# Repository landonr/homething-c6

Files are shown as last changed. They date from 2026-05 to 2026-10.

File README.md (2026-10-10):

<p align="center">
  <picture>
    <source media="(prefers-color-scheme: dark)" srcset="docs/readme-assets/homeThingLogoWhite.svg">
    homeThing logo
  </picture>
</p>

<h1 align="center">homeThing C6</h1>

<p align="center">
  A handheld remote for TV, Sonos, Zigbee lights, and Home Assistant.<br>
  Physical buttons, a rotary control, fast access, and long idle life. No touchscreen, no apps, no daily charging.
</p>

<p align="center">
  
  
  
  
</p>

<p align="center">
  <sub>Prototype and fab costs sponsored by <a href="https://pcbway.com/g/Xymq6O">PCBWay</a>. Boards arrive fully assembled, no soldering required.</sub>
  <br>
  <a href="https://pcbway.com/g/Xymq6O">PCBWay</a>
</p>

## Summary

- **Case:** The [`case/` README](case/README.md) documents the enclosure files and assembly information.
- **Board:** The [`c6remote-kicad/` README](c6remote-kicad/README.md) documents the KiCad hardware source.
- **Firmware:** The [firmware section](#firmware) documents the ESPHome configuration and local components.
- **Scripts:** The [`scripts/` README](scripts/README.md) documents project utilities and generated assets.

The prototype uses a Seeed Studio XIAO ESP32-C6.

### Features

- Control a TV with on-board IR receive and transmit hardware
- Drive music playback over Wi-Fi and BLE
- Switch lights over Zigbee, Thread, or Matter
- Map Home Assistant actions to physical buttons instead of app screens
- Assign every button from a web page on the remote itself
- Run for a long time between charges

## Case

<p align="center">
  <picture>
    <source media="(prefers-color-scheme: dark)" srcset="docs/readme-assets/remote-controls-annotated-dark.svg">
    Front of the assembled c6remote with labels for the microphone, scroll wheel and 5-way control, RGB status LEDs, 11 assignable buttons, the XIAO ESP32-C6 module with Zigbee, Wi-Fi, and BLE radios, and USB-C port.
  </picture>
  <picture>
    <source media="(prefers-color-scheme: dark)" srcset="docs/readme-assets/remote-back-annotated-dark.svg">
    Back of the assembled c6remote with labels for the IR emitter, the IR receiver window, the translucent enclosure, and the 800 mAh battery, which lasts about a month per charge.
  </picture>
</p>

<p align="center">
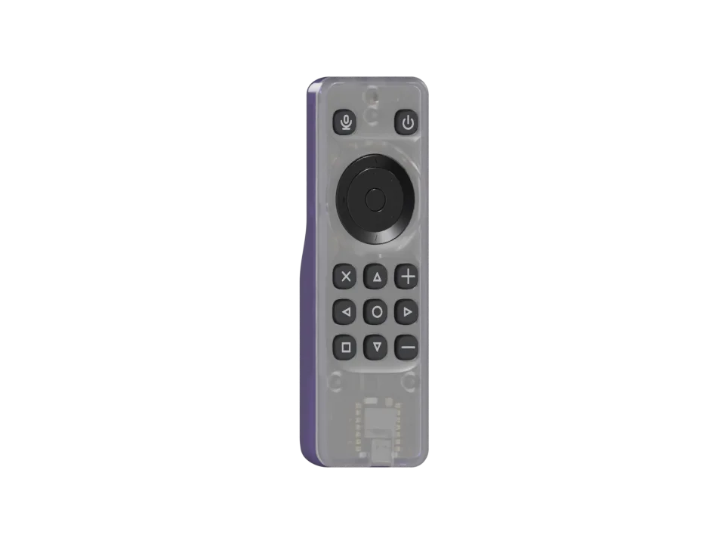
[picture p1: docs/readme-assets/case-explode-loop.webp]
The case, the pad, and the main board parts come apart. The exploded remote turns once, and then the parts go back together. The status LEDs play the boot animation
  
</p>

## Board ([more info](c6remote-kicad/README.md))

### PCB and hardware

<p align="center">
  <picture>
    <source media="(prefers-color-scheme: dark)" srcset="docs/readme-assets/board-front-annotated-dark.svg">
    Front of the c6remote board. Labels identify the ANO rotary encoder, RGB status LEDs, tactile switches, GPIO expander, and XIAO ESP32-C6 module.
  </picture>
  <picture>
    <source media="(prefers-color-scheme: dark)" srcset="docs/readme-assets/board-back-annotated-dark.svg">
    Back of the c6remote board. Labels identify the IR emitter, I2S microphone, IR receiver, 800 mAh LiPo battery, and battery connector.
  </picture>
</p>
<p align="center"><sub>PCB front and back</sub></p>

<p align="center">
  Flat copper top view
  Flat copper bottom view
</p>
<p align="center"><sub>Copper top and bottom</sub></p>

| Ref | Part | Role |
| --- | --- | --- |
| `U1` | [Seeed Studio XIAO ESP32-C6](https://mm.digikey.com/Volume0/opasdata/d220001/medias/docus/8932/102010636.pdf) | Main module: Wi-Fi, BLE, Zigbee/Thread |
| `MK1` | [DMM-4026-B-I2S-R I2S microphone](https://api.puiaudio.com/filename/DMM-4026-B-I2S-R.pdf) | Audio input: PUI Audio bottom-port MEMS part on the back copper, hearing through a 0.5mm NPTH. `LR` and `CONFIG` tie to ground for left-channel output, `C5` decouples VDD and `R12` pulls `sd` down. It replaced the ICS-43434 on 2026-09-07, after three of the five rev-B microphones failed |
| `U2` | [TSOP6136 IR receiver](https://www.vishay.com/docs/82457/tsop61.pdf) | IR receive: Vishay Panhead SMD part on the back copper, listening out the top end wall. AGC1, the most permissive of Vishay's settings, which is what lets `remote_receiver` learn arbitrary remotes. VDD sits on the switched `ir_vdd` rail rather than straight on `+3.3V`, gated by `Q3` below |
| `D1`, `Q1` | [INL-3AHIR30 IR LED](http://www.inolux-corp.com/datasheet/IR/Emitter/3mm%20Lamp/INL-3AHIR30_V1.0.pdf) driven by [MMBT2222A](https://assets.nexperia.com/documents/data-sheet/MMBT2222A.pdf) | IR transmit; D1 leads hand-bent 90° to fire through the top-edge notch (see `BEND 90°` silk mark) |
| `U3` | [PCF8575DBR I2C GPIO expander](https://www.ti.com/lit/ds/symlink/pcf8575.pdf) | Button input fan-out |
| `SW1`–`SW11` | [TL3315NF160Q tactile switches](https://www.e-switch.com/wp-content/uploads/2022/06/TL3315.pdf) | Discrete buttons |
| `ENC1` | [Adafruit ANO rotary encoder](https://cdn-learn.adafruit.com/assets/assets/000/104/942/original/tsw.pdf) | Scroll wheel: encoder channels plus five switch signals |
| `D2`–`D5` | [XL-2020RGBC-WS2812B addressable LEDs](https://mm.digikey.com/Volume0/opasdata/d220001/medias/docus/8903/5962_XL-2020RGBC-WS2812B.pdf) | Status light chain of 4, WS2812B protocol: `GPIO17` drives `D2` DIN, DOUT cascades to `D5`. VDD sits on the switched `led_vdd` rail rather than straight on `+3.3V`, gated by `Q2` below, with `C4` as the only bulk cap on the chain (see [`docs/timeline.md`](docs/timeline.md)) |
| `Q2`, `R10`, `C4` | [AO3401A P-channel MOSFET](https://www.aosmd.com/res/datasheets/AO3401A.pdf), 1M 0603 pull-up, 1µF X7R 0805 cap | LED rail load switch: high-side `Q2` gates `+3.3V` (source) onto `led_vdd` (drain) for `D2`–`D5`, gate net `led_en` on `U1` pad 11 (`GPIO18`/`D10`), driven low for rail on. `R10` pulls the gate to the source so the rail is off by default at boot while `GPIO18` floats as an input; `C4` is the mid-chain bulk cap on `led_vdd`. Cuts the ~2.0mA the LEDs burned when dark to tens of µA (calculated, not yet measured). Firmware must hold `GPIO17` low or high-impedance whenever the rail is down, or DIN pushes current into the dead rail |
| `J1` | [JST S2B-PH-SM4-TB(LF)(SN)](https://www.jst-mfg.com/product/pdf/eng/ePH.pdf) | Battery connector, PH series right-angle SMD |

The auto-generated BOM lives at [c6remote-kicad/export/c6remote-bom.csv](c6remote-kicad/export/c6remote-bom.csv). It tracks the latest repo state and is not release-validated.

### Schematic

Current schematic

## Firmware

### Button assignment

Open `http://homething-c6-xxxxxx.local/` in a browser on the same network. The page also answers at `/buttons`.
`xxxxxx` is the last six hex digits of the remote MAC address. Home Assistant shows the remote as `homeThing C6 xxxxxx`.
The page draws the remote layout. Select an input, then assign IR, Zigbee, BLE HID, or voice.
You can also clear the input. Hold `SW1` for two seconds to use the on-device assignment mode.
[`RECEIVER.md`](RECEIVER.md) documents both routes. The page has no password, so use it only on a trusted network.

<p align="center">
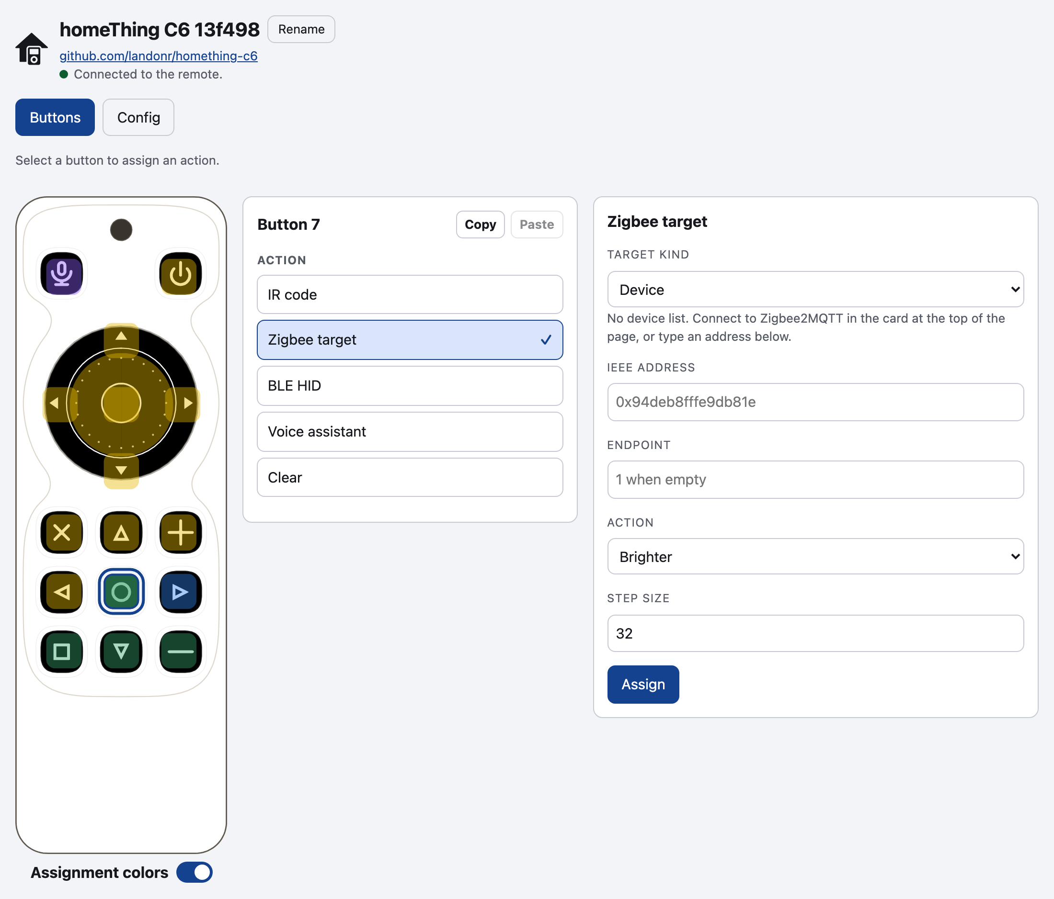
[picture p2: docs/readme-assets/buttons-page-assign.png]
The Buttons tab. Button 7 is selected and set to a Zigbee target
  
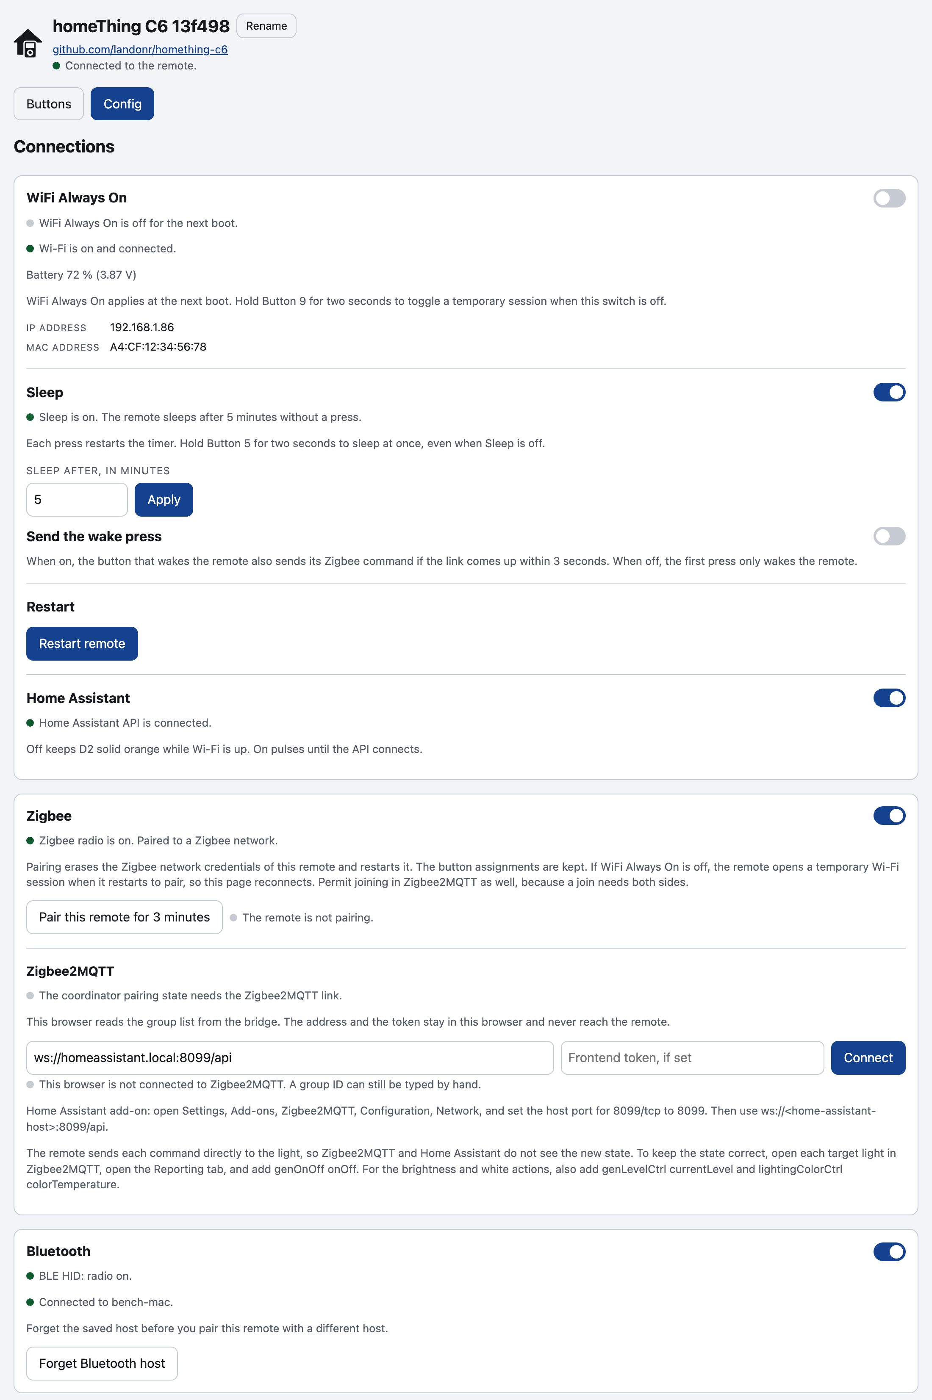
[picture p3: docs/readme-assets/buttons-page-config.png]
The Config tab with the Wi-Fi, sleep, Home Assistant, Zigbee, and Bluetooth settings
  
</p>
<p align="center"><sub>The Buttons tab with a Zigbee assignment, and the Config tab</sub></p>

## Status

The fabrication and bring-up history, the rev-B delivery, and the unit 1 versus current design comparison are in [`docs/timeline.md`](docs/timeline.md). Open work is in [`ROADMAP.md`](ROADMAP.md). The power budget is in [`docs/power-budget.md`](docs/power-budget.md).

## Relationship to homeThing

This project grew out of [homeThing](https://github.com/landonr/homeThing) but has a narrower job: instead of a general smart display, it is a simple dedicated remote. It has no screen and more buttons, and is built on a custom PCB that is easy to build.

# Includes
- <a href="https://esphome.io/">ESPHome</a>
- <a href="https://dejavu-fonts.github.io/">DejaVu Sans Bold</a>, used for the board silkscreen brand text
- [@luar123](https://github.com/luar123)'s <a href="https://github.com/luar123/zigbee_esphome">Zigbee ESPHome component</a>
- <a href="https://www.kicad.org/">KiCad</a>
- <a href="https://github.com/landonr/homeThing">homeThing</a>

# Sponsorship



## [PCBWay](https://pcbway.com/g/Xymq6O "PCBWay") sponsors 3D Printing and PCB assembly costs on this project during the prototyping phase! 
If you are interested in their awesome fabrication services please check them out.&nbsp; They offer 

3D prototyping,&nbsp;PCB design and assembly, as well as CNC metal fabrication.&nbsp; Costs are reasonable and the quality is as good as it gets.&nbsp; Thank you PCBWay for sponsoring us and other fun projects!<br><br>

## [cargo](https://cargo.site/ "cargo.site") sponsors our website!

They make it super easy to keep things pretty and up to date! It’s honestly so much easier than managing our own site, highly recommended!

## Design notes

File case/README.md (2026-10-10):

# Case

This directory contains the parametric enclosure model for the c6remote board.
The model uses [build123d](https://build123d.readthedocs.io/), so the source is Python.

<p align="center">
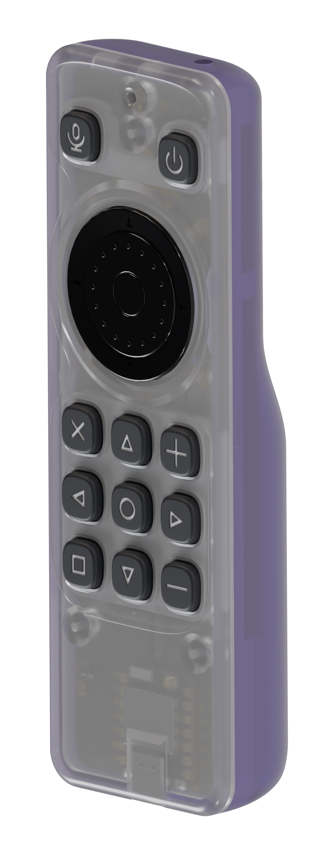
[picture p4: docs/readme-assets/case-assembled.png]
Assembled c6remote case
  
</p>
<p align="center"><sub>Assembled case</sub></p>

<p align="center">
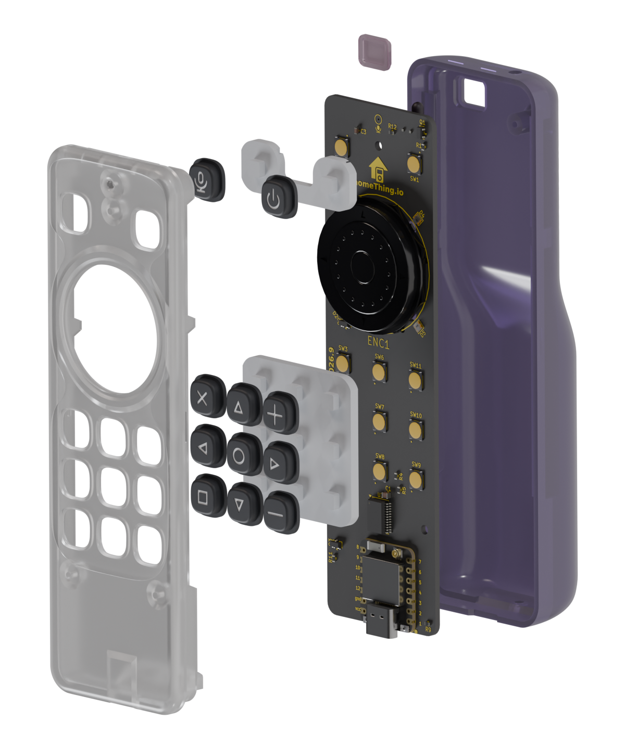
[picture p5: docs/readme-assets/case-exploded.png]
Exploded c6remote case
  
</p>
<p align="center"><sub>Front shell, caps, button pad, board, and back shell</sub></p>

<p align="center">
  The c6remote case, the pad, and the main board parts come apart. The exploded remote turns once, and then the parts go back together
</p>

The model exports a front shell, back shell, soft button pad, IR window insert, and 11 rigid caps. It also exports a blank version of each cap, `c6remote-cap-sw<n>-blank.stl`, with no legend.
It also exports an FDM button pad with all keytops and legends fused into one STL.
It also exports a second front shell for a filament printer. Read [FDM front](#fdm-front).
It also exports the V2 top pads, an FDM one and a one-piece TPU one, for a V2 board. Read [V2 retention post](#v2-retention-post).

## Setup

Run these commands from the repository root:

```bash
cd case
uv venv --python 3.12 .venv
uv pip install --python .venv/bin/python -r requirements.txt
```

## Build and validate

Run these commands from the repository root:

```bash
scripts/export-case-refs.sh
case/.venv/bin/python case/board.py
case/.venv/bin/python case/case.py
case/.venv/bin/python case/check.py
```

Use a scoped check during development:

```bash
case/.venv/bin/python case/check.py --only ir
case/.venv/bin/python case/check.py --only support,shells
```

Run the full check before you accept a case change. A scoped check does not validate the full model.

Run independent feature groups in parallel when two or more groups are selected:

```bash
case/.venv/bin/python case/check.py --jobs 4
case/.venv/bin/python case/check.py --only ir,support --jobs 2
```

Use `--quiet` for failures, provenance, counts, and the scoped-run warning. Use `--timings` to print pass durations.

Every run also writes `export/c6remote-checks.json`: the same report in machine form, with each failure's own point or box in the case frame where the pass recorded one. Use `--json PATH` to write it somewhere else. The c6remote-explode viewer reads that file and draws the failures on the model, so a scoped run writes only the features it ran and marks itself scoped.

A pass says where a failure is by appending a `checks.common.Problem` instead of a plain string; a plain string still reports, it just cannot be drawn.

Use this command to preview the model:

```bash
case/.venv/bin/python case/case.py --show
```

The preview requires `ocp-vscode`:

```bash
uv pip install --python case/.venv/bin/python ocp-vscode
```

Without `ocp-vscode`, use the exploded viewer instead:

```bash
../c6remote-explode/preview-case.sh
```

That script lives in the viewer checkout. It builds the STL files, copies them into the viewer's draft geometry set, and opens the viewer.
It omits the feature map and the summary, so a draft build takes about 6 seconds on a warm cache.

## Board inputs

Do not copy a board coordinate into the case model. Add a reader to `board.py` instead.

The model reads these sources:

- `c6remote-kicad/c6remote.kicad_pcb` supplies the outline, mounting holes, courtyards, wheel center, and microphone port.
- `c6remote-kicad/export/c6remote-pos.csv` supplies component positions.
- `case/board/c6remote-board.step` supplies component bodies, keepout heights, and connector geometry.
- `case/board/c6remote-board-only.step` supplies the board solid.
- `case/board/c6remote-outline.dxf` supplies the exported outline.
- `case/board/c6remote-v2-board-only.step` supplies the fixed V2 mounting-hole reference.
- `case/board/c6remote-v2-pos.csv` supplies the fixed V2 switch positions.

Run `scripts/export-case-refs.sh` after a relevant schematic or board change. Then build and run the full check.

Do not regenerate `case/board/c6remote-v2-board-only.step` or `case/board/c6remote-v2-pos.csv`. Both are static references from release `2026.8.0`, commit `d0a2c2e`.

## Coordinate frame

The X axis is the KiCad board X axis. The Y axis is the negative KiCad board Y axis.

The Z origin is the bottom face of the board. Positive Z points toward the front shell.

The position CSV already contains the negative Y coordinates. Do not apply a second Y transformation.

## Parameters

Put all adjustable geometry values in `params.py`. Give each value a short rationale in its docstring.

The model derives geometry from the board where possible. Manual values include switch travel, switch height, print fits, and material thicknesses.

`SWITCH_HEIGHT` and `SWITCH_TRAVEL` are not measurements. Measure a physical TL3315 before the first production print.

## Materials

Print the shells with a tinted translucent filament. The STL files contain no color or material data.

The IR window material must transmit 940 nm infrared light. Test the selected filament with a physical remote.

If the shell filament blocks too much infrared light, make the same insert from IR-pass acrylic.

Prototype the button pad in TPU. Use translucent silicone for a molded part.
The molded pad has a skirt on the outer edge of each lobe. The skirt is `PAD_SKIRT_T` wide and its bottom is level with the plunger contacts, so the pad stands level on the plungers and the skirt.
The skirt has a break over each board part that it would otherwise touch. `PAD_SKIRT_CLEARANCE` sets the gap.
The molded pad and the one-piece TPU pad have a plain web without isolation grooves. Only the FDM pad has grooves.

`c6remote-case-pad-tpu.stl` goes with the recessed front `c6remote-case-front.stl`. Print it in TPU as one piece in place of the TPU pad and the PETG caps. Do not install separate caps with it.

For keytops with no legend, print `c6remote-case-pad-tpu-blank.stl` in place of `c6remote-case-pad-tpu.stl`.
It is the FDM pad with the same skirt as the molded pad. It has no edge chamfer, because TPU flexes on its own. Its grid web is a plain slab with square edges.

Print the caps in translucent PETG or PLA. Either orientation works. For a key with no legend, print `c6remote-cap-sw<n>-blank.stl` in place of `c6remote-cap-sw<n>.stl`. The blank cap has the same fit.

The cap flange rests on the pad web, so a press moves the cap and the web together. `CAP_LIFT` sets any air under the flange.

Top faces against the build plate gives the best finish. Top faces up needs support on the top faces. Trim the support marks after the print.

For a rigid FDM button set, print `c6remote-case-pad-fdm.stl`. It includes the
two pad lobes and all 11 keytops in one STL. Each keytop is flush with its lobe
web. Do not install separate caps with it.

Print the FDM pad in either orientation. The STL exports with the keytops up.

Keytops down puts the keytop faces on the plate. The pad then stands on 523 mm2.

Keytops up puts the pad on the keytop stems. The pad then stands on 26 mm2. Use a brim and a clean plate. Set the support roof density to 80 percent, or the web sags into the support. Trim the support marks after the print.

The FDM pad cuts its isolation grooves from the keytop side only. As a result, the web underside is flat, and the supports for a keytops-up print come off easily.

The chamfer on both lips of each groove and on the grid lobe outer top edge runs down to the groove floor, set by `FDM_PAD_GRID_CHAMFER`.

If you print keytops down, the grooves face the support. Then the supports fill the grooves and are hard to remove.

## FDM front

The export contains two front shells. Both shells have the same interior, so the caps, the pad, and the back shell fit either one.

`c6remote-case-front.stl` is the recessed front. Its face carries a shallow dish around the keys and around the wheel.

`c6remote-case-front-fdm.stl` is the FDM front. Its face is one flat plane and carries the same dish outline as a shallow groove.

Use `c6remote-case-pad-fdm.stl` with this front. The keytops have no captive
flanges, so install this pad from inside before the board. The face holes guide
the integrated keytops with `FDM_CAP_GUIDE_CLEARANCE` on each side.

Print a front shell with its face against the build plate. A filament printer cannot make the dish in this orientation.

The dish floor is a wide, almost horizontal ceiling a fraction of a millimetre above the plate. The printer must support it.

Support under the face marks the one cosmetic surface on the case. The other orientation stands the whole cavity on its ceiling.

The groove is narrow, so the layer above it bridges the gap in one span. The FDM front needs no support on its face.

The FDM front's face sits `FDM_FACE_DROP` below the recessed front's, so the part is slimmer than a flat face at the raised level.

The caps and the wheel stand proud by that much. The recessed front stands its caps proud of the dish by `CAP_PROTRUSION` plus the local dish depth.

The drop thins three ceilings that the dish never reaches. The USB pocket roof is the tight one, and `check.py --only fdm` holds all three.

The USB pocket roof and the USB slot roof are flush, at the connector envelope plus `USB_CLEARANCE`. Do not raise one without the other.

The groove follows the dish rim exactly. The outline on the two fronts is the same line.

The FDM front has a 0.64 mm, 45 degree top-edge chamfer. The recessed front keeps its round.

The rim runs inside the recessed front's round. The FDM front keeps its groove on flat face outside the chamfer.

`FDM_FACE_DROP`, `FDM_OUTLINE_W`, `FDM_OUTLINE_DEPTH`, `FDM_OUTLINE_EDGE_CLEAR`, and `EDGE_R_FRONT_FDM` set the face. The LED ring channel is half-depth on this front, leaving a thicker printable roof. Run `check.py --only fdm` to validate it.

## Assembly

The front shell holds the board. Three M2 screws fasten the V3 board to its bosses.

The back lap closes over the front skirt. Two detents secure the IR end.
Two hidden side catches keep the long seams closed near the board midpoint.
Their front-skirt pockets are blind, rounded, and bevelled at the mouth, with
continuous material behind them. The seam sits above the board top.
Each pocket sits a short lower lip above the front skirt's support relief, so a long solid skirt land stays above each catch.
The support relief stands `SUPPORT_SKIRT_FIT` above the ledge tops, so the front skirt never lands on a ledge. The seam shoulder is the only vertical stop.
The back detents ramp on both sides so the shells can be opened for service.
Each back detent sits lower than its pocket and bears on the lower lip with a light preload.
The preload holds the seam closed.
`SIDE_CATCH_LOWER_LAND` sets the lower lip height, and `SIDE_CATCH_PRELOAD` sets the preload.

One M2 x 6 screw secures the grip end. It enters horizontally through the back shell's negative Y end wall and threads into a block behind the front skirt. The case uses four M2 x 6 screws in total and no long screw.

Prepare the back shell first:

1. Insert the IR window from inside the back shell.
2. Make the pane flush with the outside surface.
3. Apply adhesive to the continuous shoulder below the interior flange.
4. Let the adhesive set.

Assemble the remaining parts with the front face down:

1. Install all caps in the front shell.
2. Install the button pad.
3. Put the board on the front-shell bosses.
4. Install the three M2 screws through the board into the front-shell bosses.
5. Engage the two IR-end detents.
6. Fold the back shell onto the front shell.
7. Install the end-wall M2 screw at the grip end.

Install the caps before the pad. The caps are captive after pad installation.

For the FDM pad, omit step 1 and install `c6remote-case-pad-fdm.stl` in step 2.

Install the IR window before shell assembly. Its flange is not accessible after shell assembly.

## V2 retention post

The back shell includes one retention post for a V2 board. The post uses the V2 upper-right mounting hole.

This post supplies retention only. It does not make the V2 board compatible with the V3 case.

The V2 IR parts and upper keys do not align with the current openings. Use this feature only as a bench aid.

For a V2 board, fasten the board to the back shell first. Drive the M2 screw from the component side without a washer.

The V2 board sits on the post, `SUPPORT_GAP` lower than the V3 board. Its SW1 and SW2 also sit nearer the grip end.

For a V2 board, print `c6remote-case-pad-fdm-v2-top.stl`. Use it in place of the SW1 and SW2 lobe of `c6remote-case-pad-fdm.stl`.

The V2 top pad keeps the V3 SW1 and SW2 plungers. It adds one nib above each V2 switch.

Each nib extends `LEGACY_NIB_EXTENSION` below the V2 switch top. The kept V3 plungers use the same extension below the V3 switch top, so they stop above the nibs.

The SW1 and SW2 keytops of the V2 top pad stand level with the other keys.

Use the V2 top pad only with a V2 board. On a V3 board, the nibs land on the V3 switch bodies.

For the one-piece TPU pad on a V2 board, print `c6remote-case-pad-tpu-v2-top.stl`. On a V2 board, it replaces the SW1 and SW2 lobe of `c6remote-case-pad-tpu.stl`. Use it with the recessed front `c6remote-case-front.stl`.

`c6remote-case-pad-tpu-v2-blank.stl` is a complete V2 pad with blank keytops in one STL. Print it alone, with the recessed front `c6remote-case-front.stl`.

Its skirt ends level with the skirt of `c6remote-case-pad-tpu.stl`, so both lobes stand on one plane. Its skirt breaks come from the V3 part bodies, moved to the V2 placements, and from the V2 screw head.

For the moulded pad with separate caps on a V2 board, print `c6remote-case-pad-v2-top.stl`. Use it in place of the SW1 and SW2 lobe of `c6remote-case-pad.stl`, with the standard caps and the recessed front `c6remote-case-front.stl`. Its stems stay at the V3 SW1 and SW2 positions, so the standard caps fit it unchanged.

Print the FDM V2 top pad with the keytops down. The nibs extend below the plungers, so the part cannot stand level on its plungers.

On the first print, make sure that SW1 and SW2 operate and do not bind. Each V3 plunger overlaps the edge of a V2 switch body.

`SWITCH_HEIGHT` is also not a measurement, so the nib engagement is not confirmed.

## IR openings

`U2` receives infrared light through the back face along negative Z. Its opening includes the receiver body and lead envelope.

The IR window insert enters this opening from inside. Its exterior pane must be flush with the back shell.

`D1` emits through the positive Y end wall. The emitter uses a separate bare bore.

## Functional constraints

- Keep the button caps captive behind the front-shell ceiling.
- Keep the button pad clear of the wheel and the four wheel LEDs.
- Keep the pad skirt clear of board parts.
- Keep the LED ring channel open below its translucent roof.
- Keep the microphone funnel aligned with the board port.
- Keep the USB slot and pocket clear of the connector shell.
- Keep support ledges clear of board parts, screw heads, and the cell.
- Keep the front skirt clear above the support ledge tops.
- Keep the end screw block clear of the back shell. Its web ties it to the end skirt and the side skirt at skirt height only.
- Keep the IR window shoulder continuous for adhesive.
- Keep the front and back shell mating volumes separate. The side catch preload is the only exception. The checks allow this overlap only at the lower pocket lip.

The checks must probe built geometry. A check must not only repeat the formula that creates the feature.

After a loft or sweep change, inspect the exported STL. A valid BREP can still produce a damaged mesh.

## Validation

`check.py` validates these groups:

- Apertures and end ports
- Button caps, legends, pad fit, and switch contact
- Wheel clearance and the LED light path
- Microphone and USB geometry
- IR receiver clearance and window installation
- Board supports, screws, cell clearance, V2 retention, and the V2 top pad
- Shell mating and component interference
- FDM front face flatness, height, top edge round, and outline groove
- Solid validity and closed STL meshes

Run the full validation before export:

```bash
case/.venv/bin/python case/check.py
case/.venv/bin/python case/case.py
```

The model writes STLs and metadata to `case/export/`. `case.py` prints current dimensions and screw lengths.

If the exported assets change, push them into the external viewer:

```bash
../c6remote-explode/preview-case.sh --full
```

That script builds again on the warm cache and copies the result into the viewer's draft geometry set.
Its `--baseline` mode rebuilds the committed geometry that the viewer's diff view compares against.

## Development rules

Use the public build123d API. Do not use raw OCP objects unless build123d has no equivalent.

When you add a check, change a related parameter temporarily. Confirm that the new check fails with a useful message.

For a refactor, compare the full check output and exported artifact hashes before and after the change.

The STL cache absorbs one known nondeterministic tessellation result in the back shell. Use `CASE_NO_CACHE=1` only when necessary.

## Files

| Path | Purpose |
| --- | --- |
| `params.py` | All adjustable geometry values |
| `board.py` | Readers for KiCad and board export geometry |
| `case.py` | Thin build and export entry point |
| `check.py` | Thin validation entry point |
| `cache.py` | Geometry and STL cache |
| `model/` | Case feature builders and export metadata |
| `checks/` | Validation modules for built geometry |
| `fonts/` | Vendored legend font and license |
| `glyphs/` | SVG legend centerline strokes |
| `board/` | Generated board references and the fixed V2 reference |
| `export/` | Generated STLs and JSON metadata |

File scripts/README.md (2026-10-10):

# Scripts

## Draft preview in 3D

Run this command from the repository root to see the current case model in the exploded viewer:

```bash
../c6remote-explode/preview-case.sh
```

The script lives in the viewer checkout. It builds the STL files, copies them into the viewer, and opens it.
If the viewer already runs, the script says so. Reload the tab.

The default build is a draft. It skips the feature map and the summary.
As a result, Identify reports the boxes from the last complete build.
Use `../c6remote-explode/preview-case.sh --full` to write the feature map again.

Both of those builds read the working tree. They write the draft geometry set.
Use `../c6remote-explode/preview-case.sh --baseline` to rebuild the committed geometry that the viewer's diff view compares against.
That mode builds git HEAD in a temporary worktree. It does not touch the working tree.

Run `scripts/export-case-refs.sh` first after a board change.
The script reads the board exports, but it cannot detect a KiCad change.

Set `REPO` for a board checkout outside `~/dev/homething-c6`.
Set `PORT` for a server port other than 8731.

## Preview assets

Run these commands from the repository root to regenerate the case preview assets:

```bash
./scripts/render-readme-assets.sh
../c6remote-explode/scripts/render-case-assembled.sh --blender
../c6remote-explode/scripts/render-case-exploded.sh --blender
../c6remote-explode/scripts/render-case-explode-loop.sh
```

Every 3D render uses Blender's Cycles.
`render-readme-assets.sh` needs Blender. Set `BLENDER` to override the binary path.
It exports a board GLB from the PCB and renders the two `board-3d-rotated-*.png` views with `scripts/render-board-blender.py`. It writes them into `docs/readme-assets/`.
`scripts/board_extras.py` builds the J1 socket, the battery plug, and the battery for the Blender scripts. The `c6remote-explode` repository also uses it.
`scripts/assets/env-studio.hdr` is the Poly Haven `studio_small_09` HDRI at 1k. Its license is CC0.
The three case scripts use the sibling `c6remote-explode` checkout. Set `C6REMOTE_EXPLODE` if that checkout is not at `../c6remote-explode`.
The case scripts need Node, `ffmpeg`, and `img2webp` (`brew install webp`) as well. They render the case geometry the viewer has, so run `../c6remote-explode/refresh-assets.sh` after a case or board change.
Add `--rig` to a case script to render on the Windows Rig over SSH.
The case scripts write dated files into `c6remote-explode`; copy them into `docs/readme-assets/` as `case-assembled.png`, `case-exploded.png`, and `case-explode-loop.webp`.

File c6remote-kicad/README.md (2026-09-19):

# KiCad project

## Open the project

Open `c6remote.kicad_pro` in KiCad.
KiCad must resolve `../kicad lib/Library.pretty/` with the `Library` nickname.

The `sym-lib-table` file registers these symbol libraries:

- `ano rotary`: The local `ano rotary.kicad_sym` file contains the [Adafruit ANO rotary encoder](https://www.adafruit.com/product/5001) symbol.
- `Seeed_Studio_XIAO_Series`: [Seeed Studio's OPL KiCad library](https://github.com/Seeed-Studio/OPL_Kicad_Library/tree/master/Seeed%20Studio%20XIAO%20Series%20Library) supplies the XIAO module symbols.

The `3dmodels/` directory contains the board models.
See the [3D model sources](3dmodels/README.md) for the source of each file.

## KiCad MCP

The repository uses the same KiCad MCP server with Codex and GitHub Copilot in VS Code:

- Codex workspace configuration: `../.mcp.json`
- VS Code workspace configuration: `../.vscode/mcp.json`

## Validation and fabrication

### Schematic-only agent workflow

Run this workflow from the repository root.
Use a unique session name for each schematic or custom-footprint edit loop.
The PCB must remain unchanged between `preflight` and `verify`.

```bash
./scripts/hw.py doctor
./scripts/hw.py preflight my-edit

# Inspect the baseline before an edit.
./scripts/hw.py inspect my-edit component U3
./scripts/hw.py inspect my-edit net sda
./scripts/hw.py inspect my-edit pin U3 14

# Run after every schematic or custom-footprint edit.
./scripts/hw.py quick my-edit

# Inspect the refreshed state and all baseline changes.
./scripts/hw.py inspect my-edit changes

# Run once before handoff.
./scripts/hw.py verify my-edit
./scripts/hw.py clean my-edit
```

Native KiCad ERC is authoritative.
Semantic analysis detects topology, BOM, metadata, findings, and custom-footprint regressions.

Use `--json` with `inspect` for stable structured output.
Use `--force` with `quick` or `inspect` to bypass reusable analysis.

Session artifacts stay in `.cache/hw/<session>/`.
The `preflight` command does not replace an existing session.
Reuse one session for repeated `inspect` and `quick` commands.
The session keeps its original baseline until you run `clean`.
If a session is old or incomplete, run `clean` and `preflight` again.

The tool refreshes stale inspection data before it prints results.
It reuses validated analysis and changed-footprint data when all fingerprints match.
It does not reuse failed or incomplete output.
It rejects simultaneous operations on one session.

The tool resolves `kicad-cli` from `KICAD_CLI`, `PATH`, or the macOS application bundle.
It resolves the analyzer from `KICAD_HAPPY_DIR`, shared, Codex, or Claude skill locations.
An invalid override stops discovery.
The `doctor` command prints each selected path.
The analyzer must emit schema 1.4.x.

If the analyzer is missing or incompatible, move or remove its existing destination.
Then install the pinned version:

```bash
python3 "${CODEX_HOME:-$HOME/.codex}/skills/.system/skill-installer/scripts/install-skill-from-github.py" --repo aklofas/kicad-happy --ref v2.2.0 --path skills/kicad
```

Exit code `0` means pass.
Exit code `1` means a design regression.
Exit code `2` means a tooling or configuration failure.

A PCB change makes `quick` and `inspect` fail before analysis starts.
The message explains that the session cannot validate PCB edits.
The `quick` command blocks only new deterministic analyzer errors.
The `verify` command always runs fresh native checks and stores outputs in the session cache.

### Native checks

Run these commands from this directory:

```bash
# Schematic ERC
/Applications/KiCad/KiCad.app/Contents/MacOS/kicad-cli sch erc c6remote.kicad_sch --exit-code-violations

# Board DRC
/Applications/KiCad/KiCad.app/Contents/MacOS/kicad-cli pcb drc c6remote.kicad_pcb --exit-code-violations

# Full board DRC with schematic parity and zone refill
/Applications/KiCad/KiCad.app/Contents/MacOS/kicad-cli pcb drc c6remote.kicad_pcb --schematic-parity --refill-zones --exit-code-violations
```

### Fabrication outputs

Regenerate all Gerber, drill, position, and BOM files in `export/`:

```bash
../scripts/regen-fab.sh
```

Regenerate only the BOM after you edit symbol sourcing fields:

```bash
../scripts/export-bom.sh
```

Use this script instead of the KiCad MCP `export_bom` tool.
The MCP tool uses a different schema and removes the custom sourcing columns.

### Board renders

Render reusable 2D board views in `renders/<format>/`:

```bash
../scripts/render-2d.sh
../scripts/render-2d.sh --side top
../scripts/render-2d.sh --side bottom --format pdf
```

### Interactive BOM

Generate the interactive HTML BOM for the pre-fabrication pin-1 check:

```bash
../scripts/gen-ibom.sh
```

The command writes the ignored `ibom.html` file in this directory.
The pre-commit hook also updates it when you stage `c6remote.kicad_pcb`.

Complete the [pre-fabrication checklist](../docs/pre-fab-checklist.md) before you order a board.

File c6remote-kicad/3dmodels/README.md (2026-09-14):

# 3D model sources

Models the project footprints reference through `${KIPRJMOD}/3dmodels/`. Every file's origin, so a replacement starts from the same source rather than a guess.

- `5221 ANO Rotary Encoder.step`: [GrabCAD, Adafruit 5001 ANO Rotary Encoder](https://grabcad.com/library/adafruit-5001-ano-rotary-encoder-1). The source assembly includes a PCB. This file keeps only the `Encoder` solid so the board does not sit inside the c6remote PCB.
- `DMM-4026-B-I2S-R.STEP`: user-provided PUI Audio model from `DMM_4026_B_I2S_R (1).zip`, received 2026-09-07. The bottom footprint uses X=270, Y=0, and Z=180 degrees so the package projects away from the PCB.
- `Seeed Studio XIAO ESP32-C6.step`: [GrabCAD, Seeed Studio XIAO ESP32-C6](https://grabcad.com/library/seeed-studio-xiao-esp32-c6-1).
- `TL3315NF160Q.wrl`: modelled for this repo from the E-Switch TL3315NF160Q datasheet drawing (4.5 x 4.5 x 0.55 gold snap dome), replacing a wrong 5mm PTS647 model; see commit 8757cb5.
- `TSOP6136.step`: Vishay doc 82826, re-exported already rotated into place, so the footprint's `offset` and `rotate` are all zero on purpose; do not "fix" them.
- `TSOP6136TT.step`: derived from the checked-in Vishay doc 82826 `TSOP6136.step`, rotated into the TT top-view attitude. Lead bend is approximate; body envelope is exact. Footprint offset and rotation stay zero.
- `WS2812C-2020.step`: [Printables model 1760436, WS2812B-2020 / WS2812C-2020](https://www.printables.com/model/1760436-ws2812b-2020-ws2812c-2020). Stands in for the XL-2020RGBC-WS2812B on D2-D5, same 2.0 x 2.0 package; the KiCad stock library carries no 2020-size WS2812 model.

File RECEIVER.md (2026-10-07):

# Assignment mode

## Goal

Assignment mode gives each supported input one active action. An action can be
an IR code, a Zigbee command, a BLE HID control, the voice assistant, or no action.

Store assignments in flash. Outside assignment mode, an input replays its active
action.

## Enter and leave the mode

Hold `SW1` for two seconds to enter assignment mode. Hold `SW1` for two seconds
again to leave it.

The ready state closes after five seconds without an input.

The release that ends an `SW1` hold does not count as a tap.

## Assignment cycle

For `SW2`, `SW3` through `SW11`, and the five wheel directions, tap the same
input in this order:

1. First tap: train an IR code.
2. Second tap: assign the voice assistant.
3. Third tap: clear the input.

For `SW1`, tap the same input in this order:

1. First tap: train an IR code.
2. Second tap: clear the input.

`SW1` has no voice stage because its hold gesture controls assignment mode.

The cycle has no Zigbee stage. A Zigbee target comes from Zigbee2MQTT, which
the remote cannot read, so only the web page assigns one.

Clockwise and anticlockwise wheel rotation are IR-only. Each detent starts IR
training. Rotation has no voice or clear stage because it has no release edge.

A tap on a different supported input always starts at the IR stage for that
input.

## IR training

After the first tap, point the source remote at `U2` and press its button once.
The remote accepts the first complete frame and stores it as raw pulse data.

The remote rejects empty, truncated, oversized, and repeat-only frames. A failed
capture does not replace the old assignment.

## Zigbee assignment

Assign a Zigbee target from the web page. Read [ZIGBEE.md](ZIGBEE.md) first,
because you must create a group in Zigbee2MQTT before the remote can use it.

Outside assignment mode, an assigned input sends its one Zigbee command to its
target. Playback needs no MQTT and no Wi-Fi.

## Clear and replace an assignment

An IR, Zigbee, BLE HID, or voice assignment replaces the previous action for that input.
The remote never keeps two active actions on one input.

The clear tap removes the local assignment. Group membership stays in
Zigbee2MQTT, because the group belongs to the network, not to the button.

If an IR capture fails, the old assignment remains.

## Web configurator

The device serves a button page at `http://homething-c6-xxxxxx.local/`. The page also answers at `/buttons`.
`xxxxxx` is the last six hex digits of the remote MAC address. The page uses
the `web_server_base` server on port 80. The production config has no ESPHome `web_server` entity page.

The page title shows the friendly name of the remote, for example `homeThing C6 xxxxxx`.
To change the name, select **Rename** beside the title. Type the name, then select **Save** or press Enter.
To close the box without a change, press Escape or select **Cancel**.

A name can have a maximum of 40 bytes. A character that is not ASCII uses more than one byte.
A name cannot contain a slash or a control character.

Rename changes only the friendly name. The hostname and the page address stay the same.
As a result, the mDNS link and the Home Assistant connection continue to operate.
Home Assistant shows the new name when it next connects. The mDNS record shows it after the next restart.
If you save an empty name, the remote uses its default name again.

The Bluetooth device name is also the friendly name. If no host is connected, the advertisement shows the new name at once.
A paired Bluetooth host can show the old name until it pairs again.
The GAP device name always holds the complete name. The advertisement and the scan response can hold a shortened name.

The page draws the remote layout: the two top buttons, the wheel, and the nine
keypad buttons.

Select an input. The page shows the current assignment, then an **Action**
selector with the actions that the input accepts.

The selector holds IR code, Zigbee target, BLE HID, Voice assistant, and Clear. It opens
on the action that the input already holds.

The right side of the selected-input title has **Copy** and **Paste** buttons.
Use them to copy an IR code, Zigbee target, or BLE HID configuration between inputs.

Select the source input and select **Copy**. Then select the target input and
select **Paste**. Paste opens the IR or Zigbee panel and fills its configuration
form. Paste does not write an assignment to the remote.

Paste stays available for a Clear or empty input when copied configuration exists.
Select **Apply** for IR or **Assign** for Zigbee and BLE HID to write the configuration.

One panel shows at a time, because an input holds one action. The IR panel owns
the **Record IR** button and the code box.

The page is an alternative to the tap cycle, not a replacement. Both routes write
the same flash records.

The page also has a **Sleep** block for the deep-sleep settings. See [Deep sleep](#deep-sleep).

The header of the page has a connection line. It shows if the page can read
the remote. If two reads in a row fail, or one read gets no answer in time, the
line turns red and a banner stays at the top of the page. Changes on the page do
not get to the remote while the banner shows. The banner goes away when the
remote answers again.

### Assign a Zigbee target from the page

The page can assign a Zigbee target and the command that goes to it. It does
not need a state transition, because you name both instead.

1. Select an input, then select **Zigbee target** in the Action selector.
2. On the first use, enter the Zigbee2MQTT frontend websocket address in the
   connection card at the top of the page.
3. Select **Group** or **Device**, then pick a target or type its address.
4. Select the command in the **Action** selector, then fill its value box if it
   shows one.
5. Select **Assign**.

The browser reads the group and device lists from Zigbee2MQTT and sends only the
address, the action and its value to the remote. The address of the frontend and
the token stay in browser storage.

The remote holds no MQTT client, so the retained `bridge/devices` payload that
once exhausted its heap never reaches it.

The **Action** selector lists only the commands the target accepts, which the
page reads from the cluster list of the target. A typed address describes
nothing, so it offers every command.

A device target unicasts to the device, so the browser writes no group for it.

Use a typed address when the browser cannot reach the frontend.

The browser fills the list from the `bridge/groups` message on the Zigbee2MQTT
frontend websocket. If it cannot connect, the page reports the reason and keeps
the typed field usable.

The remote stores the group ID at once, because a group needs no confirmation
from the network.

Read [ZIGBEE.md](ZIGBEE.md) for the accepted group ID formats.

### Assign a BLE HID control from the page

1. Pair the host with the remote in its Bluetooth settings. The remote uses its friendly name, for example `homeThing C6 xxxxxx`.
   While the remote waits for a host, `D4` pulses blue. After the host pairs, `D4` is solid green.
2. Select an input, then select **BLE HID** in the Action selector.
3. Select Keyboard, Consumer, Gamepad button, or Gamepad D-pad.
4. Select the key from the list. Keyboard and Consumer list the common usages by name.
5. If the usage is not in the list, select **Custom usage** and enter the number.
6. Select the modifier keys to hold with the key, when applicable.
7. Select **Assign**.

A gamepad button still takes a number. A D-pad still takes a direction.

The remote supports one bonded host. Pairing uses encrypted Secure Connections with Just Works authentication.

The firmware uses the NimBLE host. After the link is encrypted, the remote reads
the host device name from the GAP service, `0x1800`, characteristic `0x2A00`.

The page then names the host. A host that hides that characteristic keeps the
plain connected state.

Flash the first BLE HID build through USB because this build changes the partition table. Later builds can use OTA.

The page shows the connection, bond, and pairing states above the input layout.

The remote sends no HID action while the host is disconnected. It does not queue missed actions.

The remote combines held keyboard keys, keyboard modifiers, and gamepad buttons in their reports.

Each wheel detent sends one short HID press and release.

### Capability matrix

| Input | Slots | Record IR | Zigbee target | BLE HID | Voice assistant | Clear |
| --- | --- | --- | --- | --- | --- | --- |
| `SW1` | 20 | Yes | Page only | Page only | No | Yes |
| `SW2` | 19 | Yes | Page only | Page only | Yes | Yes |
| `SW3` to `SW11` | 3 to 11 | Yes | Page only | Page only | Yes | Yes |
| Wheel directions | 12 to 16 | Yes | Page only | Page only | Yes | Yes |
| Wheel rotation | 17 and 18 | Yes | Page only | Page only | No | Yes |

Every slot accepts a Zigbee target from the page. Zigbee playback uses the same
press handler as IR playback, so a wheel detent can send it. A command that only
makes sense as a pair, such as brighter and dimmer, costs two slots, and the
wheel directions are the natural home for one.

`SW1` has no voice action because the hold gesture owns its press edge.

Wheel rotation has no voice action because a detent has no release edge to end
push-to-talk.

The page hides the voice button on those three slots. The firmware checks the
same rule again on each request.

A voice request for slot 17, 18, or 20 gets HTTP 400 and changes nothing.

### One operation at a time

The remote runs one assignment operation at a time. The page polls
`/buttons/api/state` for the current owner.

If the remote owns the operation, the page disables its action buttons. The
notice reads "Assignment in progress on the remote."

If a second browser owns the operation, the notice reads "Another assignment is
already running."

A request that arrives during an operation gets HTTP 409. The remote keeps its
current operation.

A web operation looks like a local one on the remote. `D3` and `D4` show the same
ready state and IR training state.

The remote gesture stays active during a web operation. A tap on the remote can
move the capture to another input.

### A failed or cancelled capture

The store keeps the previous assignment after a failed capture. A rejected frame
writes nothing to flash.

Cancel gives the same result. The page sends the `cancel` action and the remote
closes assignment mode.

If no frame arrives, the capture times out. The page then reports "No code
received" and the old assignment remains.

To replace an assignment, record again or select a different action.

### Copy a code by text

Each input has an "IR code" box on the page. The box holds one Flipper `.ir` signal block.

`GET /buttons/api/code?slot=<n>` returns that block. The Apply button posts it back as the `code` field.

A Samsung32 frame prints as a parsed block:

```
name: Power
type: parsed
protocol: Samsung32
address: 07 00 00 00
command: E6 00 00 00
```

Every other frame prints as a raw block with `frequency`, `duty_cycle`, and a `data` line of durations in microseconds.

The `name` line names the code. The page shows that name on the input tile.

A paste can hold a whole Flipper-IRDB file. The parser reads the first signal and ignores the rest.

The parser also accepts a bare list of signed microsecond values, which is the format that earlier builds copied out.

The board transmits at 38 kHz with 50 percent duty, so it ignores the `frequency` and `duty_cycle` lines of a pasted block.

### The connection card

The page opens with one connection card. It holds both radio links, side by side
with a rule between them. It sits above the input grid, separate from the import
block. On a narrow screen the two blocks stack.

Each block keeps every line and every control on the page at all times. A line
that hides moves the text and the buttons under it, so a state is written out
instead. A control that does not apply is disabled, not removed.

The **Zigbee** block starts with the radio switch and its line. The pairing text
and the pairing button come next, with the pairing line to the right of the
button. A rule then separates that from the **Zigbee2MQTT** heading, because the
link below it belongs to this browser.

The **Zigbee2MQTT** part holds the address, the token, the **Connect** button,
and its own line below them.

The line below the address and the token reports the link of this browser, with
a circle:

- A green circle and the group and device counts mean a live link.
- A grey circle means no connection.
- A red circle means that the last connection failed.

The two are independent. This browser can hold a live link while the radio of the
remote is off, so each line says which one it describes.

The Zigbee2MQTT block also reports the coordinator pairing window. The line
reads "Pairing is closed on the coordinator. Permit joining in Zigbee2MQTT." or
"Pairing is open on the coordinator for 2:54." with a live countdown from the
retained `bridge/info` message.

That line is read only. The page publishes nothing to Zigbee2MQTT.

If the socket is down, the line reads "The coordinator pairing state needs the
Zigbee2MQTT link."

The pairing button belongs to the remote and sits above the rule, under the
radio line. It reads **Pair this remote for 3 minutes** and posts to the remote,
which turns its radio on and restarts to open the window. While the window is
open the button reads **Stop pairing** and the line counts the window down.

A join needs both sides. Open the coordinator in Zigbee2MQTT and the remote with
this button. See `ZIGBEE.md` for what a pairing press erases.

The **Bluetooth** block holds two lines. The first names the radio and starts
with **BLE HID: radio on.** or **BLE HID: radio off.** The second names the host
and sits above the Forget text.

An off radio can never read as connected, because the host line drops the link
state with the radio.

The block holds the **Forget Bluetooth host** button. The button is always on the
page and is disabled when no bond exists.

The Zigbee2MQTT inputs are built one time, so a repaint keeps an address that is
still being typed.

### The radio switches

Each block carries an on/off switch on the same line as its heading. The switch
turns that radio off and on for the whole remote.

The Zigbee line reads **Zigbee radio is on.** or **Zigbee radio is off. Zigbee
buttons are disabled.** with a circle. A green circle means that the radio is on
and the remote is on a network. An amber circle means that the radio is on but
the remote is not on a network. A red circle means that the radio is off.

The Bluetooth radio line reads **BLE HID: radio on.** or **BLE HID: radio off.
BLE buttons are disabled.**

The host line below it reads **Connected to bench-mac.**, **Bonded to bench-mac.
Waiting for the host.**, **Bonded to bench-mac.** with the radio off, or **No host
bond.** with **Ready to pair.** while the radio is on.

The remote holds the state, so a reload and a second browser both show what the
remote runs with. The switch is disabled until the remote answers with the state.
Home Assistant holds the same two switches, **Zigbee Radio** and **Bluetooth
Radio**.

An input that is assigned to a radio that is off keeps its assignment. The tile
shows the assignment in grey with a red circle after the label, and the editor
gives the reason. The input sends again when the switch goes back on.

If the Bluetooth switch is off, the remote does not start the NimBLE stack at
boot, and the first turn-on starts it.

The remote stores the host name that it reads from the host, so the line names
the bonded host with the radio off and after a reboot. If the remote never read
the name, the line reads **a saved host**.

**Forget Bluetooth host** works with the radio off. The keys live in flash, in
the `nimble_bond` NVS namespace, so the remote erases them without the stack. A
forget also drops the stored host name. The host must then pair again.

If the Zigbee switch is off, the remote sends no commands. The stack itself keeps
its place on the network only until the next reboot. Read `ZIGBEE.md` for the
reason.

If the switch was off at boot, the remote gates the stack so it never starts.
While the gate holds, the Zigbee line reads **Zigbee radio is on. The stack is
down. Reboot the remote to start it.** Turning the switch back on cannot start
the stack, because the ESP-Zigbee stack has no restart.

Select **Restart** in Home Assistant or on the page to reboot the remote and
lift the gate. Nothing else on the device offers a reboot.

### The Import and export card

The **Import and export** card at the bottom of the page moves every assignment
as one block of text.

The card is closed on arrival. The heading is the toggle. It reads **Show** when
the card is closed and **Hide** when the card is open.

### Copy the whole config

The Config tab shows the current configuration after the page loads.
The page reads each stored IR code in sequence and puts it in the configuration text.
It uses the stored code when you select an input.

The block holds one entry for each input, with its slot number, its label, and
its action.

An IR entry carries the Flipper `.ir` block itself, so an export restores a
remote without a source remote.

A Zigbee entry carries `kind`, which is `group` or `device`. A group entry holds
`group`. A device entry holds `ieee` and `ep`.

A BLE HID entry carries `kind`, `usage`, and `mod`. Only keyboard entries use `mod`.

The page updates the configuration text after each successful assignment.
If a code read fails, open the Config tab to retry it.
The page does not offer an incomplete current configuration for download.
Your edits and text from a file stay in the box until you apply or replace them.

Import checks every entry before the first flash write. If one entry is bad, the
page names the slot and writes nothing.

A valid block writes one input at a time through `POST /buttons/api/action`. The
remote reserves one action at a time, so a burst would take the 409.

An import leaves an input that the block does not name alone. A `none` entry
clears an input, but only if the input holds an action.

The import needs no new endpoint. Both directions use the same three endpoints as
the rest of the page.

### Trusted-LAN warning

The `/buttons` page and its three endpoints have no authentication. The
`api` and `ota` components on this device have none either.

This is a deliberate choice for a trusted home network. Any device on that
network can change an assignment.

Do not expose port 80 of the remote to the internet. If the network is not
trusted, add authentication to the page.

## LED meanings

After a boot that is not a deep-sleep wake, rainbow pulses go clockwise round
the wheel two times, from `D2` to `D5`. Each pulse overlaps the next. The status
indications then start.

Assignment mode uses `D3` and `D4` only. `D2` keeps the connection state, and
`D5` keeps the Zigbee state. A connection fault stays visible during a capture.
When `D3` and `D4` are idle, `D4` shows the Bluetooth state.

`D2` shows Wi-Fi and the API:

| `D2` | Meaning |
| --- | --- |
| Off | Wi-Fi is disabled. |
| Red pulse | Wi-Fi is enabled but disconnected. |
| Orange pulse | Wi-Fi is up, Home Assistant is expected, and the API is down. |
| Solid orange | Wi-Fi is up and Home Assistant is not required (Config switch off). |
| Solid green | The API is connected. |

The Home Assistant switch on `/buttons` Config only changes this LED. The API
server keeps running either way.

Wi-Fi serves the `/buttons` page only. A dark `D2` does not stop a button,
because IR and Zigbee playback need neither Wi-Fi nor the API.

| State | `D3` and `D4` indication | Next action |
| --- | --- | --- |
| Ready | Solid blue | Select an input. |
| IR training | Blue chase | Send one IR frame. |
| Saved | Solid green for one second | Continue or leave. |
| Error | Red flashes | Retry or leave. |
| Voice | Blue pulse | Tap again to clear. |
| Cleared | Amber for one second | Select an input. |

`D3` and `D4` show voice-assistant state when assignment mode is closed. After
a deep-sleep wake, all four LEDs pulse in the battery colour (see
[Deep sleep](#deep-sleep)).

`D4` shows the Bluetooth state when assignment mode and voice state are both
idle. `D3` stays dark then.

| `D4` | Meaning |
| --- | --- |
| Off | The Bluetooth radio is off. |
| Blue pulse | No host bond exists. The remote is ready to pair or is pairing. |
| Red pulse | A host bond exists but the host is not connected. |
| Solid green | The bonded host is connected and the link is encrypted. |
| Red flashes for 3 seconds | Pairing or encryption failed, or the remote rejected a second host. |
| Solid red | The Bluetooth stack did not start. |

The amber XIAO user LED shows that the remote is awake (see
[Deep sleep](#deep-sleep)). See [ZIGBEE.md](ZIGBEE.md) for the `D5` Zigbee meanings.

## Normal playback

Outside assignment mode, an input uses its one active assignment in this order:

1. Voice assistant, if assigned.
2. BLE HID, if assigned.
3. The Zigbee command, if assigned.
4. IR playback, if assigned.

An input without an assignment does not transmit a command.

## Deep sleep

The remote enters deep sleep to save battery. The `idle_sleep` component in
`c6remote.yaml` controls it. The `sleep_after`, `sleep_hold_time`, and
`cold_boot_grace` keys set the default times.

### Enter sleep

Two events start deep sleep: a hold on SW5, and an idle period.

To sleep at once, hold SW5 for the `sleep_hold_time` value. When the hold time passes, the amber XIAO user LED flashes once. Then release SW5.
The remote sleeps when you release all buttons. SW5 still sends its own assignment when you press it.
The hold ignores the blocks that follow.

If no activity occurs for the `sleep_after` time, the remote enters deep sleep.
A stored page value replaces this default.
A button press, or an edge on the expander INT line (`GPIO5`), counts as activity.

After a cold boot, the remote does not use idle sleep for the `cold_boot_grace`
time. A cold boot is a power-on, a flash, or a reset. A deep-sleep wake is not a cold boot.

### What blocks idle sleep

Idle sleep does not start while one of these is true:

- Assignment mode is open.
- The microphone runs, or the mic meter is active.
- The voice assistant runs.
- A Zigbee pairing request is active, or the pairing window is open.
- Wi-Fi is on and Wi-Fi Always On is off, as in the SW9 or page session.

A blocked remote counts as active. When the block ends, the full idle time starts again.

### Wake

The amber XIAO user LED is on while the remote is awake. It goes dark in deep
sleep.

Any button pulls the expander INT line (`GPIO5`) low and wakes the chip.
Before the firmware boots, a wake stub reads the expander. As a result, the
firmware knows which button woke it.

The wake press replay is a setting. It is off by default.
When it is off, the press that wakes the remote only wakes it. Press the button again to send its command.
A held SW1 or SW9 does not tap when you release it.

When the setting is on, the remote sends the wake press when the Zigbee link comes up.
The wake press is the Zigbee assignment of that button.
If no link comes within 3 s after setup, the remote drops the wake press.
[ZIGBEE.md](ZIGBEE.md) describes the send path.

SW9 acts when you release it. If you still hold SW9 at wake, the remote runs the
Wi-Fi hold whether the setting is on or off. When the setting is on, the remote sends the assignment
of SW9 when you release SW9 before the 2 s hold ends.

If you still hold SW1 at wake, the remote does not start the assignment mode
hold. When the setting is on, the remote sends the assignment of SW1 when you release SW1.

After a wake, all four LEDs pulse two times in the battery colour. Each pulse
is 800 ms. The colour shows the battery level at the first moment after the wake:

| Battery | Colour |
| --- | --- |
| 60 % or more | Green |
| 30 % to 59 % | Orange |
| Less than 30 % | Red |
| No reading | White |

The pulse covers the Wi-Fi, Bluetooth, and Zigbee status LEDs for 1.6 seconds.
The status colours return when the pulse ends. Assignment mode and voice states
have priority on `D3` and `D4`, so they stay visible during the pulse.

While the remote sleeps, these conditions apply:

- The `led_vdd` and `ir_vdd` rails are off, because `GPIO18` and `GPIO6` float and `R10` and `R11` pull the gates up.
- `GPIO16` floats and `GPIO17` has a pull-down.
- `GPIO0` and `GPIO2` stay low, so `MK1` sees no clock.
- `GPIO15` floats, so the XIAO user LED is dark.

### Sleep settings on the page

The `/buttons` page has a **Sleep** block. It shows only on a build with `idle_sleep`.

- The **Sleep** switch turns idle sleep on or off.
- The **Sleep after, in minutes** box sets the idle time from 1 to 60 minutes.
- The **Send the wake press** switch turns the wake press replay on or off. It is off by default.

The remote stores all three settings in flash. A change restarts the idle window.
The SW5 hold works when **Sleep** is off.

### Flash over USB

USB serial disconnects while the remote sleeps. To flash the remote, do these steps:

1. If this is the first build after the `idle_sleep` change, run `esphome clean c6remote.yaml`.
2. Run `esphome compile c6remote.yaml`.
3. Press a button to wake the remote.
4. Run `esphome upload c6remote.yaml --device /dev/cu.usbmodem2101`.

The cold boot grace after the flash reset keeps the remote awake for a while.
A stale incremental build after a component-count change can cause a boot loop.

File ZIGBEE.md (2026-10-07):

# Zigbee operation

## Role

The remote is an always-on Zigbee end device. It is not a router.

The remote uses endpoint 1 as a client of every cluster it can command. Each
assigned button sends one ZCL command to its stored target, which is a group or
one device.

The firmware holds no MQTT client. The `/buttons` page reads the Zigbee2MQTT
inventory in the browser and posts only the resolved address to the remote. The
page never publishes to Zigbee2MQTT. That websocket is read only.

The remote does not need MQTT, Wi-Fi, Home Assistant, or Zigbee2MQTT for button
playback. It needs Wi-Fi only while you configure it from the page.

## Requirements

Install Zigbee2MQTT and enable its frontend. The browser connects to the
frontend websocket, so the remote needs no broker credentials.

Use the pinned `luar123/zigbee_esphome` external component in `c6remote.yaml`.
Do not change its revision without validation.

ZHA does not supply the group and device lists this page reads. Use
Zigbee2MQTT.

## Pair the remote

A new remote boots with the Zigbee radio off. It has no record in flash, so it
starts no 802.15.4 stack and `D5` stays dark until you pair it.

1. Permit joining in Zigbee2MQTT.
2. Open `http://homething-c6-xxxxxx.local/`. `xxxxxx` is the last six
   hex digits of the remote MAC address.
3. Select **Pair this remote for 3 minutes** in the Zigbee block.
4. Wait for Zigbee2MQTT to show `homething-c6` as joined.
5. Confirm that `D5` is solid green.

A join needs both sides. Step 1 opens the coordinator, and step 3 opens the
remote. The page reports the coordinator state but never opens it.

The remote does not route Zigbee traffic. It does not enter deep sleep while a
pairing request or the pairing window is active. Keep it powered while the
coordinator forms or repairs the network.

If `D5` pulses red, the Zigbee stack has started but has no network connection.
Pair the remote again.

## Pair the remote from the page

The button turns the Zigbee radio on, opens a 3 minute window, and restarts the
remote to get there. The ESP-Zigbee stack starts only at boot, so a restart is
the only way to bring the radio up.

While the window is open, the button reads **Stop pairing** and the line next to it
counts down, such as "The remote is pairing for 2:54." `D5` pulses blue.

If the remote joins inside the window, the window closes, the radio stays on and
`D5` goes solid green. If the window closes with no join, the remote turns the
radio off and restarts, and `D5` goes dark.

A radio that went off that way stays off. The flag is in flash, so a restart
alone never brings it back. The `/buttons` page names the cause, so an off radio
is never a mystery:

`Zigbee radio is off. Zigbee buttons are disabled. The last pairing attempt
found no coordinator, so the radio went off.`

There are two ways back. Select **Pair this remote for 3 minutes** again, with
joining permitted in Zigbee2MQTT this time. Or turn the **Zigbee Radio** switch
on and restart the remote. Either one clears the line above.

**Stop pairing** sets no such line, because you closed that window yourself.

**Stop pairing** ends the window the same way. The credentials are already gone
by then, so a stopped window leaves the remote unpaired with the radio off.

The pairing request lasts only through the restarts that the pairing sequence
starts itself. Any other restart ends pairing. Examples are the **Restart**
button, a power loss, and a crash. The remote then starts with the Zigbee radio
off. To try again, select **Pair this remote for 3 minutes**.

### What a pairing press erases

A pairing press on a remote that already holds credentials erases them first,
which costs one more restart. The SDK calls that a factory reset, but its scope
on this board is only the Zigbee network:

- **Erased:** the network key, the PAN ID, the extended PAN ID, the channel, the
  short address and the binding table.
- **Kept:** all 18 button assignments, both radio switches, the stored IR codes,
  the Bluetooth bond and host name, and the Wi-Fi credentials.

The Zigbee stack keeps its data in the `zigbee` NVS namespace and clears that
namespace alone. ESPHome keeps its preferences in the `esphome` namespace, so no
assignment is at risk. The page asks for a confirmation before this, but only
when the state endpoint reports the remote as paired.

Zigbee2MQTT still holds the old entry after the erase. Remove the device there
before you pair the remote again, or the bridge shows two.

### The coordinator window

The Zigbee2MQTT block reports the coordinator window from the retained
`bridge/info` message. The line reads "Pairing is closed on the coordinator.
Permit joining in Zigbee2MQTT." or "Pairing is open on the coordinator for 2:54."
with a live countdown.

The page cannot open that window. Permit joining in Zigbee2MQTT itself.

If the socket is down, the line reads "The coordinator pairing state needs the
Zigbee2MQTT link."

## Groups and devices

A button holds one of two target kinds. A group target sends a groupcast. A
device target sends a unicast to one device.

Use a group when one button must switch more than one light together. Group
membership lives in the group table of the light, not in the remote, and only
Zigbee2MQTT can write it.

One group can serve more than one button. A button reads only the ID, so a later
membership change in Zigbee2MQTT needs no change on the remote.

Use a device target for one light. Zigbee2MQTT writes nothing for it, so a
repeated assignment leaves no group behind.

## Assign a button from the web page

1. Open `http://homething-c6-xxxxxx.local/`.
2. Select an input, then select **Zigbee target** in the Action selector.
3. The first time, enter the Zigbee2MQTT frontend websocket address, such as
   `ws://zigbee2mqtt.local:8080/api`. Enter the frontend token if one is set.
4. Select **Connect**.
5. Select **Group** or **Device** in the Target kind selector.
6. Select a group or a device. The picker fills the boxes below it.
7. Select the command in the **Action** selector, then fill its value box if it
   shows one.
8. Select **Assign**.

The device list holds only a device that accepts at least one of the actions. A
device the bridge published no endpoint list for stays in the list, because that
says nothing about what it accepts.

The Target kind selector decides which fields the panel shows. **Group** shows
the group picker and a **Group ID** box. **Device** shows the device picker, an
**IEEE address** box, and an **Endpoint** box.

The panel therefore holds one target at a time, and **Assign** sends what is on
screen. Changing the kind clears every field, so a value the panel stopped
showing can never be assigned.

Opening a slot that already holds a device target opens the panel on
**Device**.

The browser keeps the address and the token in `localStorage`. Neither value
reaches the remote, so each browser enters them once.

You can also type into a box. A picker does not appear without its bridge list,
so typing is the only route when this browser cannot reach the frontend.

A group ID is a decimal value, such as `4609`, or a hex value, such as `0x1201`.
The remote refuses `0` and every value above `0xFFF7`, because `0xFFF8` and
above are the reserved Zigbee broadcast addresses.

An IEEE address is 16 hex digits, such as `0x94deb8fffe9db81e`. The `0x` prefix
is optional. The page refuses a shorter value before it reaches the remote.

A device uses the value in the **Endpoint** box, and endpoint 1 when that box is
empty.

The page reads the target name from the bridge lists when it sends, not when you
pick. An edited box therefore cannot keep the name of the target it replaced.

The remote stores the address and the name. It writes the record to flash at
once, because no target needs a network confirmation to be stored.

### A device target

**Assign** sends the IEEE address, the endpoint, the action and its value to
the remote. The browser publishes nothing to Zigbee2MQTT.

The page picks the lowest endpoint that has the input cluster of the action. A
device can carry `genOnOff` on one endpoint and `hvacThermostat` on another, so
the endpoint follows the action. If the bridge publishes no endpoint list, the
page uses endpoint 1.

The remote stores the address and writes the record to flash at once. It looks
up the network address later, on the first press.

Use a mains device for a device target. A battery device keeps its radio off, so
the unicast waits at its parent until the device polls.

The assignment replaces any IR code or voice action on that input.

## How the remote finds a device

A Zigbee unicast needs the 16-bit network address, but the remote stores the
64-bit IEEE address. The network address is a lease that ends when the device
rejoins, so the remote never writes one to flash.

The remote resolves the address in this order:

1. It reads its own address map. This costs no radio traffic.
2. If the map has no entry, it broadcasts `NWK_addr_req` and caches the answer.
3. It sends the command to the cached address.

The APS confirm reports whether the device received the unicast. If the confirm
fails, the remote drops the cached address, resolves it again, and resends the
command one time. A second failure stops there, and the next press starts
again.

A slot broadcasts `NWK_addr_req` at most once every 10 seconds, because the
request reaches the whole mesh. A request that gets no answer in 5 seconds
fails.

After the remote joins, it warms the cache for each device slot. It reads the
address map first, and asks the mesh only for a slot the map does not hold. Each
slot is warmed at most once for each join, at one slot per second.

A warm cache only saves time on the first press. Correctness comes from the
confirm and the resend, so a cold or stale cache still works.

## How the browser reads the group list

The Zigbee2MQTT frontend relays every MQTT message on its websocket as a
`{topic, payload}` object, with the base topic already removed. The page keeps
the `bridge/groups` and `bridge/devices` messages and ignores the rest.

`bridge/devices` carries the endpoint list of each device, and each endpoint
carries its input cluster list. That list decides which actions the panel
offers and which endpoint an action goes to.

A websocket needs no CORS grant. A `fetch` to the same host would need one,
because the page comes from the remote.

The remote never subscribes to `bridge/devices`. ESPHome buffers a whole MQTT
payload before it delivers the message, and the retained device inventory of a
real network is larger than the free heap.

## Actions

A slot holds one target and one action. The action is one press, so a pair such
as brighter and dimmer costs two inputs. The wheel is the usual home for a pair,
because the up and down directions are two assignable slots.

| Action | Cluster | Value |
| --- | --- | --- |
| Toggle, On, Off | `genOnOff` | none |
| Brighter, Dimmer | `genLevelCtrl` | step size, 1 to 254 |
| Warmer white, Cooler white | `lightingColorCtrl` | step in mireds, 1 to 2000 |
| Recall scene | `genScenes` | scene ID, 0 to 255 |
| Open, Close, Stop | `closuresWindowCovering` | none |
| Warmer, Cooler | `hvacThermostat` | step in tenths of a degree, 1 to 127 |
| Lock, Unlock | `closuresDoorLock` | none |
| Alarm | `ssIasWd` | seconds, 1 to 600 |
| Squawk | `ssIasWd` | none |

The **Action** selector lists only the actions the target accepts. The page
reads the input cluster list of the device from Zigbee2MQTT, and a group offers
what every member of it accepts. A typed address describes nothing, so it offers
every action.

An action with a value shows a box for it. An empty box means the value the
placeholder names, so the panel always sends what it shows. The remote bounds
the value again, because an imported block reaches it without a picker.

The command does not wait for a coordinator, a broker, or a target state report.
The mesh routes it, so the button works while Zigbee2MQTT and Home Assistant are
both down.

Toggle does not mean "set on" or "set off." Each target changes its current
On/Off state. Use On or Off for a group whose members can fall out of step.

Brighter and Dimmer use StepWithOnOff, so a step up wakes a light that is off.

Warmer and Cooler send a relative setpoint change, which needs no attribute
read. A Tuya thermostat answers no standard command, so it needs Home Assistant.

A lock refuses a frame the remote is not bound for, so Lock and Unlock only work
on a lock that has this remote in its access list.

## State in Zigbee2MQTT and Home Assistant

The remote sends each command directly to the target. The command does not pass
through the coordinator as a request, so Zigbee2MQTT does not learn the new
state of the light. Home Assistant reads the state from Zigbee2MQTT, so it shows
the old state.

A group command also reaches the coordinator. Zigbee2MQTT shows it as an
`action` with an `action_group`, but it reads no light after the command. Its
built-in poll reads only lights from some brands, for example Signify. A device
command does not reach the coordinator.

To keep the state correct, configure reporting on each target light in
Zigbee2MQTT. Open the device, open the **Reporting** tab, and use endpoint 1.
These values are the Zigbee2MQTT defaults for a light.

| Cluster | Attribute | Minimum | Maximum | Change | Actions |
| --- | --- | --- | --- | --- | --- |
| `genOnOff` | `onOff` | 0 | 3600 | 0 | Toggle, On, Off |
| `genLevelCtrl` | `currentLevel` | 5 | 3600 | 1 | Brighter, Dimmer |
| `lightingColorCtrl` | `colorTemperature` | 5 | 3600 | 1 | Warmer white, Cooler white |

If a light accepts the configuration but sends no reports, its state stays
stale.

## Battery level

The remote has a Power Configuration server cluster on endpoint 1. Attribute
`0x0021`, `batteryPercentageRemaining`, holds the battery level in units of
0.5 %. The value `0xFF` means that the remote has no reading.

The remote sends the value one time for each wake, after it rejoins the network.
While it stays awake, it sends the value again only after a change of 2 % or more.

Zigbee2MQTT generates a `battery` property from this cluster. No external
converter is necessary. The same percent also shows as the `Battery` sensor in
Home Assistant over the ESPHome API when Wi-Fi is on.

After the first flash of this build, re-interview the remote one time in
Zigbee2MQTT. Do this while the remote is awake, because Zigbee2MQTT must read the
new cluster list.

## Send path

`zigbee_learning.h` holds the send path. The SDK is `esp-zigbee-lib` 2.0.4, which
uses the `ezb_*` API.

A press calls `play()`. A group target goes straight to `send_command_()`. A
device target goes through `play_device_()`, which resolves the network address
first.

`send_command_()` fills one `ezb_zcl_cluster_cmd_ctrl_t` and hands it to
`dispatch_()`. Only `dispatch_()` knows the action, so it picks the payload
struct and the request function.

A group request uses `EZB_ADDR_MODE_GROUP` and the group ID. A device request
uses `EZB_ADDR_MODE_SHORT` and the resolved network address.

`src_ep` is always `CLIENT_ENDPOINT`, which is endpoint 1. A device request also
sets `dst_ep` from the record.

Every SDK call must run between `esp_zigbee_lock_acquire()` and
`esp_zigbee_lock_release()`. The main loop sends, and the Zigbee task runs the
confirm and resolve callbacks.

A device request sets `cmd_ctrl.cnf_ctx.cb` to `on_confirm_`. A group request
sets no callback, because a groupcast returns no acknowledgement.

A callback must not block on flash or on the record mutex. It parks the slot in
`pending_state_`, and the next main loop tick does the work.

`dispatch_()` reads no attribute, so a press stays one frame with no round trip.

### Where the numbers come from

The `Action` enum in `zigbee_learning.h` and the `ZA` table in
`components/button_config/button_config_page.h` hold the same numbers. A new
action needs a row in both, or the page names a command the remote does not
know.

`action_valid_()` bounds the value of each action. The page bounds it too, but
an import block reaches the manager without passing a picker.

The cluster of an action must also appear as a `role: CLIENT` cluster on
endpoint 1 in `c6remote.yaml`.

### Other commands the SDK can send

The library compiles the full ZCL client command set, and the remote uses part
of it. The headers are in
`managed_components/espressif__esp-zigbee-lib/include/ezbee/zcl/cluster/`.

These commands are compiled but unused:

| Cluster | Commands |
| --- | --- |
| On/Off `0x0006` | `off_with_effect`, `on_with_timed_off` |
| Level `0x0008` | `move_to_level_with_on_off`, `move`, `stop` |
| Color control `0x0300` | `move_to_color_temperature`, `move_to_hue_and_saturation`, `color_loop_set` |
| Scenes `0x0005` | `store_scene` |
| Identify `0x0003` | `identify` |
| Thermostat `0x0201` | the weekly schedule commands |
| Any cluster | `read_attr`, `write_attr`, `config_report`, `custom_cluster_cmd` |

`ezb_zcl_write_attr_cmd_req()` and `ezb_zcl_custom_cluster_cmd_req()` reach an
attribute or a manufacturer cluster that has no named command.

`move` and `stop` need a press edge and a release edge, so they need an input
that reports both. Every action the remote sends today is one press.

An absolute setpoint needs a write to cluster `0x0201`. Attribute `0x0012` is
the heating setpoint, and `0x0011` is the cooling setpoint. Both are `int16` in
0.01 C.

Attribute `0x001C` is the system mode. Its values include off `0x00`, auto
`0x01`, cool `0x03`, and heat `0x04`.

A Tuya thermostat does not answer cluster `0x0201`. It uses manufacturer cluster
`0xEF00` and a datapoint payload for each model.

## Clear a button

Clear a button from the `/buttons` page, or with the last tap of the assignment
cycle on the remote.

Clearing removes the local record only. A group and its membership stay in
Zigbee2MQTT, so another button can still use that group. A device target leaves
nothing behind, because the assignment wrote nothing to Zigbee2MQTT.

## The radio switch

One switch turns the Zigbee radio off for the whole remote. The switch is on the
`/buttons` page, on the heading line of the **Zigbee2MQTT** block, and in Home
Assistant as **Zigbee Radio**.

If the switch is off, every button that sends Zigbee is disabled and the remote
asks for no network address. The assignments stay in flash, so the buttons work again when
the switch goes back on.

The stack keeps its place on the network only until the next reboot, because the
ESP-Zigbee stack has no restart. A rejoin would cost the pairing that the buttons
point at.

An `on_boot` trigger at priority 800 reads the stored switch from flash with
`ZigbeeAssignmentManager::radio_enabled_from_flash()`. A remote with no record
has never paired, so an unreadable record also reads as off. If the switch is off, it
calls `mark_failed()` on the Zigbee component and records the gate with
`zigbee_assignments.set_boot_gated(true)`. A failed ESPHome component never runs
its setup, so the 802.15.4 stack never starts.

While the gate holds, turning the switch back on cannot start the stack. Reboot
the remote to lift the gate. See "Network state on the page" for the line the
page shows.

Select the **Restart** button entity to reboot the remote from Home Assistant or
from the `/buttons` page. A pairing press also restarts the remote, and it turns
the radio on first, so it lifts the gate as well.

`D5` is dark while the switch is off, the same as before the stack starts.

The switch state lives in the Zigbee assignment record, so the remote restores it
after a reboot.

## Network state on the page

The stack reports three states, and the `/buttons` page names the one it is in
under the switch:

| Line | Meaning |
| --- | --- |
| `Zigbee radio is on. The stack has not started.` | The stack has not answered its start signal yet. |
| `Zigbee radio is on. Not paired.` | The stack is factory new. It has no credentials and it searches for a coordinator. |
| `Zigbee radio is on. Not on the network yet. The remote is rejoining.` | The stack holds credentials and it rejoins the network. |
| `Zigbee radio is on. Pairing.` | A 3 minute pairing window is open. |
| `Zigbee radio is on. Paired to a Zigbee network.` | The remote joined a network. |
| `Zigbee radio is on. Paired, but the last command to a device was not acknowledged.` | See "Reachability" below. |
| `Zigbee radio is on. The stack is down. Reboot the remote to start it.` | The switch was off at boot, so the stack never started. Reboot to lift the gate. |

The component latches its connected flag on the first join and never clears it,
so `Paired` means joined once, not reachable now.

The `zigbee` component keeps its instance file-static, so the 250 ms interval in
`c6remote.yaml` pushes `is_started()`, `is_connected()`, and `factory_new_` into
`zigbee_assignments`. The `/buttons` state endpoint reads them from there.

## Reachability

The component sets its connected flag on the first join and never clears it, so
solid green means joined once and not reachable now. The amber pulse is what
reports reach, and the remote derives it from traffic the buttons already send.

A device unicast carries an APS confirm. Each press gets one resend, so the state
goes to failed only when the resend fails too. A `NWK_addr_req` that times out or
that the mesh answers with a failure counts the same way. Any success clears it.

Two limits follow from that:

- A group target sets no confirm callback, because a groupcast is
  unacknowledged. A remote whose buttons are all group targets therefore learns
  nothing and stays unknown, which reads as solid green.
- An idle remote learns nothing. Amber means the last device command was not
  acknowledged, not that the network is down now.

A join clears the state back to unknown. The warm-cache pass that follows a join
is the one probe the remote makes without a press.

After a deep-sleep wake, the remote rejoins the network. The press that wakes the remote
only wakes it, unless the **Send the wake press** setting is on. When the setting is on and
the link comes up, the remote sends the wake press. If no link comes within 3 s after setup,
it drops the wake press. See [Wake](RECEIVER.md#wake) in RECEIVER.md.

## Storage

The remote stores one record for each of the 18 assignable slots. A record holds
a target kind, the target name, the address for that kind, the action, and the
value of the action.

A group record holds the group ID. A device record holds the IEEE address and
the endpoint of one device.

The record format is version 5. The remote reads a version 4 or a version 3
record and writes it back as version 5, so the assignments survive the update.
An older record names no action, so the migration gives it Toggle.

Each format has a different length, so a newer load fails first and the
migration runs. Version 2 and earlier do not load, and those slots start
clear.

## LED meanings

`D5` shows Zigbee state at all times.

| `D5` | Meaning |
| --- | --- |
| dark | The radio is off, or the stack has not started. |
| blue pulse, 1600 ms | A pairing window is open. |
| red pulse, 3200 ms | The stack is up but it has not joined this boot. |
| solid green | The remote joined a network. |
| amber pulse, 4000 ms | Joined, but the last device command was not acknowledged. |

Pairing is tested before the join, so an open window never shows the red that
means a fault.

`D2` shows Wi-Fi and the API. Wi-Fi serves the `/buttons` page only, so a dark
`D2` does not stop a button.

Assignment mode uses `D3` and `D4` only, so `D5` stays readable.

| LEDs | Meaning |
| --- | --- |
| `D3` and `D4` solid blue | Assignment mode waits for an input. |
| `D3` and `D4` blue chase | The selected input waits for an IR code. |
| `D3` and `D4` solid green | IR assignment saved. |
| `D3` and `D4` flash red | An IR or flash operation failed. |
| `D3` and `D4` pulsing blue | The selected input now starts Assist. |
| `D3` and `D4` amber | The selected input is clear. |

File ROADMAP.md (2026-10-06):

# Roadmap: c6remote

Open work for c6remote, ordered by severity. Fabrication history, bring-up results and closed findings are in [`docs/timeline.md`](docs/timeline.md). The power budget is in [`docs/power-budget.md`](docs/power-budget.md).

## High

- [ ] **Measure the power budget on a rev-B board.** Everything in [`docs/power-budget.md`](docs/power-budget.md) is datasheet arithmetic: about 51 uA in deep sleep and about 31 mA awake. No figure is measured. The `led_vdd` and `ir_vdd` gates were both designed against that arithmetic and neither has been on a meter. Five rev-B remotes exist since 2026-08-24, so the measurement is now a bench task and not a fab-order gate. Rev-B is the `2026.8.0` board and carries no `Q3`, so `U2` stays powered there and the measured floor includes its 350 uA. Measure the deep-sleep current with `led_vdd` gated off, then compare it against the pre-gate 0.41 mA figure. The 58 uA figure needs a board that carries the `ir_vdd` gate, so it stays unmeasured until the next build. Before `Q3` the calculated floor was 0.41 mA, so the two gates are worth about 7x if the arithmetic holds. The `R7`/`R8` divider at 21 uA is the largest remaining static load and sits on the battery, so it cannot be switched.

- [ ] **Raise the microphone sample rate before the next build runs a `DMM-4026-B-I2S-R`.** Raised 2026-09-07 with the `MK1` swap. `c6remote.yaml` runs the mic at `sample_rate: 16000` with `bits_per_sample: 32bit`, which is a 1.024 MHz bit clock. The PUI data sheet page 1 gives an input clock of 2.048 to 4.096 MHz in normal mode and 320 kHz in sleep mode, so 1.024 MHz sits below the normal-mode minimum and in no defined mode. The ICS-43434 accepted 16 kHz, so this is new with the part and not a pre-existing defect. Use `sample_rate: 32000` for a 2.048 MHz clock or `sample_rate: 48000` for 3.072 MHz. Check what the change costs downstream first, because `on_data` in `c6remote.yaml` shifts each sample right by 16 and the voice assistant consumes the same stream. The bench cannot settle this until a board carries the new part, so it is a firmware change to make with the next build and not before.

Follow the microphone implementation and validation plan in [`docs/mic-v3-plan.md`](docs/mic-v3-plan.md).

- [ ] **Bench-verify the `ir_vdd` gate and the `TSOP6136` on the next build.** No built board carries `Q3`, `R11`, `ir_en` on `GPIO6`, the `TSOP6136` or the `Library:Vishay_PANHEAD-4Pin_TopView` land pattern, because rev-B is the `2026.8.0` board and predates both changes. Verify that the rail is off by default, that the `IR Rail` switch turns it on, and that `remote_receiver` decodes through the bottom face with the top-view lens. Also verify the datasheet pin order 1 GND / 2 N.C. / 3 Vs / 4 OUT against the land pattern.

## Medium

- [ ] **Add a reset button in the next board revision.** Connect a momentary button to the XIAO reset input. Place it where the enclosure permits access. Verify that a press restarts the ESP32-C6 without removing power.

- [ ] **Put both ends of the IR path behind one aperture.** Raised 2026-08-17. `U2` (`TSOP6136`, `Library:Vishay_PANHEAD-4Pin_TopView`, B.Cu at 42.845,31.8575) and `D1` (`INL-3AHIR30`, `Library:LED_D3.0mm_Horizontal_O1.27mm_Z2.0mm_IRBlack`, B.Cu at 61.98,32.75 since 2026-08-17) both sit on the back face now, with `Q1` (`MMBT2222A`, 68.3125,32.3) and `R1` (470R, 69.0,35.75) beside `D1` on `IR EMIT`. `D1` is still a 3mm through-hole lamp, bent horizontal on a 2.0mm standoff. The shared aperture is what stays open: `case/README.md` records the lap joint at the IR end broken by both the IR relief and the emitter window, so the case still opens twice at that end. One shared window buys one less break in the skirt. The cost is an aiming decision, because a handheld remote is pointed by its nose, so an emitter that fires through the back face needs the case to redirect it or the user to tilt the remote. The cheaper variant of the same idea is to leave both firing out the +Y end wall and only share the aperture. Flipper data point, checked 2026-08-17: a Flipper Zero puts three transmitting IR LEDs and its receiver behind one IR-transparent window at the end of the case, so both directions share an aperture and neither fires through a face, and the receiver is the `TSOP75338`. Their emitter part number is not in the published documentation: `docs.flipper.net` serves `peripherals-schematic.pdf` through a presigned archbee URL that answers `{"status": "Not Allowed"}` to anything but a browser, so that sheet has to be opened by hand to read the LED line, and the Flipper blog gives only 940nm with no drive current. The SMD emitter swap was costed out and rejected on 2026-08-17, so `D1` stays through-hole; the side-view intensity figures behind that verdict are in [`docs/timeline.md`](docs/timeline.md). If the hand-formed lead is what needs to go, the cheap fixes are a lamp sold with pre-formed right-angle leads or a moulded LED holder that fixes height and angle, not a package change. Emitter drive follow-up for the same batch: `R3` went from 22R to 10R on 2026-08-17 for about 150mA, and `R1` stays at 470R for a forced beta of 28. Dropping `R1` to 220R gives 11.6mA of base for the last 15% and is still inside the C6's GPIO limits. Past roughly 300mA the base drive from a 20mA-capable GPIO becomes the limit on `Q1`'s Vce(sat), and that is the point where `Q1` wants to be a small N-FET with a reservoir cap on the emitter node, the same argument `C4` settled for the LED rail. Narrower is for range, not coverage, so if bring-up says coverage rather than reach, the second emitter to add is a wide one in parallel with its own resistor, never in series, because two Vf plus Vce(sat) leaves nothing across the resistor on 3.3V and the 0.8V to 1.5V Vf spread on that sheet would then set the current instead. Whoever picks this up: batch it with any other board change rather than spinning a board for it, because the `DMM-4026` mic swap it used to be batched with landed on 2026-09-07. Rerun `scripts/export-case-refs.sh` then `case/.venv/bin/python case/check.py` afterwards, because both the bottom-side keepout heights and the window positions come out of the assembly STEP. Verify pad numbering and polarity against the datasheet before adopting any footprint, per the footprint rule in `AGENTS.md`.
- [ ] **Print and validate the bottom IR window insert.** Raised 2026-08-22 with the case model. `case/export/c6remote-ir-window.stl` is a conformal stepped insert that installs from inside, with an exterior-flush pane, a 0.05mm press per side, an open interior retention flange, and a shell shoulder for adhesive. Test the first-print fit, the flush contour, the adhesive land, and 940nm transmission with a real remote. If the printed shell material loses too much range or angle, remake the same stepped geometry in IR-pass acrylic. The old flat-sheet outline is not a drop-in replacement.

- [ ] **Bench-check the battery curve and the ADC reading.** Raised 2026-10-05. On a rev-B board, compare `Battery Voltage` with a meter on the cell at several charge levels. Take each meter and page pair in the same state, on or off USB, because the charge current raises the cell voltage. Then check that the wake pulse colour changes at the 60 % and 30 % points of the curve in `c6remote.yaml`.

## Low (cosmetic / config)

- [ ] **Add a dedicated Wi-Fi status LED in the next board revision.** Use steady colors for connected and disconnected states. Keep this indicator independent from the voice-assistant LEDs.

- [ ] **Fix silkscreen clipping and silk-over-copper.** `silk_edge_clearance` and `silk_over_copper` cases sit around the XIAO module. Move the reference designators inboard and off the pads. The artwork carries 24 `silk_over_copper`, 4 `silk_edge_clearance` and 1 `silk_overlap` case. The project ignores the first two rules, so they do not appear in the DRC count. 5 of the `silk_over_copper` cases are the ANO wheel outline crossing `ENC1` pads and are intentional.

## Back silkscreen artwork

Free-space survey of `B.SilkS` (pcbnew, 0.25mm raster, 0.35mm clearance from board edge, back-side mask openings, and existing back silk): the largest clear rectangle is **1930mm2 at x 35.39..71.64, y 85.51..138.76** (36.25 x 53.25mm), the lower-middle of the back. Second best is 462mm2 at x 35.39..71.64, y 38.26..51.01 (36.25 x 12.75mm) near the top. Back copper there is B.Cu `+3.3V` plane under soldermask, which does not trip `silk_over_copper` (that rule tests mask openings, not zones).

- [ ] **Radio capability marking. Use generic glyphs, not the certification logos.** Verdicts: **Bluetooth** word mark and figure mark are licensed only to Bluetooth SIG members whose product completed the Qualification Process. Espressif's ESP32-C6 QDID does not transfer, an end product needs its own Declaration ID, and while Adopter membership is free the Declaration fee is not (historically 4,000 to 8,000 USD). No hobbyist carve-out exists. **Wi-Fi** is the one favourable case: the April 2025 Wi-Fi Alliance Brand Style Guide has a "Brands for Public Use" tier that licenses the plain `Wi-Fi` word mark free to non-members, so the word is usable if spelled with the capitals and hyphen and not implying certification, but `Wi-Fi CERTIFIED` and the certification logo stay member-and-certification gated. **Zigbee** is the strictest: CSA's Nov 2025 guidelines require both Alliance membership and product certification for any brand or logo use, with no public tier. **Seeed logo** is out too, using it implies affiliation, though descriptive text naming the module is ordinary nominative use. Recommended unencumbered marking: a generic concentric-arc radio glyph plus `2.4 GHz`, optionally the bare IEEE standard numbers `802.11` and `802.15.4`, which are standard designators rather than certification marks. Fits the 36.25 x 12.75mm rectangle at y 38.26..51.01.
- [ ] **Module reference text.** Still open: a `B.SilkS` line naming the socket, `Seeed XIAO ESP32-C6`, plus board revision. The y 120..138 slot originally reserved for text is now the OSHW gear, so the remaining space is the y 38.26..51.01 rectangle at the top, shared with the radio marking above.
- [ ] **Optional `homeThing` logo.** `docs/readme-assets/homeThingLogo.svg` is 3 paths on a near-square 805x795 viewBox, imports cleanly. Would compete with the flag for the same rectangle, so pick one as the hero.
- [ ] **After any further silk work:** rerun `pcb drc` and confirm that the `silk_edge_clearance`, `silk_over_copper` and `silk_overlap` counts do not rise above 4, 24 and 1. Then run `scripts/regen-fab.sh` so `export/` picks up the new silk. No zone refill is needed, because silkscreen does not touch copper.

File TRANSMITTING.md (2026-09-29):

# IR transmitting

## Verified functions

- GPIO1 controls the IR transmitter circuit.
- Q1 operates as the low-side switch for D1.
- The transmitter uses a 38 kHz carrier with a 50 percent duty cycle.
- One v2 board transmitted NEC test frames to another v2 board.
- The receiver decoded `0x1234/0x78AB` every two seconds.
- The receiver logs raw pulse durations. Only `c6remote-test-common.yaml` sets `dump: all`, so only that bench build logs decoded protocols now.
- The receiver decodes Samsung power as `0xE0E040BF` with 32 bits.
- The receiver decodes Samsung volume up as `0xE0E0E01F` with 32 bits.
- D1 and Q1 transmitted the verified NEC test frames.
- The matrix runs of 2026-08-29 verified four transmit paths: Samsung encoder, `transmit_raw`, Pronto and repeats.
- All four paths transmit from both boards. A role swap gave the same result.
- The `x3` repeat with a 40 ms `wait_time` transmits correctly. Repeats up to `x5` at 100 ms also transmit.
- U2 decodes both a 36 kHz and a 38 kHz raw carrier.

## Root cause of the 2026-08-29 transmit failure

Both remotes run `c6remote.yaml`. Board B decoded real remotes: Samsung power `0xE0E040BF`, Samsung volume up `0xE0E0E01F`, and a Roku frame that decoded as JVC, LG, NEC and Pronto.

Board B never saw a transmission from board A, not even a raw frame. The dead actions were the SW10 and SW11 `remote_transmitter.transmit_samsung` with `repeat: times: 3, wait_time: 40ms`, and the SW3 `transmit_raw` replay of the learned 68-pulse Roku frame.

Only `c6remote-ir-tx-test.yaml` ever transmitted between the boards, with `transmit_nec` `0x1234/0x78AB` and `command_repeats: 2`.

The `status_light` in the `light:` block of `c6remote.yaml` uses `esp32_rmt_led_strip` and gave no `rmt_symbols`.

The ESPHome default for the ESP32-C6 is 96 symbols. The C6 has two RMT TX channels of 48 symbols each.

So the LED strip claimed both channels, and `remote_transmitter` failed at boot. The boot log shows the failure:

```text
E (534) rmt: rmt_tx_register_to_group(152): no free tx channels
[E][remote_transmitter:072]: Configuring RMT driver failed: ESP_ERR_NOT_FOUND (out of RMT symbol memory)
[E][component:188]:   remote_transmitter is marked FAILED: unspecified
[C][esp32_rmt_led_strip:273]:   RMT Symbols: 96
```

A failed transmitter returns from `send_internal()` with no output. The action layer still logs `Sending Samsung` and `Output button 3`.

As a result, the log of a dead transmitter looks the same as the log of a healthy one.

The test firmwares `c6remote-ir-tx-test.yaml` and `c6remote-test-common.yaml` set `rmt_symbols: 48` on the strip. Both worked.

The fix adds `rmt_symbols: 48` to `status_light` in `c6remote.yaml`. `scripts/tests/test_ir_learning.py` guards it.

The test `test_transmitter_reserves_shared_rmt_memory` now checks the LED strip as well as the transmitter.

To identify this fault again, read two boot log blocks. The `Remote Transmitter:` block must not report `Configuring RMT driver failed`.

The `ESP32 RMT LED Strip:` block must report `RMT Symbols: 48`.

Production `c6remote.yaml` logs at `INFO`, so it does not print these `[C]` blocks. To read them, run `c6remote-test-sleep.yaml`, which includes production and logs at `DEBUG`.

Both builds still print the `[E]` lines. They show `UNKNOWN ERROR` in place of the `ESP_ERR_*` name, because production turns off the error name table.

After the fix, the SW10 and SW11 Samsung presets were removed from `c6remote.yaml`. All buttons SW3 to SW11 are now learn slots.

## Matrix test method

A temporary test firmware ran the bisect on 2026-08-29. The files were removed after the run.

A transmitter board cycled 11 variants under 4 environments from boot, at 3 s intervals. A receiver board logged every frame. A script flashed both boards over USB, captured both serial logs, and printed a result table.

The 11 variants all used the Samsung volume up payload `0xE0E0E01F`, except variants 1, 4 and 10:

1. `nec_control`, NEC `0x1234/0x78AB` with 2 repeats.
2. `samsung_x1`.
3. `samsung_x3_40ms`, the exact factory action.
4. `nec_x3_40ms`.
5. `raw_samsung_38k`.
6. `raw_samsung_x3_40ms`.
7. `raw_samsung_36k`.
8. `pronto_samsung`.
9. `samsung_x3_46ms`.
10. `raw_roku_replay`, the learned 68-pulse frame.
11. `samsung_x5_100ms`.

The sweep used 4 environments:

- A: the LED effect was off and the mic was off.
- B: the LED effect was on.
- C: mic capture was on.
- D: both were on.

Environment B wrote to the LED RMT channel without a stop. The Wi-Fi variant connected 34 s into a 158 s sweep.

The two boards were on `/dev/cu.usbmodem101` and `/dev/cu.usbmodem2101`.

## Results

- Run 1, `usbmodem2101` transmits and `usbmodem101` receives: 44 of 44 sends reached the receiver. Every variant decoded. The Samsung variants decoded as Samsung and Pronto. The NEC variants decoded as NEC, JVC, LG and Pronto. All environments logged `A started` and `A complete`, no run logged `rmt_transmit failed`, and the sending board saw its own reflection on every send.
- Run 2, the Wi-Fi transmitter firmware on the same boards: 44 of 44.
- Run 3, the roles swapped so that `usbmodem101` transmits: 44 of 44.
- Run 4, the factory `c6remote.yaml` on `usbmodem101` and the matrix receiver on `usbmodem2101`: the receiver saw nothing after three presses of `Send Short IR Test Burst` over the API. The boot log of the sending board showed the RMT failure above. This run isolated the fault.
- Run 5, factory `c6remote.yaml` with the fix on `usbmodem101`, matrix receiver on `usbmodem2101`: the boot log shows `RMT Symbols: 48` for the strip and no transmitter error. Three `Send Short IR Test Burst` presses over the API reached the receiver as `568,-10000` raw frames.

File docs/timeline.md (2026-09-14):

# Timeline and hardware revisions

This file is the fabrication, bring-up and design-change history of c6remote. Open work lives in [`ROADMAP.md`](../ROADMAP.md), and the power budget in [`docs/power-budget.md`](power-budget.md).

Two builds exist. Unit 1 is a single prototype from the [2026.6.0](https://github.com/landonr/homething-c6/releases/tag/2026.6.0) fab package, delivered by PCBWay on Monday 2026-07-20 with PCB plus SMD assembly. The rev-B build is five assembled remotes, built from the [2026.8.0](https://github.com/landonr/homething-c6/releases/tag/2026.8.0) fab package at `d0a2c2e` and delivered on Monday 2026-08-24. The design has moved on since both, so read the comparison table below before you use a photo or a measurement from unit 1.

## Unit 1 (2026.6.0) versus the current design

Unit 1 was the only board that existed until the rev-B build arrived on 2026-08-24, and the design has moved on since unit 1 was fabbed. Everything below is a difference, so a photo or a measurement from unit 1 does not describe what the next order will build. The 2026.6.0 fab package is attached to the [2026.6.0 release](https://github.com/landonr/homething-c6/releases/tag/2026.6.0).

Quickest way to tell the two apart in a photo: the front silkscreen under the logo reads **V0.1** on unit 1 and **2026.8.1** on the current design. The two strings differ in format, not just value, because the release numbering scheme changed from ad hoc `vX.Y` to CalVer between the two boards: unit 1 was fabbed under the old scheme and keeps its printed `V0.1` forever, the current design carries the new scheme's format. That mismatch in format is expected, not an inconsistency.

Rev-B is the `2026.8.0` board. It is a later design than unit 1, but it is not the current `develop` design. Read the unit-1 table below as a rev-B table too, because rev-B carries the current-design column of every row, with these exceptions:

- The `ir_vdd` gate is absent. Rev-B has no `Q3`, no `R11` and no `ir_en` net.
- `U2` is the through-hole `TSOP4136` on the bottom side, not the SMD `TSOP6136`.
- `D1` is on the top face with `R3` at 22R, not on the back face at 10R.
- `SW1` and `SW2` sit at their old y 43.75 positions.
- Mounting is three routed 2.9mm holes for M2.5 screws, not `H1`-`H3` 2.4mm M2 NPTH.
- The front silk reads `2026.8.0`, the back silk keeps the old origin wording, and the stackup declares no colours.

So rev-B has the `led_vdd` gate (`Q2`, `R10`, `C4`), the four `XL-2020RGBC-WS2812B` LEDs and the TL3315 terminal remap. It also has the `ENC1` pad 6/8 fix, the ICS-43434 pin numbering, no `TP_*` test points and no `VCC` rail.

| Unit 1, as fabbed (`70ab9b0`) | Current design (`develop`) |
| --- | --- |
| Front copper as fabbed, U2 on the front and one LED by the XIAO | Front copper of the current design, four LEDs around the wheel and no front U2 |
| Back copper as fabbed | Back copper of the current design, U2 moved to the back plus silkscreen artwork |

Both columns are the flat copper SVGs, which KiCad exports tight to the 36.98 x 130mm board outline, so the two scale alike with no cropping and no copied files. The right column is pinned to `develop` by branch name, so it always shows the current design no matter which branch you are reading this file on. It deliberately is not a relative path: relative paths resolve against the branch being viewed, and since `main` is the default branch, a visitor would otherwise get the last released snapshot under a column labelled `develop`. The left column is pinned to the fab commit by full sha and keeps showing the board PCBWay built regardless of what lands on either branch. Those renders were generated at `0df2483` and the 06-16 fab commit only touched a symbol value and the BOM, so they match the delivered copper.

| Block | Unit 1, as fabbed (`70ab9b0`) | Current design |
| --- | --- | --- |
| Status lighting | One `SK6812MINI` (3.5x3.5) as D2, with R2 330Ω in series on the data line and C2 1µF decoupling | Four `XL-2020RGBC-WS2812B` (2.0x2.0) as D2-D5 in a cascade around the wheel, no series R, and the VDD rail gated by a high-side load switch: Q2 AO3401A P-FET from `+3.3V` onto `led_vdd`, R10 1M gate pull-up holding it off by default, C4 1µF bulk cap mid-chain, enable net `led_en` on GPIO18 (drive low for on) |
| IR receiver | U2 `TSOP4136` on the front (F.Cu), a through-hole part standing 10.43mm off the board, two receiver cutouts in the top board edge | U2 `TSOP6136` on the back (B.Cu) on `Library:Vishay_PANHEAD-4Pin_TopView`, a Panhead SMD part standing about 4.0mm off it and receiving perpendicular to the board through the bottom face, same AGC1 setting and same 36kHz carrier, both top-edge cutouts dropped |
| Discrete switches | TL3315 terminals 1/2 on `sw*` and 3/4 on GND, which shorts every populated switch input to GND | Terminals 1/2 on GND, 3/4 on `sw*` |
| ANO encoder | ENC1 pads 6 and 8 swapped, so COM_A sits on `ano_sw2` and the up switch common sits on GND | Pad 6 GND, pad 8 `ano_sw2` |
| Microphone | MK1 wired to INMP441 pin numbers, so the ICS-43434 gets the bit clock on WS and its SD pad buried in the GND pour | MK1 on the ICS-43434 numbering, `sck`/`ws`/`sd` on GPIO2/GPIO0/GPIO21 |
| Battery sense | Absent, no `bat_sense` net and no R7/R8 divider | R7/R8 100k divider to GPIO4 |
| Expander interrupt | Absent, no `exp_int` net and no R9 pull-up | R9 100k pull-up, nINT to GPIO5 |
| Battery connector | J1 through-hole `S2B-PH-K` | J1 SMD `S2B-PH-SM4-TB` |
| Board edge | Square corners, four square encoder cutouts | 3mm filleted corners, real Adafruit ANO cutout shapes |
| Mounting | No fixing points | Three `H1`-`H3` 2.4mm NPTH holes for M2 screws |
| IR emitter | D1 on a plain 3mm LED footprint on the front (F.Cu), leads bent 90° by PCBWay at assembly | D1 on the back face (B.Cu) at 61.98,32.75 on a forked horizontal footprint with + and - silk glyphs, so the bend is designed in, and `R3` at 10R for about 150mA |
| Via in pad | Four vias inside SMD pads, which PCBWay flagged 2026-07-30 as a solder-paste leakage risk | All four cleared |
| Silkscreen | Front homeThing logo only | Plus back artwork (flag, OSHW gear, made-in text) and a front mic-port mark |
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

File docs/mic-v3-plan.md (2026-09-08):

# V3 microphone plan

## Constraint

V3 uses the PUI Audio `DMM-4026-B-I2S-R` microphone.

The microphone needs a clock from 2.048 MHz to 4.096 MHz in normal mode.

ESPHome produces a 2.048 MHz bit clock when it captures 32-bit I2S audio at 32 kHz.

ESPHome `voice_assistant` accepts only a 16 kHz microphone source.

Do not connect the 32 kHz hardware source directly to `voice_assistant`.

## Data path

Use this data path:

```text
DMM microphone -> 32 kHz I2S source -> 2:1 resampler -> 16 kHz source -> voice_assistant
```
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

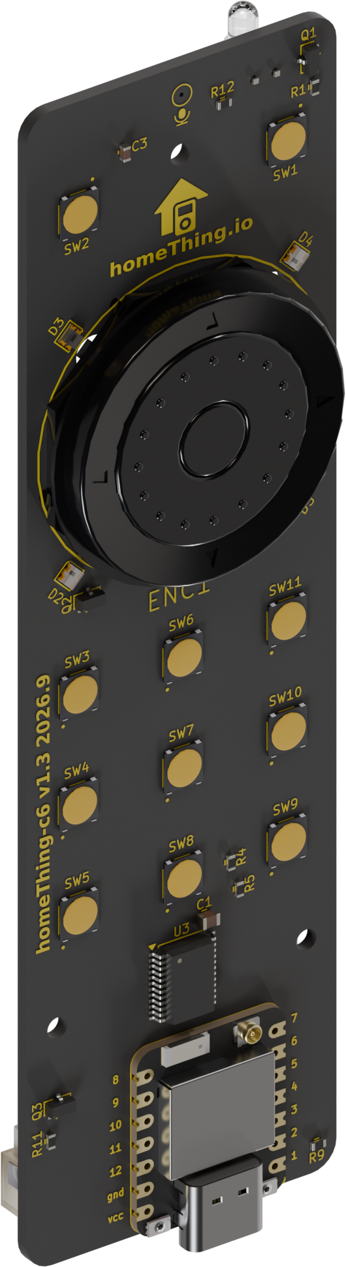
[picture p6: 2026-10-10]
docs/readme-assets/board-3d-rotated-top.png

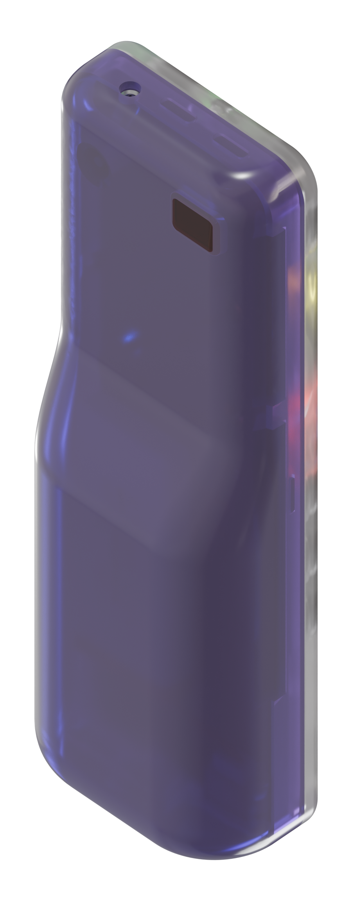
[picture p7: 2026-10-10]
docs/readme-assets/case-annotated-back.png

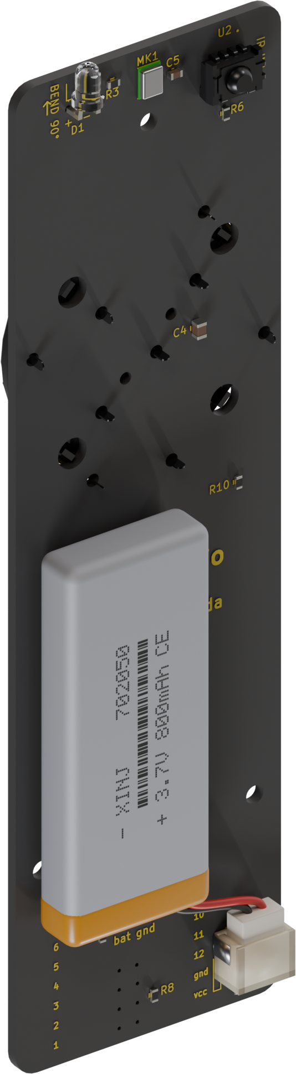
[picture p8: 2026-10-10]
docs/readme-assets/board-3d-rotated-bottom.png

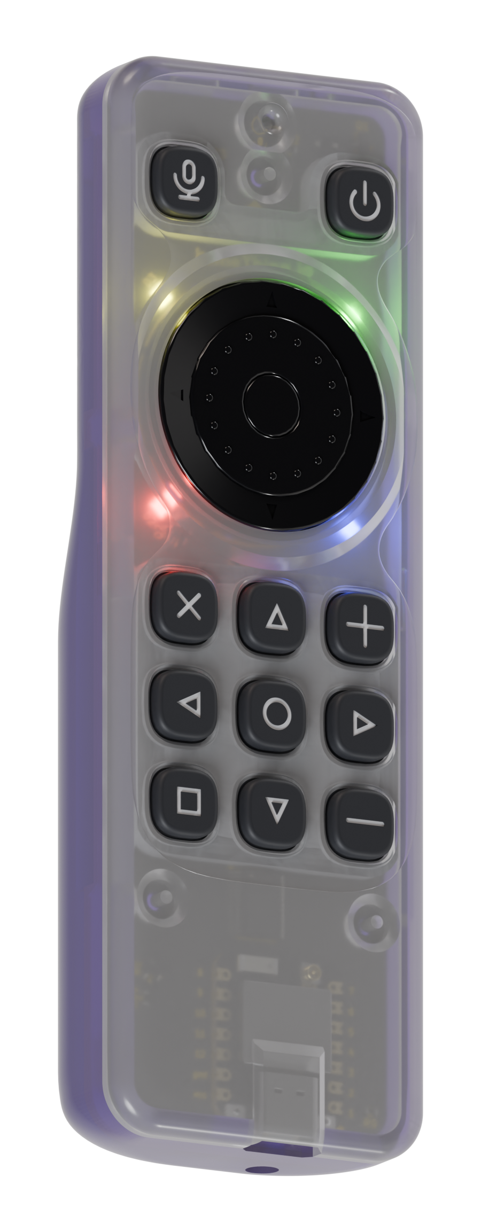
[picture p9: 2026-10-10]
docs/readme-assets/case-annotated-front.png

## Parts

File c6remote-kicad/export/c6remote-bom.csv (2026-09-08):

Reference | Qty | Value | Footprint | Datasheet | Description | Manufacturer | MPN | Digikey | Mouser | Adafruit | LCSC
C1, C4 | 2 | 1uF | Capacitor_SMD:C_0805_2012Metric |  | Capacitor: 1uF 50V X7R 0805 (decoupling),Capacitor: 1uF 50V X7R 0805 (led_vdd bulk, local charge for D2-D5) | Yageo | CC0805KKX7R9BB105 | https://www.digikey.com/en/products/detail/yageo/CC0805KKX7R9BB105/5195292 | https://www.mouser.com/ProductDetail/YAGEO/CC0805KKX7R9BB105
C3, C5 | 2 | 100nF | Capacitor_SMD:C_0603_1608Metric | ~ | Capacitor: 100nF 50V X7R 0603 (MK1 VDD decoupling),Capacitor: 100nF 50V X7R 0603 (U2 TSOP Vs filter) | Yageo | CC0603KRX7R9BB104 | https://www.digikey.com/en/products/detail/yageo/CC0603KRX7R9BB104/2103082 | https://www.mouser.com/ProductDetail/YAGEO/CC0603KRX7R9BB104
D1 | 1 | INL-3AHIR30 | Library:LED_D3.0mm_Horizontal_O1.27mm_Z2.0mm_IRBlack | http://www.inolux-corp.com/datasheet/IR/Emitter/3mm%20Lamp/INL-3AHIR30_V1.0.pdf | IR Emitter: 940nm 3mm THT LED (leads bent 90 deg to top-edge notch = IR aperture) | Inolux | INL-3AHIR30 | https://www.digikey.com/en/products/detail/inolux/INL-3AHIR30/10384806 | https://www.mouser.com/ProductDetail/Inolux/INL-3AHIR30
D2, D3, D4, D5 | 4 | XL-2020RGBC-WS2812B | Library:LED_XL-2020RGBC-WS2812B_PLCC4_2.0x2.0mm | https://mm.digikey.com/Volume0/opasdata/d220001/medias/docus/8903/5962_XL-2020RGBC-WS2812B.pdf | RGB LED: XL-2020RGBC-WS2812B addressable, integrated controller, 5mA/ch, VDD 3.5-5.5V, 2020 PLCC4 | XINGLIGHT | XL-2020RGBC-WS2812B | https://www.digikey.com/en/products/detail/xinglight/XL-2020RGBC-WS2812B/25672933 |  |  | https://www.lcsc.com/product-detail/C5349955.html
ENC1 | 1 |  | Library:Ano Rotary | https://cdn-learn.adafruit.com/assets/assets/000/104/942/original/tsw.pdf | Rotary Encoder: ANO directional navigation + scroll wheel | Adafruit | Adafruit 5001 | https://www.digikey.com/en/products/detail/adafruit-industries-llc/5001/15277532 | https://www.mouser.com/ProductDetail/Adafruit/5001 | https://www.adafruit.com/product/5001
J1 | 1 | Battery | Connector_JST:JST_PH_S2B-PH-SM4-TB_1x02-1MP_P2.00mm_Horizontal | ~ | Connector: battery, JST PH 2-pos SMD right-angle 2.0mm | JST | S2B-PH-SM4-TB(LF)(SN) | https://www.digikey.com/en/products/detail/jst-sales-america-inc/S2B-PH-SM4-TB-LF-SN/926655 | https://www.mouser.com/ProductDetail/JST-Commercial/S2B-PH-SM4-TBLFSN
MK1 | 1 | DMM-4026-B-I2S-R | Library:MIC_DMM-4026-B-I2S-R | https://api.puiaudio.com/filename/DMM-4026-B-I2S-R.pdf | Microphone: I2S MEMS, 24-bit, omnidirectional bottom port, 4.0x3.0mm | PUI Audio | DMM-4026-B-I2S-R | https://www.digikey.com/en/products/detail/pui-audio-inc/DMM-4026-B-I2S-R/11587483 | https://www.mouser.com/ProductDetail/PUI-Audio/DMM-4026-B-I2S-R
Q1 | 1 | MMBT2222A | Package_TO_SOT_SMD:SOT-23 | https://assets.nexperia.com/documents/data-sheet/MMBT2222A.pdf | Transistor: NPN 40V 600mA SOT-23 (IR LED driver) | Nexperia | MMBT2222A,215 | https://www.digikey.com/en/products/detail/nexperia-usa-inc/MMBT2222A-215/1156598 | https://www.mouser.com/ProductDetail/Nexperia/MMBT2222A215
Q2, Q3 | 2 | AO3401A | Package_TO_SOT_SMD:SOT-23 | https://www.aosmd.com/res/datasheets/AO3401A.pdf | Transistor: P-channel MOSFET -30V -4A SOT-23 (ir_vdd high-side switch),Transistor: P-channel MOSFET -30V -4A SOT-23 (led_vdd high-side switch) | Alpha & Omega Semiconductor | AO3401A | https://www.digikey.com/en/products/detail/alpha-omega-semiconductor-inc/AO3401A/1855773 |  |  | https://www.lcsc.com/product-detail/C15127.html
R1 | 1 | 470 | Resistor_SMD:R_0603_1608Metric |  | Resistor: 470R 1% 0.1W 0603 (Q1 base) | Yageo | RC0603FR-07470RL | https://www.digikey.com/en/products/detail/yageo/RC0603FR-07470RL/727256 | https://www.mouser.com/ProductDetail/YAGEO/RC0603FR-07470RL
R3 | 1 | 10 | Resistor_SMD:R_0603_1608Metric | ~ | Resistor: 10R 1% 0.1W 0603 (D1 IR LED current limit) | Yageo | RC0603FR-0710RL | https://www.digikey.com/en/products/detail/yageo/RC0603FR-0710RL/726879 | https://www.mouser.com/ProductDetail/YAGEO/RC0603FR-0710RL
R4, R5 | 2 | 4.7k | Resistor_SMD:R_0603_1608Metric | ~ | Resistor: 4.7k 1% 0.1W 0603 (I2C SDA/SCL pull-up) | Yageo | RC0603FR-074K7L | https://www.digikey.com/en/products/detail/yageo/RC0603FR-074K7L/727212 | https://www.mouser.com/ProductDetail/YAGEO/RC0603FR-074K7L
R6 | 1 | 100 | Resistor_SMD:R_0603_1608Metric | ~ | Resistor: 100R 1% 0.1W 0603 (U2 TSOP Vs filter) | Yageo | RC0603FR-07100RL | https://www.digikey.com/en/products/detail/yageo/RC0603FR-07100RL/726888 | https://www.mouser.com/ProductDetail/YAGEO/RC0603FR-07100RL
R7, R8, R9, R12 | 4 | 100k | Resistor_SMD:R_0603_1608Metric | ~ | Resistor: 100k 1% 0.1W 0603 (MK1 SD pull-down),Resistor: 100k 1% 0.1W 0603 (batt sense divider / INT pull-up) | Yageo | RC0603FR-07100KL | https://www.digikey.com/en/products/detail/yageo/RC0603FR-07100KL/726889 | https://www.mouser.com/ProductDetail/YAGEO/RC0603FR-07100KL
R10, R11 | 2 | 1M | Resistor_SMD:R_0603_1608Metric | ~ | Resistor: 1M 1% 0.1W 0603 (Q2 gate pull-up, holds led_vdd off by default),Resistor: 1M 1% 0.1W 0603 (Q3 gate pull-up, holds ir_vdd off by default) | Yageo | RC0603FR-071ML | https://www.digikey.com/en/products/detail/yageo/RC0603FR-071ML/726844 | https://www.mouser.com/ProductDetail/YAGEO/RC0603FR-071ML
SW1, SW2, SW3, SW4, SW5, SW6, SW7, SW8, SW9, SW10, SW11 | 11 | SW_Push | Library:SW_TL3315NF160Q | https://www.e-switch.com/wp-content/uploads/2022/06/TL3315.pdf | Switch: tactile pushbutton SPST-NO SMD | E-Switch | TL3315NF160Q | https://www.digikey.com/en/products/detail/e-switch/TL3315NF160Q/1870395 | https://www.mouser.com/ProductDetail/E-Switch/TL3315NF160Q
U1 | 1 | XIAO-ESP32-C6 | Seeed_Studio_XIAO_Series:XIAO-ESP32-C6-SMD | https://mm.digikey.com/Volume0/opasdata/d220001/medias/docus/8932/102010636.pdf | MCU Module: Seeed XIAO ESP32-C6, Wi-Fi 6 / BLE 5 / Zigbee / Thread | Seeed Studio | 113991254 | https://www.digikey.com/en/products/detail/seeed-technology-co-ltd/113991254/24613066 | https://www.mouser.com/ProductDetail/Seeed-Studio/113991254
U2 | 1 | TSOP6136 | Library:Vishay_PANHEAD-4Pin_TopView | https://www.vishay.com/docs/82457/tsop61.pdf | IR Receiver: remote control module, 36kHz | Vishay | TSOP6136TT | https://www.digikey.com/en/products/detail/vishay-semiconductor-opto-division/TSOP6136TT/4075852 | https://www.mouser.com/ProductDetail/Vishay-Semiconductors/TSOP6136TT
U3 | 1 | PCF8575DBR | Package_SO:SSOP-24_5.3x8.2mm_P0.65mm | https://www.ti.com/lit/ds/symlink/pcf8575.pdf | GPIO Expander: 16-bit I2C, SSOP-24 | Texas Instruments | PCF8575DBR | https://www.digikey.com/en/products/detail/texas-instruments/PCF8575DBR/754551 | https://www.mouser.com/ProductDetail/Texas-Instruments/PCF8575DBR

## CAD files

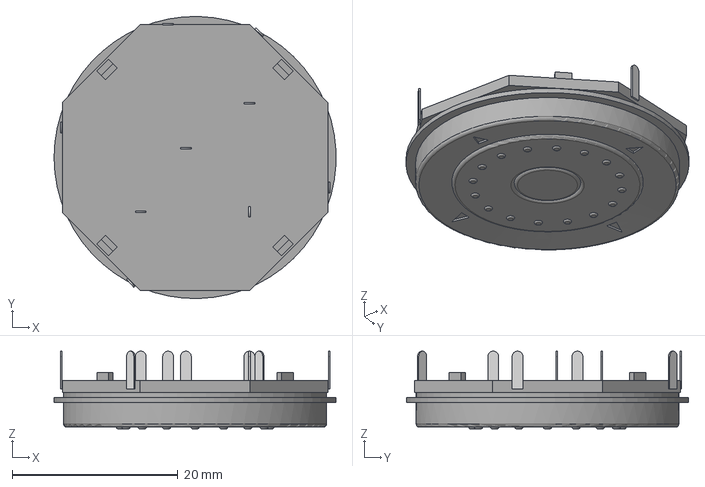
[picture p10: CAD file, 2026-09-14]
c6remote-kicad/3dmodels/5221 ANO Rotary Encoder.step
34.0 x 34.0 x 9.37 mm

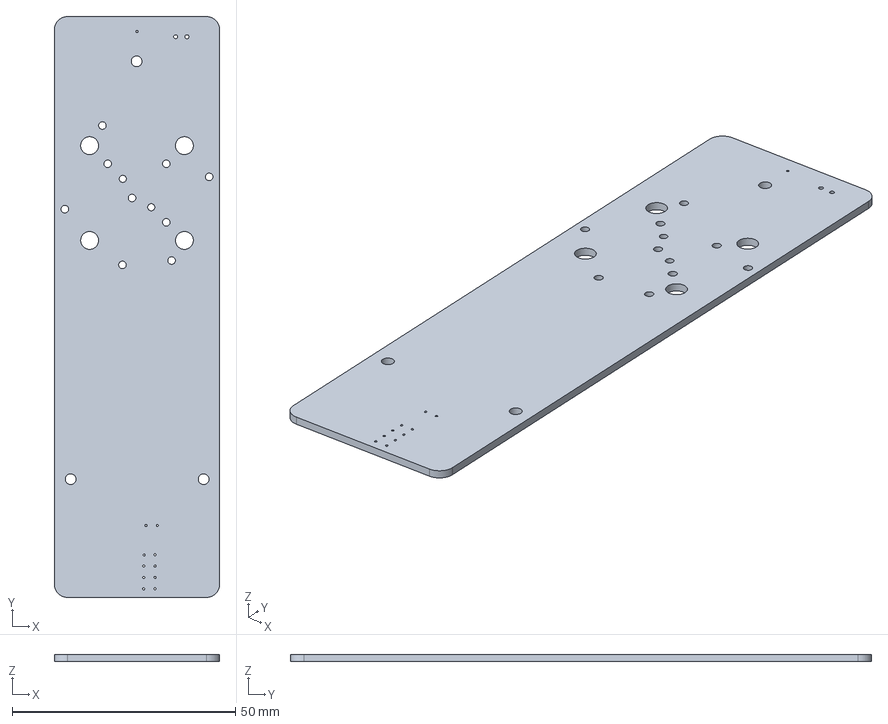
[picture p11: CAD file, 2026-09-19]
case/board/c6remote-board-only.step
37.0 x 130.0 x 1.51 mm

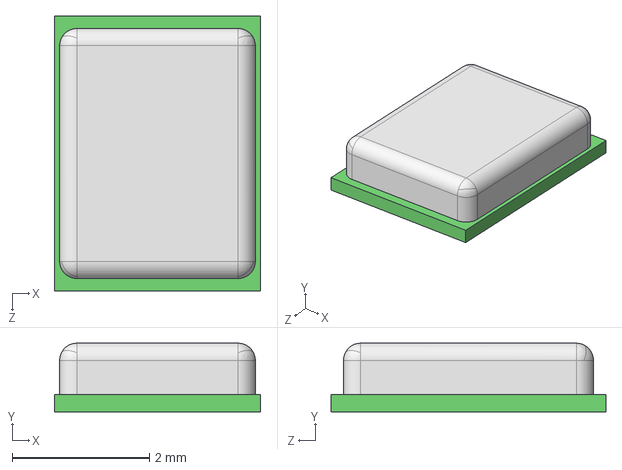
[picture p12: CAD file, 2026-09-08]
c6remote-kicad/3dmodels/DMM-4026-B-I2S-R.STEP
3.00 x 1.00 x 4.00 mm

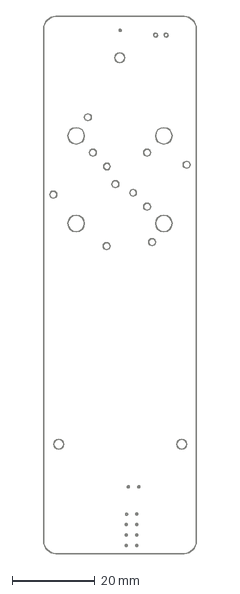
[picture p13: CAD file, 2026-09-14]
case/board/c6remote-outline.dxf
37.0 x 130.0 mm

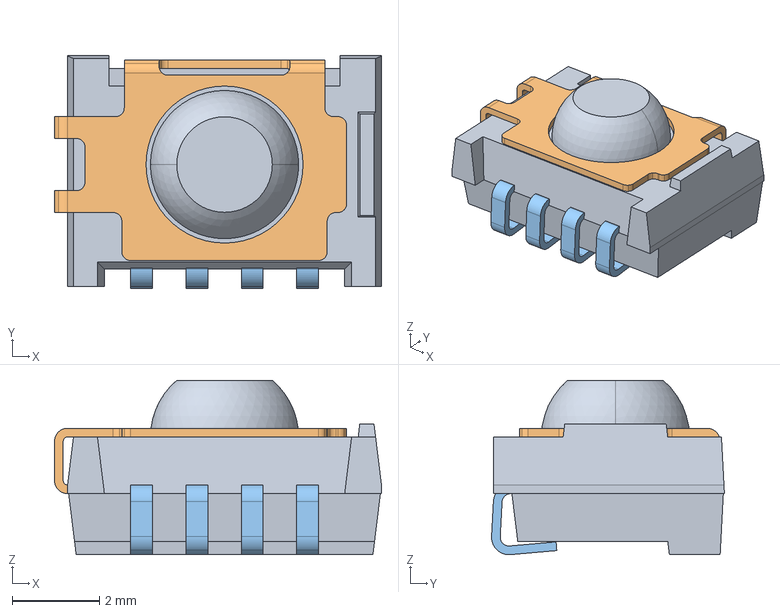
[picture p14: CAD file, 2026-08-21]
c6remote-kicad/3dmodels/TSOP6136TT.step
7.50 x 5.34 x 4.00 mm

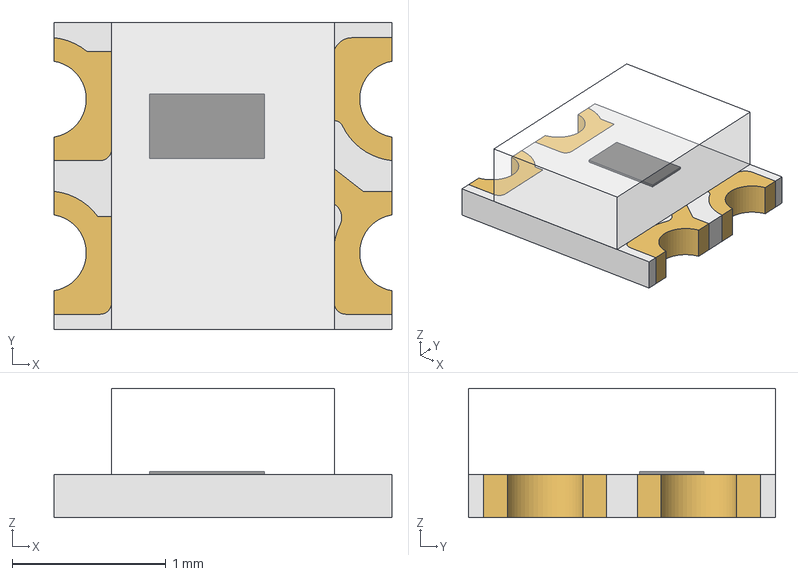
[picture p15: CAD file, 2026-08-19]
c6remote-kicad/3dmodels/WS2812C-2020.step
2.20 x 2.00 x 0.84 mm

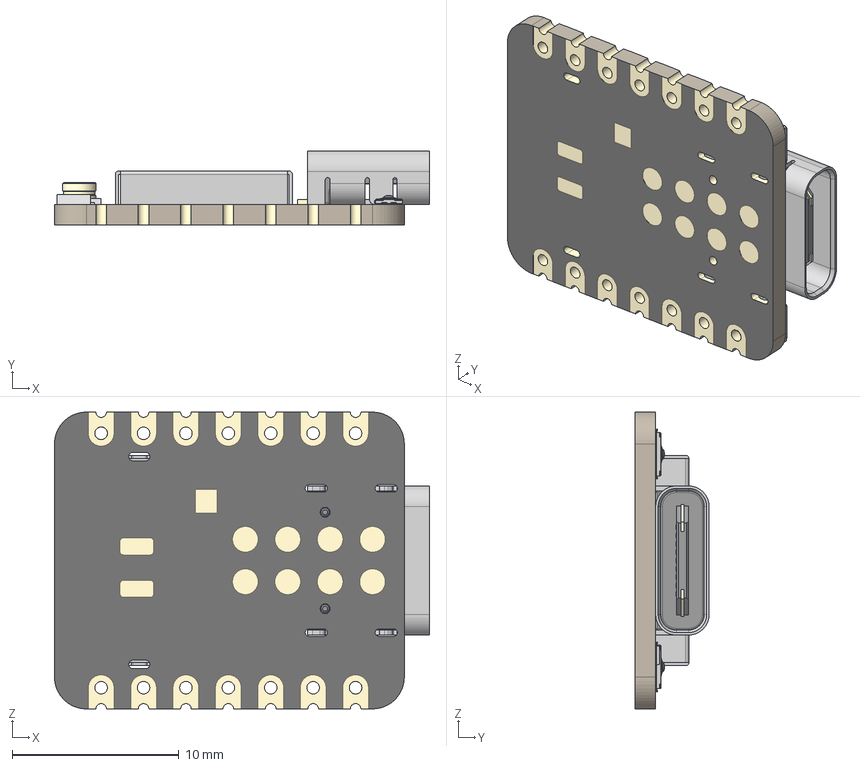
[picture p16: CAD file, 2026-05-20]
c6remote-kicad/3dmodels/Seeed Studio XIAO ESP32-C6.step
22.5 x 4.46 x 17.8 mm
BOSS-EXTRUDE14_8_
BOSS-EXTRUDE7_4_
BOSS-EXTRUDE7_3_
BOSS-EXTRUDE14_4_
BOSS-EXTRUDE14_2_
BOSS-EXTRUDE14_11_
BOSS-EXTRUDE7_7_
BOSS-EXTRUDE14_9_
BOSS-EXTRUDE14_3_
BOSS-EXTRUDE14_7_
MIRROR2
BOSS-EXTRUDE14_5_
BOSS-EXTRUDE14_12_
BOSS-EXTRUDE7_8_
BOSS-EXTRUDE7_1_
BOSS-EXTRUDE14_10_
BOSS-EXTRUDE7_9_
BOSS-EXTRUDE14_6_
BOSS-EXTRUDE14_1_
BOSS-EXTRUDE7_6_
BOSS-EXTRUDE7_2_
CUT-EXTRUDE5
BOSS-EXTRUDE7_5_
U.FL Connector v1
Shield
SKTAAAE010 x 2
KH5220-A36 (Ceramic Antenna) v2

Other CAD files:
c6remote-kicad/3dmodels/TSOP6136.step
case/board/c6remote-v2-board-only.step

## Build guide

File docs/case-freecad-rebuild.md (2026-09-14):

# Plan: rebuild front_shell as a native FreeCAD parametric part

## Context

The case model (`case/`, build123d) exports STL only. Goal: the enclosure editable in a GUI CAD app with a real feature timeline, where minor edits happen by mouse and larger edits go through AI. FreeCAD chosen over Fusion 360 and Onshape: a working MCP server lets Claude drive the live GUI session (same loop as KiCad MCP), the PartDesign tree is a real editable timeline, it shares the OCCT kernel with build123d so geometry converts faithfully, and the generator can run headless for regeneration. Scope: **front_shell only** to start, full native rebuild (real sketches, pads, pockets, revolutions, lofts, fillets), not imported BREP booleans.

The build stays scripted so the FreeCAD file regenerates from the board and never drifts from `board.py`/`params.py` (repo rule: never hand-transcribe board coordinates). The `.FCStd` file is a generated artifact; the manifest exporter is the source of truth.

**Requires FreeCAD 1.0 or newer.** 1.0 shipped the topological naming fix; without it, editing an upstream sketch scrambles downstream edge references (fillets, datum attachments) and the tree breaks on the first GUI edit, defeating the point.

Known fidelity caveat, accepted: the keypad recess is a smooth loft through roughly 90 stations of 65-point polylines (`case/model/keypad.py:432 dish_cut()`). FreeCAD rebuilds it as a Subtractive Loft through B-spline sections, so its floor is smoother than the polyline original by a few hundredths of a mm. Everything else maps exactly.

## Architecture: two stages

**Stage A, manifest exporter (runs in `case/.venv`, build123d available)**

- `case/model/freecad_manifest.py`: the exporter. Imports `board`, `params`, `model.stack`, `model.shape`, `model.keypad`, `model.mic`. Walks the same geometry the model is built from and emits an ordered JSON build manifest.
- `case/export_freecad_manifest.py`: thin CLI wrapper. Writes `case/export/freecad/front_shell.manifest.json`.
- Nothing hand-transcribed: profiles come from `shape._offset_face()` wires (walk each build123d Edge through its public API, `geom_type`, `arc_center`, `radius`, `position_at`; Line/Circle become exact line and arc segments, anything else becomes sampled spline points). Positions from `board.components()`, `board.refs("SW")`, `mount_points()`, `board.wheel_center()`. Z planes from `model/stack.py`. The existing outline DXF is not used; emitting the already-offset wires is strictly better.

**Stage B, FreeCAD generator (runs in FreeCAD's Python)**

- `case/freecad/build_front_shell.py`: reads the manifest, builds a PartDesign Body feature by feature, saves `front_shell.FCStd`, exports `front_shell_freecad.step`. Runs three ways: headless via the app bundle's `FreeCADCmd`, pasted into the GUI Python console, or driven live through the FreeCAD MCP server.
- `case/freecad/README.md`: run instructions for all three, plus MCP server setup.
- Case coordinate frame maps 1:1 to the document's global frame, units are mm on both sides, no conversion.

## Manifest schema (sketch)

```json
{ "version": 1, "units": "mm", "part": "front_shell",
  "params": {"SHELL_FRONT": ..., "CAVITY_FRONT": ..., "BOARD_TOP": ..., ...},
  "features": [
    {"name": "body", "type": "pad", "op": "join",
     "plane": {"z": {"value": ..., "expr": "SKIRT_BOTTOM"}},
     "profiles": [[{"line": [[x,y],[x,y]]}, {"arc": {...}}, {"spline": [[x,y],...]}]],
     "distance": {"value": ..., "expr": "SHELL_FRONT - SKIRT_BOTTOM"}},
    {"name": "top_fillet", "type": "fillet", "radius": {"expr": "EDGE_R_FRONT"},
     "edges": {"select": "top_face_perimeter", "z": "SHELL_FRONT"}},
    {"name": "mic_bore", "type": "revolution", "op": "cut", "axis": {...}, "profile": [...]},
    {"name": "keypad_recess", "type": "loft", "op": "cut",
     "sections": [{"plane": {"y": ...}, "floor_spline": [[x,z],...], "top_z": ...}, ...]},
    {"name": "led_ring_channel", "type": "tool_body", "op": "cut", "steps": [...]}
  ]}
```

Convenience primitives Stage B expands into sketch geometry: `circle`, `rect`, `rounded_rect`, `polyline`, `spline`. Every scalar carries `value` plus optional `expr` (spreadsheet expression, see parameters below).

## Feature mapping (ordered, mirrors `case/model/shells.py:271 front_shell()`)

| # | Source | FreeCAD feature |
|---|---|---|
| 1 | body slab, `shells.py:278`, profile from `shape.py` | Sketch on datum plane at SKIRT_BOTTOM, Pad to SHELL_FRONT |
| 2 | top perimeter fillet, `shells.py:279` | Fillet on the perimeter edge loop of the single upward planar face at z = SHELL_FRONT |
| 3 | inner cavity, `shells.py:283` | Pocket, BOARD_TOP - 0.01 to CAVITY_FRONT |
| 4 | `skirt_cuts()`, `shells.py:71` | 2 Pockets; annular profile is one sketch with two nested loops |
| 5 | `mic_duct()`, `mic.py:152` | Pad (circle), BOARD_TOP to SHELL_FRONT |
| 6 | `deep_skirt()`, `shells.py:160` (ring intersect box) | Stage A clips the annulus by the box in 2D at export time, single Pad; fallback tool_body (separate Body plus PartDesign Boolean) if the clip is not reducible |
| 7 | 2 `rails()`, `shells.py:94` (ruled 3-section loft) | Additive Loft for the lead-in plus Pad for the straight run (sections 2 and 3 identical) |
| 8 | 3 bosses, `shells.py:297` | one sketch, 3 circles, Pad BOARD_TOP to SHELL_FRONT |
| 9 | `usb_pocket()`, `usb.py:49` | Pocket (rect) |
| 10 | 3 pilots, `shells.py:332` | one sketch, Pocket (plain pocket, not Hole feature: multi-position, blind both ends) |
| 11 | 2 `catch_windows()`, `shells.py:168` | Sketch on Y-normal datum plane, Pocket |
| 12 | `wheel_opening()`, `wheel_ring.py:205` | Pocket circle CAVITY_FRONT - 1 to SHELL_FRONT + 1; exporter asserts the opening clip is idle at the current radius, tool_body fallback if not |
| 13 | `led_ring_channel()`, `wheel_ring.py:161` (revolve intersect live clip) | tool_body: separate Body holding a Revolution (trapezoid about the wheel axis) intersected with a padded clip region, then PartDesign Boolean cut into the main Body |
| 14 | `mic_bore()`, profile `mic.py:124` | one Groove (subtractive revolution) of the exact half-profile: throat line, taper, tangent arc at `mic_fillet_r()`, mouth line. Replaces the fuse-of-3-solids boolean, exact |
| 15 | 22 key prisms, `shells.py:323` (11 switches, counterbore plus face hole each) | 2 sketches of 11 rounded rects each, 2 Pockets (to COUNTERBORE_TOP, to SHELL_FRONT + 1) |
| 16 | `keypad_recess()`, `keypad.py:432,615` | Subtractive Loft through per-station sketches on Y-offset datum planes: B-spline floor plus verticals plus top line. `--stations N` decimation flag on the exporter (default all stations, practical around half); identical point count per section so loft correspondences behave |
| 17 | `shared_cuts()`, `shells.py:231`: `usb_slot`, `ir_window_opening`, `emitter_bore` | 3 Pockets from Y-normal datum planes |

MERGE overshoots kept verbatim (harmless in pads and pockets, keeps the manifest a faithful transcription).

## Key decisions

- **Fillet edge selection.** Replay order guarantees that at feature 2 exactly one upward planar face exists at z near SHELL_FRONT. The generator selects it geometrically (normal dot Z above 0.99, z within 1e-3), fillets all its edges (the single perimeter loop; no aperture edges exist yet, mirroring the by-construction argument in `shells.py:272-276`). Assert exactly one such face, abort loudly otherwise. Post-generation edits rely on FreeCAD 1.0 toponaming to keep the reference stable.
- **Parameters.** A `params` Spreadsheet object in the document holds the Z stack and thicknesses (SHELL_FRONT, CAVITY_FRONT, BOARD_TOP, SKIRT_BOTTOM, COUNTERBORE_TOP, SKIRT_H, WALL, BOARD_FIT, EDGE_R_FRONT, MIC_DUCT_OD, BOSS_OD, BOSS_PILOT_D). Pad and pocket lengths, datum plane offsets, and the fillet radius bind to spreadsheet expressions from the manifest's `expr` strings. All XY geometry (outline, switch positions, dish sections, key sizes) is baked numeric: it derives from the board and is not usefully editable in CAD.
- **Intersections.** Prefer 2D clipping at export time (deep_skirt). Use a separate Body plus PartDesign Boolean only where the clip is genuinely 3D (led_ring_channel).
- **Sketch capacity.** The dish sections and the board outline are large sketches (dozens of spline poles). Sketches are created unconstrained (geometry only, no constraint solving), which keeps document rebuild fast and avoids solver blowups. Constraints are not needed: the geometry is exact from the manifest, and GUI edits of these sketches are not the expected workflow.

## Verification

`case/freecad/verify_front_shell.py` (runs in the repo venv):

1. Stage B exports `front_shell_freecad.step`.
2. The verifier imports it with build123d and loads the reference front_shell BREP from `case/.cache` (rebuilding via `model.shells.front_shell()` on a cache miss).
3. Checks: bounding box extents within 0.05 mm each; volume within 0.3 percent; boolean symmetric-difference volume under 150 mm3 total AND under 10 mm3 outside a box around the keypad recess span (the dish alone absorbs the spline-vs-polyline tolerance).
4. Nonzero exit on failure, per-check numbers printed.

Regeneration loop after any board change: `scripts/export-case-refs.sh`, then `case/export_freecad_manifest.py`, then rerun the generator, then the verifier.

## Files to create

- `case/model/freecad_manifest.py` (exporter)
- `case/export_freecad_manifest.py` (CLI)
- `case/freecad/build_front_shell.py` (generator, runs in FreeCAD Python)
- `case/freecad/verify_front_shell.py` (verifier)
- `case/freecad/README.md` (run instructions: FreeCADCmd headless, GUI console, MCP)

## Implementation order

1. Stage A: wire-to-segments walker, then feature emitters in table order; manifest written and eyeball-checked.
2. Stage B: primitive expanders, datum plane and sketch helpers, feature replayers (pad, pocket, revolution, groove, loft, fillet, tool_body), spreadsheet creation, STEP export. Test headless first via FreeCADCmd.
3. Iterate: generate, verify, fix per-feature until thresholds pass.
4. MCP server setup and README last.

## Follow-ups out of scope

- back_shell, button_pad, ir_window, keycaps (same pipeline once front_shell proves it; back_shell's lofted form is the next hard case).
- An Assembly document placing all parts (FreeCAD 1.0 built-in Assembly workbench) once more than one part exists.

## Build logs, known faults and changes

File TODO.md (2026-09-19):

# Open tasks

## Finish the factory and release firmware work

Restore `stash@{0}` and complete its factory and release firmware changes.

The factory firmware uses `c6remote-test-v2.yaml`. The release firmware uses
`c6remote.yaml`.

## Remove the leftover `homething-c6-button-*` groups

The old training flow created one private Zigbee2MQTT group for each device
target. `homething-c6-button-9`, ID `0xC606`, still contains
`Kitchen Light Switch`, IEEE `0x54ef4410003ecd4c`.

Three private groups held that member after failed training runs. The
`homething-c6-button-3` and `homething-c6-button-8` members were removed on
2026-08-30. The `homething-c6-button-9` member was not.

The firmware no longer creates, joins, or reads these groups. A button now
stores a group ID that you pick in Zigbee2MQTT, so a leftover group cannot be
reached by accident. Removal is housekeeping, not a fix.

Delete each `homething-c6-button-*` group in the Zigbee2MQTT frontend. Confirm
first that no button on the `/buttons` page reports one of their IDs, `0xC600`
through `0xC611`.

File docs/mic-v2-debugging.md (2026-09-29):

# Rev B / V2 microphone debugging

This runbook covers Rev B/V2 boards with MK1, the ICS-43434 bottom-ported I2S microphone. It is a relative sound meter, not a calibrated SPL instrument.

**The design left this part on 2026-09-07.** `MK1` is now the PUI Audio `DMM-4026-B-I2S-R`. This runbook still applies to the five Rev B remotes in hand, because those boards carry the ICS-43434 and no new board exists yet. Read it as the record of why the part changed and as the procedure for the hardware you can hold. The swap is in [`docs/timeline.md`](timeline.md).

**Read this first, 2026-08-26.** The build has five Rev B remotes. One mic works. One works with distortion. Three do not work, measured 2026-08-26. All five boards share one design, one firmware and one fab batch, so no design cause can explain the spread. If a mic is deaf, compare it against the working unit and do not repeat the ruled-out ladder below. Read "Assembly damage is the leading suspect" first.

## Confirm hardware mapping

| Function | XIAO ESP32-C6 | MK1 / ICS-43434 |
| --- | --- | --- |
| BCLK / SCK | GPIO2 | pin 4 |
| WS / LRCLK | GPIO0 | pin 1 |
| DIN / SD | GPIO21 | pin 6 |
| L/R select | left channel | pin 2 tied to GND |
| Ground |  | pins 2 and 3 |
| Supply | 3.3 V | pin 5 |

The mic hears through its bottom acoustic port and the PCB NPTH. The port is at `(53.350, 31.582)` and is 0.5 mm in the current footprint. Apply sound at the front-side PCB hole and mic marking. A tap on the opposite-side package is not a valid acoustic test.

Rev A had a different, known ICS-43434 pin-numbering fault. Do not use that diagnosis for Rev B. The table above is the corrected netlist and firmware mapping.

## Understand I2S format

The ICS-43434 carries a 24-bit audio payload in 32-bit I2S slots. Keep the bus at 32-bit slots. The standalone test extracts the payload with `sample >> 8`. The ESPHome meter shifts to 16-bit with `sample >> 16`.

### Sample rate and clock are not suspects

Checked against `localdatasheets/DS-000069-ICS-43434-v1.2.pdf` on 2026-08-24. `c6remote.yaml` runs the mic at 16 kHz and the test configs use 48 kHz. Table 5 explains why that gap does not matter.

- Table 5 lists three sample rate bands: sleep under 3.125 kHz, Low-Power 6.25 to 18.75 kHz, High-Performance 23 to 51.6 kHz. 16 kHz is a supported mode, not an out-of-spec corner.
- Table 3 gives Low-Power the same sensitivity as High-Performance, -26 dB FS typical at 94 dB SPL. A move from 48 kHz to 16 kHz costs SNR (64 dBA against 65 dBA) and nothing else. It does not explain a quiet mic.
- Page 12 requires 64 SCK cycles per WS frame. So 16 kHz gives SCK 1.024 MHz, tSCP 977 ns, and 48 kHz gives 3.072 MHz, tSCP 326 ns. Table 5 allows 303 to 2500 ns. Both are legal.

Do not spend time on the sample rate. If capture runs at all, the clock is legal.

The band that fs falls in is the only control over the mic mode, and 18.75 to 23 kHz belongs to no band. Never set a rate there.

## First ESPHome check

This section records the check of 2026-08-24. Production `c6remote.yaml` no longer has the test button, the 1 s log line, or the `Mic SD Pulldown` switch.

To repeat the check, use `c6remote-test-mic-vu.yaml`. It logs `B/s` and peak each second and has the `Mic SD Pulldown` switch.

On 2026-08-24, `c6remote.yaml` had a `Start Microphone Test` button that called `microphone.capture`. The log line

```text
Captured 64512 bytes/s
```

proves that capture runs and DMA delivers data. `passive: false` is needed only for an ESPHome `sound_level` sensor, and this config does not use that platform. It does not explain low peaks.

The logged `level` was not reliable. The config multiplied `mic_level` by `0.82` on every `on_data` callback, approximately every 16 ms. The log printed the value only once per second, so the value decreased to near zero between lines. Production `c6remote.yaml` no longer has `mic_level`. Use `peak`, or the standalone test.

Convert `peak` to dB FS with `20 * log10(peak / 32768)`, because the meter is in the 16-bit domain. Landmarks:

| `peak` | dB FS | What it is |
| --- | --- | --- |
| 9 to 15 | -71 to -67 | Quiet room tone on a healthy mic |
| 50 | -56 | Best speech seen on the blocked-port board, 2026-08-24 |
| 550 | -35 | Close speech target, and what a button press produces |
| 32767 | 0 | Full scale |

`gain_factor` on the `voice_assistant` microphone source does **not** appear in this meter. The `on_data` trigger fires on the `Microphone`, upstream of the `MicrophoneSource` that applies gain. So `gain_factor` changes what Home Assistant receives and leaves the logged `peak` the same. The meter is not proof that a gain change did nothing.

## Use the button press as a positive control

Every capture that starts from a physical button shows a large peak in the first log line, 446 to 575, then drops to room tone. That is the press through the PCB into the diaphragm as structure-borne shock, not sound.

It is the most useful number in the log, because 550 is about -35 dB FS, the exact level close speech must produce. If the first line reads 446 to 575 and later lines read 9 to 15 while you talk into the port, this is proof:

- The diaphragm moves and the ADC responds.
- The 24-in-32 decode, the `>> 16` shift, DMA, and the ESPHome meter all carry -35 dB FS intact.
- So the digital path carries a large signal, and the loss is in front of the diaphragm.

That one comparison separates "deaf" from "broken" with no test equipment and no reflash. Do this first. It appears only on button-initiated captures, so a capture from Home Assistant or an automation will not show it.

One limit on this proof. A press has no known SPL, so the test shows that the path carries a large signal. It does not show that the path carries the correct absolute level. A uniform digital attenuation scales the press down with everything else and so hides inside this test. A 4-bit slot misalignment, for one, costs exactly -24 dB against a measured deficit of about 21 dB. Only a known-good microphone separates those two cases.

## Substitute a known-good microphone

This is the one test that splits every remaining hypothesis, and it needs no code change. Wire an INMP441 or ICS-43434 breakout module to GPIO2, GPIO0, and GPIO21, then run the standalone firmware without edits.

- The breakout reads correct levels: firmware, slot alignment, clocks, and mic mode are all exonerated. The fault is the soldered `MK1` or its port.
- The breakout is also about 21 dB down: the fault is in firmware after all, and slot alignment is the first thing to examine.

An INMP441 is a valid substitute even though the board carries an ICS-43434. Both parts use the same 24-in-32 Philips framing, so identical firmware drives either one.

## Expected levels from the datasheet

The baselines that follow are empirical. This is the absolute expectation, so one utterance can judge a board.

Sensitivity is -26 dB FS at 94 dB SPL and the scale is linear (Figure 7). Subtract the SPL shortfall:

| Stimulus | Approx SPL | Expected peak, dB FS | Expected `peak` |
| --- | --- | --- | --- |
| Talking into the port, a few cm | 85 | -35 | ~550 |
| Normal speech at 30 cm | 70 | -50 | ~100 |
| Normal speech at 1 m | 60 | -60 | ~33 |
| Datasheet noise floor, RMS A-weighted | | -90 | ~1 |

A level more than 15 dB under the matching row is an acoustic fault, not a config fault. On 2026-08-24 the board read -56 dB FS with a voice at the port, about 21 dB short. That held across every combination of sample rate, `gain_factor`, and pull-down. Firmware cannot recover that.

## What is already ruled out

Do not test these again. All are measured, and all are negative.

| Suspect | Verdict | Why |
| --- | --- | --- |
| Bit depth | Not a fault | `MicrophoneSource::process_audio_` converts 32 to 16 by itself |
| Sample rate and mic mode | Not a fault | Both modes are -26 dB FS, Table 3. The modes differ by 1 dBA of SNR |
| `gain_factor` | Cannot correct it | It applies after the mic, so it scales signal and floor together |
| Missing 100k `sd` pull-down | Real defect, not the cause | Bench A/B on 2026-08-24 read 9 to 53 either way. The tristate window lands in the low 8 bits that `>> 16` discards. See `ROADMAP.md` |
| Missing `MK1` 0.1uF decoupling | Real defect, not the cause | Raised 2026-08-25. The nearest `+3.3V` cap is `C1`, 92.75 mm away. It explains about 10 dB of excess floor. It cannot subtract 21 dB of signal. See `ROADMAP.md` |
| Absent acoustic port drill | Ruled out | The drill is in the fab output, checked 2026-08-24. See the inspection section |

No supply fault can be the cause, for three reasons. Sensitivity is flat from 1.65 to 3.63 V. The part is digital, so its output is a fixed-point sample and not an analog level. The button-press transient reads a full -35 dB FS through this same undecoupled supply. Supply noise raises the floor, but it cannot subtract signal.

## Assembly damage is the leading suspect

Three facts support this. The first is our own, and it is the strongest.

First, the fault selects between identical boards. Of five Rev B remotes, one mic works, one works with distortion, and three do not work, measured 2026-08-26. One design, one firmware and one fab batch produced all five results. So the cause is per unit and it is a process or a handling step. This also confirms the two verdicts in the table above rather than reopening them. Every board carries the same missing `sd` pull-down and the same missing 0.1uF cap. So neither defect can separate a working unit from a dead one. The spread also reproduces in-house the graded range the PCBWay report describes below, from excessive noise to no response.

Second, the part has a public failure record with exactly our symptoms. Two people on the ESPHome Discord built their own ICS-43434 boards and got data, correct clocks, and no acoustic response. The first report is from Dwains of SmartHomeShop.io, [in the ESPHome Discord](https://discord.com/channels/429907082951524364/1195816357523103885/1195834560567578644). All three of their boards were PCBWay-assembled, and all three were dead.

They ran a known-good Arduino sketch and ESPHome, measured 3.3 V clean at the pin, and confirmed the PCB port hole was open. After three boards and a week of work they gave up and respun with a different microphone. They also proved the ESP32 and the pins were good by wiring an external INMP441 breakout to the same pins, where it worked. A second person then reported the same failure on a different schematic with different pins.

Both had the 0.1uF decoupling cap that our board lacks, so a missing cap does not separate a working board from a broken one. Note the link needs ESPHome Discord membership to open.

A third report sits on [PCBWay's own site](https://www.pcbway.com/project/question/Noisy_audio_from_ICS_43434.html), and it is the strongest of the three. That builder put several ICS-43434 parts on one ESP32-S3 board, 75 mm apart, and 6 boards out of 10 failed. The symptom is "one of the microphones either produces excessive noise or does not respond at all". The question is still open.

Two details there carry more weight than the raw count. Some microphones fail while others on the same board work. Those parts share one schematic, one firmware, one reflow pass and identical nets, so a design fault cannot select between them. Random failure across identical circuits points at handling or process instead.

The other detail is the shape of the fault. "Excessive noise or no response" describes a range, and electrical faults are binary. Contamination is graded. This board sits in the middle of that range at 21 dB down, and the three Discord boards sat at the dead end. That builder saw both ends inside one batch.

Third, TDK forbids the cleaning steps that a contract assembler runs by default. `AN-100`, the handling guide our datasheet defers to, is blunt on page 2:

> The MEMS microphone package has a port hole opening that is sensitive to solder flux. Do not use a vapor phase soldering process. The MEMS microphone can be damaged if subjected to cleaning processes. The cleaning solvents can enter through the port hole and damage the device.

`AN-100` also says "Do not clean MEMS sensors in ultrasonic baths". Page 18 of `DS-000069` repeats the rule for the board level: "When washing the PCB, ensure that water does not make contact with the microphone port. Do not use blow-off procedures or ultrasonic cleaning."

Every one of those prohibitions maps onto a step that PCBWay describes in its own cleaning article: an ultrasonic bath, a multi-stage deionized water rinse, and compressed air drying. PCBWay also states that its factory "primarily uses rosin-based flux", which is not a no-clean flux and so implies a cleaning step. PCBWay publishes ten assembly stages, but no cleaning policy, no MSL or bake procedure, and no reflow profile. So what happened to this board is unknown rather than documented.

This board is the worst case for that mechanism. The 0.5 mm NPTH is a channel, not an incidental hole. `MK1` sits on `B.Cu` with its port facing up into the board. So the hole runs from the exposed top face straight into the acoustic port, and the package seals the far end. The result is a blind cavity. Liquid that enters from the top cannot drain and cannot air-dry, and dried residue leaves a permanent acoustic restriction. That fits a mic 21 dB down better than it fits a dead one. The Discord boards that were fully dead fit the same mechanism at a larger dose.

Two gaps worth closing. `AN-100` Table 2 predates the ICS-43434, and neither that table nor `DS-000069` gives this part an MSL rating, so the correct bake procedure is unknown. And the peak reflow limit is 260°C for a part under 1.6 mm thick. Nothing in this repo has checked that against a real vendor profile.

## Next-revision microphone candidates

| Candidate | Interface and ESPHome | Package and process | Decision |
| --- | --- | --- | --- |
| `ICS-43434` | I²S works on ESP32-C6 at 16 or 48 kHz | Bottom port, 3.5 x 2.65 mm, no wash | Rejected 2026-09-07 |
| `DMM-4026-B-I2S-R` | I²S works on ESP32-C6 at 48 kHz | Bottom port, 4.0 x 3.0 mm, seven pads, MSL1 | **Selected 2026-09-07.** It keeps the blind cavity |
| `SPH0645LM4H-B` | I²S works on ESP32-C6 | Bottom port, 3.5 x 2.65 mm, MSL1 | Reject because the part is obsolete |
| Top-port PDM microphone | ESPHome supports PDM only on ESP32 and ESP32-S3 | Top port removes the PCB acoustic hole | Requires a move from ESP32-C6 to ESP32-S3 |

The `DMM-4026-B-I2S-R` requires 24-bit data in 32-bit words. Its 18-bit precision does not change the ESPHome configuration.

Set ESPHome to `sample_rate: 48000`, `bits_per_sample: 32bit`, and `pdm: false`. This setting produces the required 3.072 MHz bit clock.

Tie `CONFIG` and `LR` to ground for left-channel operation. Fit 0.1 uF from VDD to ground and 100 kOhm from SD to ground.

Do not reuse the ICS-43434 footprint. The `DMM-4026-B-I2S-R` uses a different body, land pattern, pin count, and acoustic-port position.

All of the paragraph above is done as of 2026-09-07, with one exception. `c6remote.yaml` still runs the mic at 16 kHz, which is a 1.024 MHz bit clock and below the 2.048 MHz normal-mode minimum of the new part. That change waits for a board that carries the part. The item is in [`ROADMAP.md`](../ROADMAP.md).

## Firmware-independent test

The standalone ESP-IDF test removes ESPHome, Wi-Fi, voice assistant, LED, and meter logic. Source and wiring are in [`firmware/mic-test-idf/README.md`](../firmware/mic-test-idf/README.md).

From the repository root, with the managed PlatformIO Core:

```sh
cd firmware/mic-test-idf
~/.platformio/penv/bin/pio run
~/.platformio/penv/bin/pio run -t upload --upload-port /dev/cu.usbmodem2101
~/.platformio/penv/bin/pio device monitor --port /dev/cu.usbmodem2101 --baud 115200
```

Replace the serial device after you run `ls /dev/cu.usbmodem*`. The test reports one line per second:

```text
bytes=65536 samples=16384 peak24=18420 rms=1260.4 dbfs=-76.46 zeros=3 min=-17211 max=18420
```

Each line reports `4 * fs` bytes and `fs` samples, with nonzero noise and few zero samples. On the tested Rev B board, idle was `peak24` 2,000 to 5,000, RMS 600 to 900, and `dbfs` -80 to -81. This is a baseline, not a pass/fail spec.

The firmware runs 48 kHz, High-Performance mode, by default. The boot line reports the active mode. Set `MIC_SAMPLE_RATE_HZ` to 16000 to match what `c6remote.yaml` ships, because the ESPHome voice assistant needs 16 kHz and so always runs Low-Power.

That idle floor of -80 sits about 10 dB over the datasheet -90. The missing decoupling cap and a 92 mm unfiltered supply run account for it. This is excess noise, and it is separate from the 21 dB signal deficit.

### Listen to it

The same firmware dumps a 2 second WAV every cycle. That settles what a meter cannot: speech, hum, clipping, or one settling ramp. Run the host reader while the firmware loops, per [`../scripts/mic-capture.md`](../scripts/mic-capture.md):

```sh
python3 scripts/capture_usb_pcm.py /dev/cu.usbmodem2101 mic.wav
```

Read the level from the device `capture done: peak24=... dbfs true` line, not from the WAV. The file is scaled 24 dB above unity so a quiet board is audible, so the WAV overstates the mic by that much.

The C6 has only the fixed-function USB Serial/JTAG, no USB-OTG, and this board has no SD slot. So it cannot present a USB drive or a USB audio device. Audio leaves over the serial link or through `esptool read_flash`, and no other way.

## Apply stimulus and interpret result

1. Start the monitor. Let idle values settle for several lines.
2. Speak close to, or gently blow across, the front-side acoustic hole.
3. Tap the PCB near the hole, not the mic package backside.
4. Compare `peak24` and `rms` under stimulus against idle.

Interpretation:

- Bytes and samples near target, `zeros` far under `samples`: clocks, DMA, and SD are active.
- `zeros == samples`: examine power, GPIO mapping, I2S mode, and SD continuity. The mic can be in standby without a valid clock.
- A clear rise above idle: the digital path works. Remaining work is calibration, placement, or enclosure acoustics.
- Readings near idle, under `peak24` 5,000 and about -80 dBFS: suspect a blocked port, assembly residue, a damaged port, or a dead mic. A close tap or voice must cause a large relative change, even though absolute values depend on distance and enclosure.
- A slow monotonic climb, in place of a spike per word, does not track your voice. Speech is bursty: peaks jump on syllables and drop between them. A smooth ramp over ten or more seconds is a leakage or settling path, not a poor port. It appeared twice on 2026-08-24, from 11 to 53.

Do not read sound level from `bytes/s`. It measures transport rate, not acoustic amplitude.

## Safe physical inspection

Inspect the front NPTH with magnification and backlight. Make sure it is open through the board, and not covered by solder, flux, adhesive, case material, or debris. Use only gentle air across the opening.

CAUTION: Do not put probes or wire into the mic port. Do not use high-pressure air or solvent on the mic. Each of these destroys the diaphragm.

Rule out two things before you blame the hole. The port is a through-hole and `MK1` sits on `B.Cu`, so the package seals the bottom end. The only open face is the top, and sound must enter there. A board on a desk, foam, or a misaligned case floor seals that face, so hold it in free air.

The drill is in the fab output, checked 2026-08-24: `export/c6remote.drl` tool `T5C0.500`, tagged `NonPlated,NPTH,ComponentDrill`, one hit at `X53.35 Y-31.582`. So a blocked port on an assembled board is residue, not a missing hole.

## Restore ESPHome

After a test, from the repository root, reflash the normal config:

```sh
esphome run c6remote.yaml --device /dev/cu.usbmodem2101
```

Then press `Start Microphone Test` before you judge ESPHome capture logs. Recheck the serial device if reset changes it.

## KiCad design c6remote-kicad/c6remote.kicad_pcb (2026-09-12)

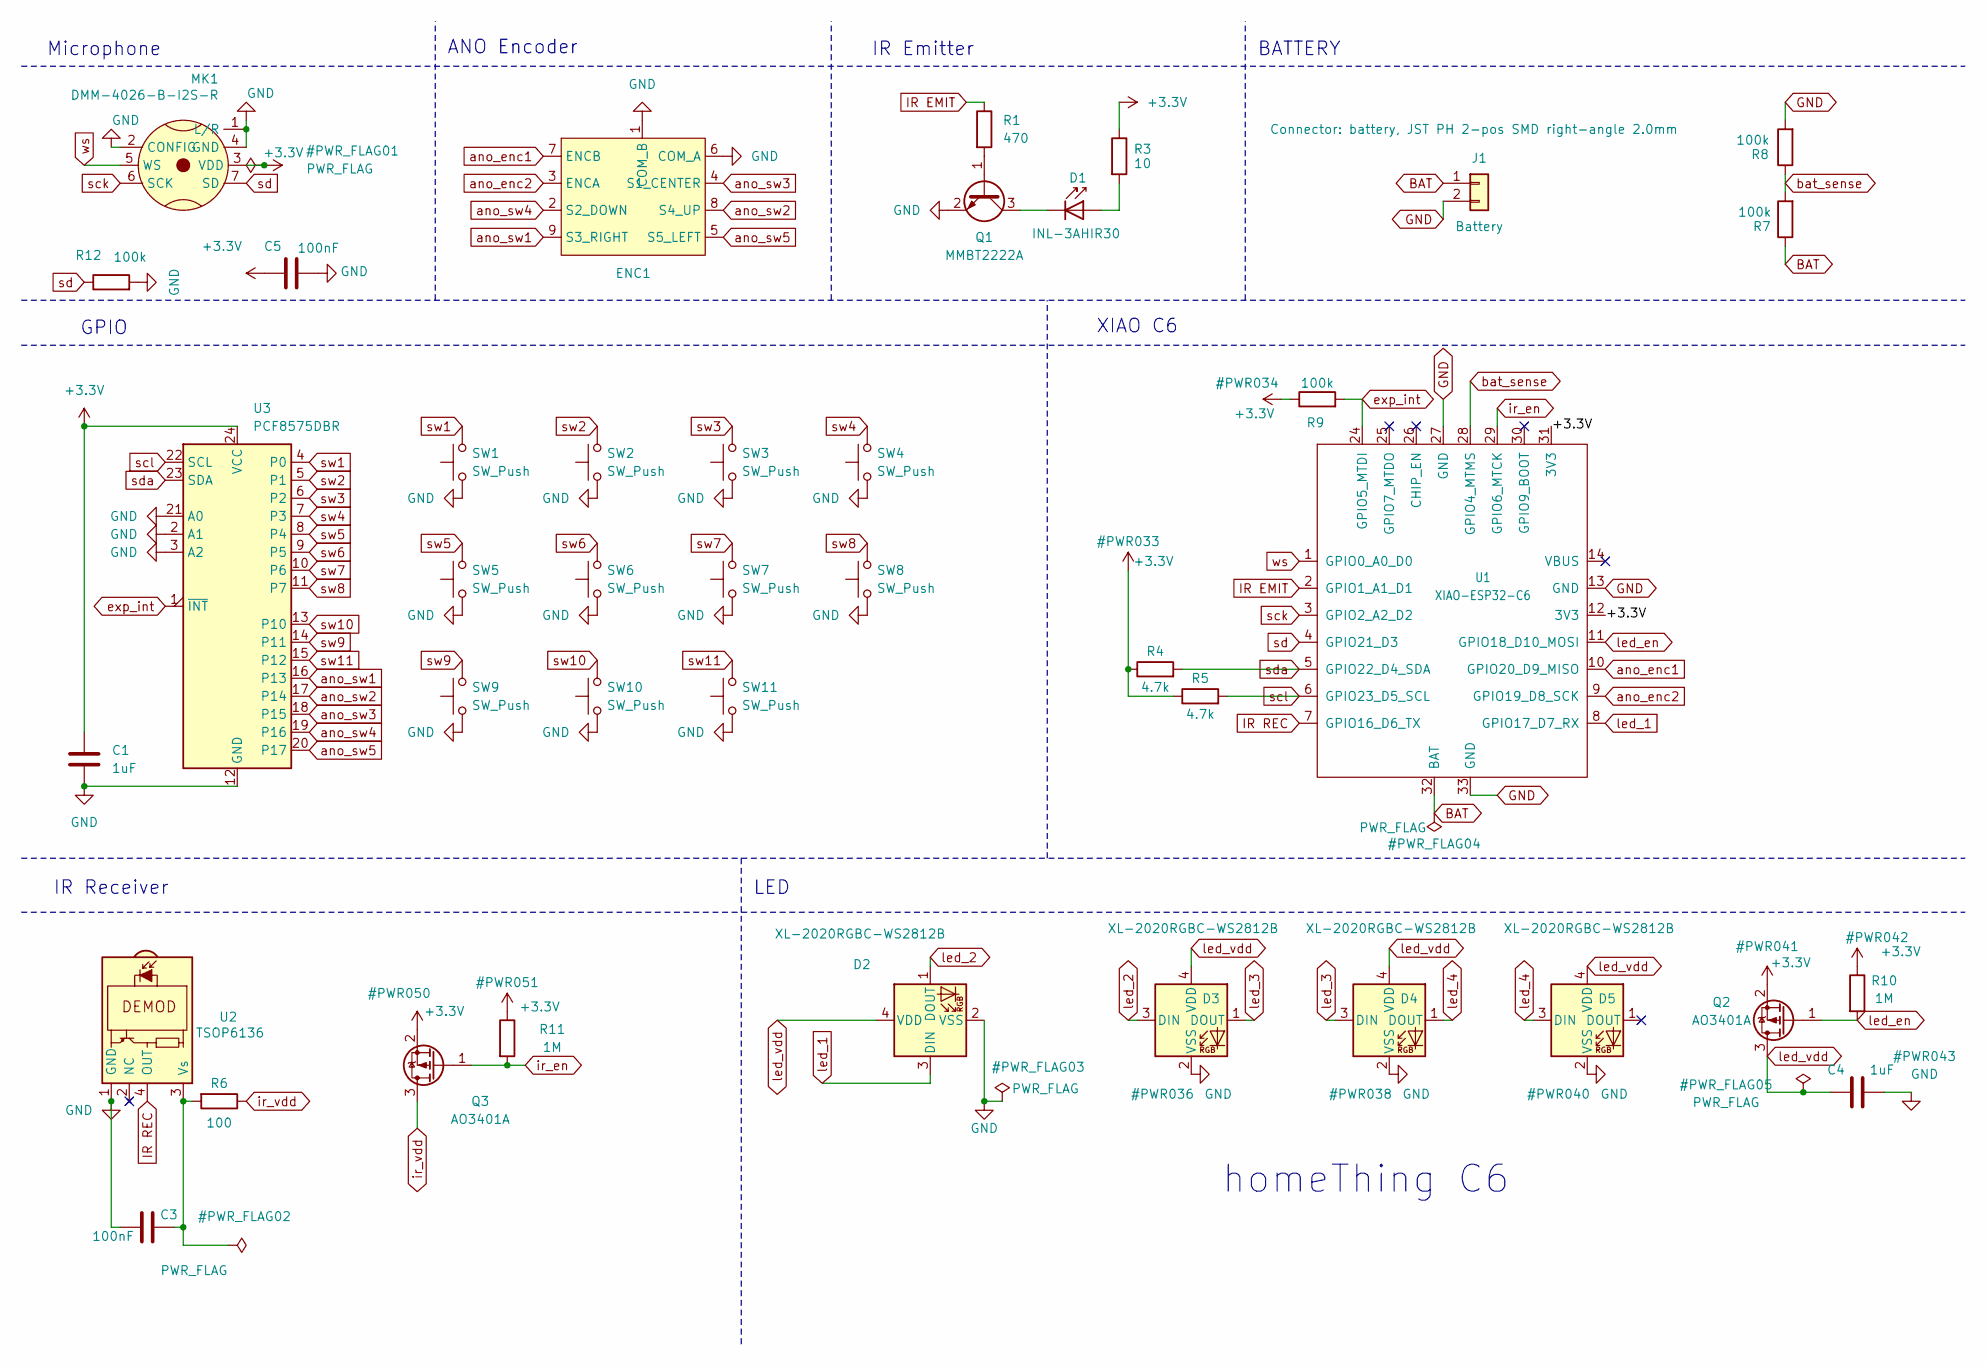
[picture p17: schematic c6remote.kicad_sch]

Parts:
C1, C4: 1uF; C_0805_2012Metric; MPN CC0805KKX7R9BB105
C3, C5: 100nF; C_0603_1608Metric; MPN CC0603KRX7R9BB104
D1: INL-3AHIR30; LED_D3.0mm_Horizontal_O1.27mm_Z2.0mm_IRBlack; MPN INL-3AHIR30
D2, D3, D4, D5: XL-2020RGBC-WS2812B; LED_XL-2020RGBC-WS2812B_PLCC4_2.0x2.0mm; MPN XL-2020RGBC-WS2812B
ENC1: Ano Rotary; MPN Adafruit 5001
J1: Battery; JST_PH_S2B-PH-SM4-TB_1x02-1MP_P2.00mm_Horizontal; MPN S2B-PH-SM4-TB(LF)(SN)
MK1: DMM-4026-B-I2S-R; MIC_DMM-4026-B-I2S-R; MPN DMM-4026-B-I2S-R
Q1: MMBT2222A; SOT-23; MPN MMBT2222A,215
Q2, Q3: AO3401A; SOT-23; MPN AO3401A
R1: 470; R_0603_1608Metric; MPN RC0603FR-07470RL
R3: 10; R_0603_1608Metric; MPN RC0603FR-0710RL
R4, R5: 4.7k; R_0603_1608Metric; MPN RC0603FR-074K7L
R6: 100; R_0603_1608Metric; MPN RC0603FR-07100RL
R7, R8, R9, R12: 100k; R_0603_1608Metric; MPN RC0603FR-07100KL
R10, R11: 1M; R_0603_1608Metric; MPN RC0603FR-071ML
SW1, SW2, SW3, SW4, SW5, SW6, SW7, SW8, SW9, SW10, SW11: SW_Push; SW_TL3315NF160Q; MPN TL3315NF160Q
U1: XIAO-ESP32-C6; XIAO-ESP32-C6-SMD; MPN 113991254
U2: TSOP6136; Vishay_PANHEAD-4Pin_TopView; MPN TSOP6136TT
U3: PCF8575DBR; SSOP-24_5.3x8.2mm_P0.65mm; MPN PCF8575DBR

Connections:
IR EMIT: R1.1, U1.2 (GPIO1_A1_D1)
IR REC: U1.7 (GPIO16_D6_TX), U2.4 (OUT)
unnamed: D1.2 (A), R3.2
unnamed: D1.1 (K), Q1.3 (C)
unnamed: Q1.1 (B), R1.2
ano_enc1: ENC1.7 (ENCB), U1.10 (GPIO20_D9_MISO)
ano_enc2: ENC1.3 (ENCA), U1.9 (GPIO19_D8_SCK)
ano_sw1: ENC1.9 (S3_RIGHT), U3.16 (P13)
ano_sw2: ENC1.8 (S4_UP), U3.17 (P14)
ano_sw3: ENC1.4 (S1_CENTER), U3.18 (P15)
ano_sw4: ENC1.2 (S2_DOWN), U3.19 (P16)
ano_sw5: ENC1.5 (S5_LEFT), U3.20 (P17)
bat_sense: R7.2, R8.1, U1.28 (GPIO4_MTMS)
exp_int: R9.2, U1.24 (GPIO5_MTDI), U3.1 (~INT)
ir_en: Q3.1 (G), R11.2, U1.29 (GPIO6_MTCK)
ir_vdd: Q3.3 (D), R6.1
led_1: D2.3 (DIN), U1.8 (GPIO17_D7_RX)
led_2: D2.1 (DOUT), D3.3 (DIN)
led_3: D3.1 (DOUT), D4.3 (DIN)
led_4: D4.1 (DOUT), D5.3 (DIN)
led_en: Q2.1 (G), R10.2, U1.11 (GPIO18_D10_MOSI)
sck: MK1.6 (SCK), U1.3 (GPIO2_A2_D2)
scl: R5.2, U1.6 (GPIO23_D5_SCL), U3.22 (SCL)
sd: MK1.7 (SD), R12.1, U1.4 (GPIO21_D3)
sda: R4.2, U1.5 (GPIO22_D4_SDA), U3.23 (SDA)
sw1: SW1.3, SW1.4, U3.4 (P0)
sw2: SW2.3, SW2.4, U3.5 (P1)
sw3: SW3.3, SW3.4, U3.6 (P2)
sw4: SW4.3, SW4.4, U3.7 (P3)
sw5: SW5.3, SW5.4, U3.8 (P4)
sw6: SW6.3, SW6.4, U3.9 (P5)
sw7: SW7.3, SW7.4, U3.10 (P6)
sw8: SW8.3, SW8.4, U3.11 (P7)
sw9: SW9.3, SW9.4, U3.14 (P11)
sw10: SW10.3, SW10.4, U3.13 (P10)
sw11: SW11.3, SW11.4, U3.15 (P12)
ws: MK1.5 (WS), U1.1 (GPIO0_A0_D0)

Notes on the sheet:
BATTERY
XIAO C6
homeThing C6
IR Emitter
ANO Encoder
IR Receiver
Microphone
GPIO
LED

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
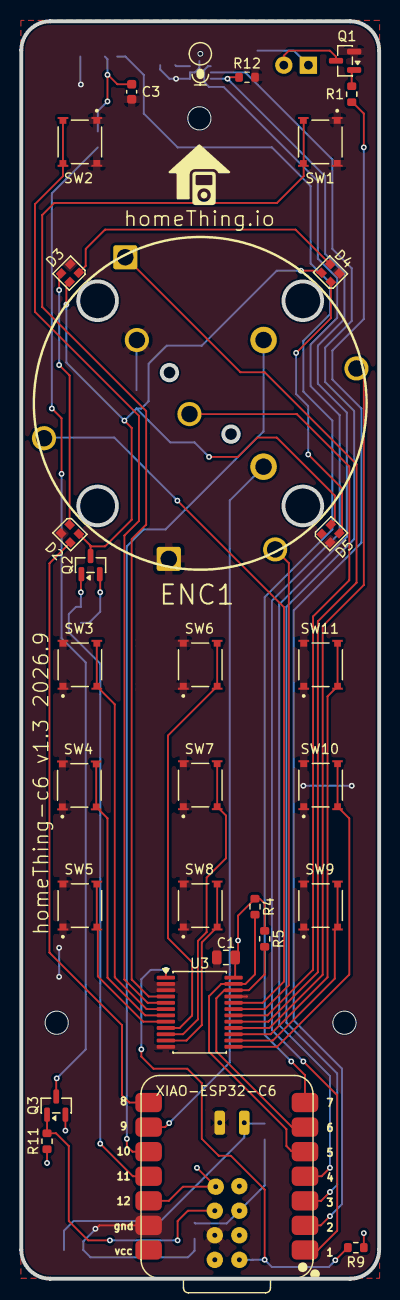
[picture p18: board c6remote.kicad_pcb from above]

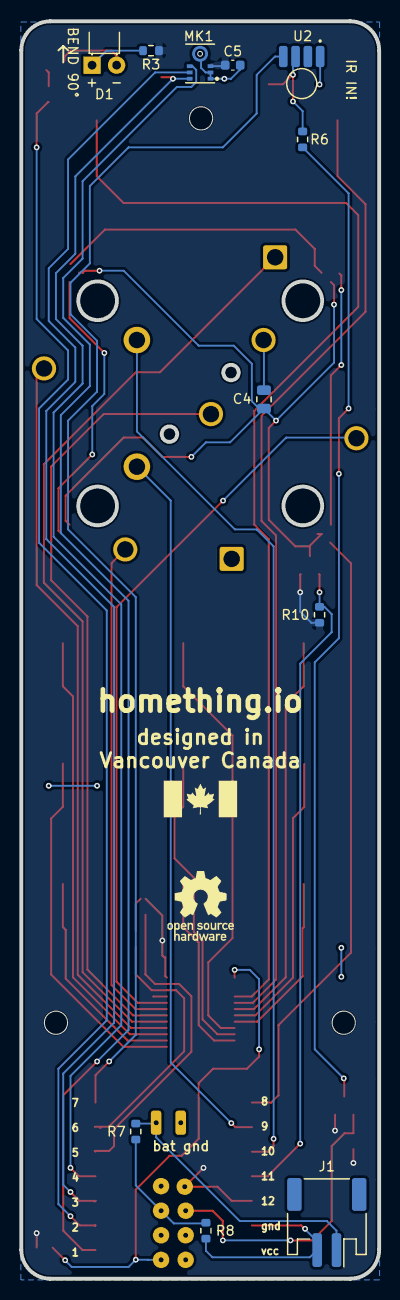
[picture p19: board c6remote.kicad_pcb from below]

Board: 2 copper layers, 37.0 x 130.0 mm, 43 parts (11 on the bottom side), 42 nets.

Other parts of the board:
H1, H2, H3: MountingHole_2.4mm_M2

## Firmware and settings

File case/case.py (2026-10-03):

"""Four-part case for the c6remote board: front shell, back shell, button pad,
IR window insert.

The back shell carries an AA lying along the board, which is what sets the case
thickness where the cell is. Elsewhere it tapers to what the board needs, so the
back is a contoured hump rather than a slab. The board hangs off the front plate,
on one boss per mounting hole dropping from the ceiling, taking M2 screws driven
from the back. The two shells meet in a lap joint around the whole perimeter, the back
closing over a skirt on the front, and are held by two detents at the IR end and
one screw at the other, driven horizontally through the back's end wall into a
block the front carries behind its skirt. Every mounting hole keeps its own short
screw, so the case takes four M2 x 6 and nothing longer. Hidden catches in both
long-side skirts hold the seams closed near the board midpoint.

The pad is two flat soft lobes with one raised feature per switch, one lobe per
island of keys, each padded off its own keys and so stopping short of the wheel
rather than being cut back from it. Neither reaches over the wheel or the status
LEDs: the light hits the translucent shell directly instead of being piped
through silicone. The moulded pad has a skirt level with the plungers, broken over
board parts. The plungers rest on the switches and hold each lobe against the
ceiling.

SW1 and SW2 raise a moulded keytop, as every key once did. The other nine raise a
stem instead, and a rigid translucent cap sits over each one. The caps are
separate parts carrying the legends, so changing what a key says is one small
reprint rather than a new pad. Each is captive: a flange at its base rides a
counterbore in the ceiling, so it drops in from inside and cannot fall out.

The IR window insert closes the receiver's rounded -Z aperture in the back
floor. Its pane follows the built back contour, presses into the aperture, and
lands flush outside; its open interior flange retains on a continuous shell
shoulder that also carries adhesive. It installs from inside the back shell
before the shells close. The emitter remains separate and unchanged, firing
along +Y through a bare bore drilled to its own lens.

    python case.py            write an STL for each part, shells, pad, window
                              and caps
    python case.py --show     open in ocp-vscode instead of exporting
    python case.py --draft    write the STLs only, for a quick preview

The geometry lives in model/, one module per feature. This file re-exports it
flat, so `case.X` still names everything it always did and check.py needs no
knowledge of where a given feature moved to.
"""

from model import *  # noqa: F401,F403
from model import main

if __name__ == "__main__":
    main()

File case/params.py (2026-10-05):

"""Tunable dimensions for the c6remote case. All lengths mm, all angles degrees.

Coordinate frame matches the KiCad STEP export: X is board X, Y is negated board Y,
Z is 0 at the board's bottom copper face and positive upward. Component positions
from c6remote-pos.csv drop straight in with no transform.

Front is the button face, +Z. Back is the battery face, -Z. They correspond to
the board's top and bottom sides respectively.
"""

from pathlib import Path

BOARD_THICKNESS = 1.6
"""Nominal. The exported STEP body measures 1.51 because KiCad omits copper."""

SWITCH_HEIGHT = 1.6
"""TL3315NF160Q actuator height above the board face, from the 160 in the part
number. Not measurable from the design files: the footprint's 3D model is a
0.55mm stub, and being VRML it is dropped from the STEP assembly entirely, so no
check catches this being wrong. Confirm against a real switch before committing
to a pad tool, because every plunger length follows from it.

The keycaps inherit the error 1:1 as protrusion error, and it shows more on a
rigid cap standing proud than it ever did on a soft keytop, so measure before
printing nine of them."""

SWITCH_TRAVEL = 0.25
"""How far a TL3315 actuator moves to make. Family typical, hand-entered from the
datasheet and unconfirmable from the design files, the same epistemic class as
SWITCH_HEIGHT. A press must move the pad web this far to make the switch. The
web flex gives this travel, and the switch is the bottom stop."""

# Shell
WALL = 3.0
"""Thicker than a plain shell needs, because the lap splits it: the back's lap,
a fit and the front's skirt all live inside this one thickness. The side catch
detents also need wall behind their roots. At 2.0 the lap is too thin for them.
It costs 2.0 on each of the case's outside dimensions."""
FLOOR = 2.4
"""Back shell floor, under the cavity and over the whole contoured form. No
fastener passes through it any more: the one closure screw enters the -Y end
wall horizontally, so this is sized as a printed floor over a hand-held
volume rather than against a counterbore sunk into it."""
BOARD_FIT = 0.5
"""Gap between the board edge and the inner wall. Board screws locate the board.
The uniform offset changes case length and width by twice the clearance change."""

# Board deflection stops on the inside of the back shell side walls.
SUPPORT_BEARING = 3.0
SUPPORT_GAP = 0.25
SUPPORT_SKIRT_FIT = 0.4
"""Vertical clearance between the top of each board support ledge and the
front skirt relief above it. The front skirt must never land on a ledge,
because the seam shoulder is the only vertical stop. This value is larger than
SUPPORT_GAP. As a result, when a button press pushes the board down, the board
touches the ledges before the skirt does."""
SUPPORT_CLEARANCE = 0.4
SUPPORT_MIN_RUN = 8.0
SUPPORT_SOUTH_RUNS = False
"""Include the south-most board support run on each side when true. The board
is carried by the front plate's bosses, and the runs nearest the grip end back
onto the cell bay rather than onto anything that deflects, so this stays
false."""
SUPPORT_UNDER_ANGLE = 60.0
SUPPORT_INNER_R = 0.6
"""Radius on the inboard support edge. It removes the sharp printed tip and
shortens the flat bearing surface by the fillet tangent."""
SUPPORT_MIN_BEARING = 1.5
"""Minimum flat board bearing that must remain after the inboard fillet."""
SUPPORT_SHELL_SKIN = 0.2
"""Keep this exterior shell thickness outside the board support ledges."""

# Vertical clearance measured from the board faces, not from z=0.
FRONT_KEEPOUT = 4.5
"""Clears the USB-C shell at 4.21 above the board face, the tallest thing under
the ceiling anywhere near it. ENC1 reaches 5.75 but passes through the wheel
opening rather than under the ceiling, so it does not set this.

Local to the USB connector's own footprint now, not the whole ceiling: the
keypad has nothing tall over it, so its own region drops to KEYPAD_KEEPOUT
instead, and the USB region keeps a locally deeper cavity, reaching this
full depth, inside an outer face that is flat everywhere. Case.py's
CAVITY_FRONT_USB is that local boundary; CAVITY_FRONT is the keypad one."""

KEYPAD_PLUNGER_STUB = 0.3
"""How far a plunger stands proud of the switch top before the pad's web
begins, over the keypad: KEYPAD_KEEPOUT in case.py is SWITCH_HEIGHT plus
this, so the web's underside lands just above the switches instead of
FRONT_KEEPOUT's old, USB-sized margin, which left 1.7 of unsupported
plunger spanning dead air between the two.

Kept a real, nonzero stub rather than shrinking it to nothing: a press
still has to concentrate through a short, stiff post onto the actuator,
not through the flat web sagging down to meet it. 0.3 is toward the
shallow end of what still reads as a real stub; check.py's
plunger_stub_contact confirms the built pad actually reaches the switch
by it, not merely by the formula."""
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

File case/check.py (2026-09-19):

"""Verify the case against the board. Forty-five passes, each catching what
the others cannot.

The passes live in checks/, one module per feature, mirroring model/. Each
module's own docstring says what its passes catch and why nothing else covers
it. checks/cli.py holds main(), which is the report's order and the argument
handling.

    python check.py                 every pass
    python check.py --only ir       one feature's passes, building only the
                                    solids those passes probe

Every run also writes export/c6remote-checks.json, the same report in machine
form, carrying each failure's own point or box in the case frame wherever the
pass recorded one. That is what the c6remote-explode viewer draws the failures
from.
"""

from checks.cli import main

if __name__ == "__main__":
    main()

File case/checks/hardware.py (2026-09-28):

"""Cell clearance: the cell envelope against every modelled solid, every screw
boss, and both shells.

Feature clashes: bosses, ribs and the cell against every part's courtyard. The
only pass that sees the eleven switches, D2-D5 and J1, none of which reach the
STEP assembly. 2D, so it answers where a part sits, never how tall it is.

End screw: the one fastener that closes the two shells, read off both built
shells rather than off the stack that sized it.

End screw side tie: the web's tie from that block into the +X side skirt, at
web height only, on both built fronts.

End screw grip corner: the block and its root fillet stop at the +X grip
corner tangent, and the back's wall chamfer follows the arc past it, so nothing
stands in the round and the lap keeps its wall.
"""

import functools

from build123d import (
    Box,
    BuildLine,
    BuildSketch,
    Compound,
    Cylinder,
    GeomType,
    Plane,
    Polyline,
    Pos,
    Rot,
    extrude,
    make_face,
)

import board
import case
import params

from .common import TOLERANCE, Problem, _Crop, _fill_fraction, _volume


def cell_clearance():
    """The cell against everything on the board, and against the shells."""
    cell = case.cell_envelope()
    hits = []
    for solid in board.assembly_solids():
        volume = _volume(cell.intersect(solid))
        if volume > TOLERANCE:
            box = solid.bounding_box()
            hits.append((f"solid at ({box.center().X:.1f},{box.center().Y:.1f})", volume))
    # Courtyards carry no height, so only use them for parts the STEP is missing.
    for ref, (x0, y0, x1, y1, side) in board.courtyards().items():
        if side != "bottom":
            continue
        try:
            board.part_envelope(ref)
            continue
        except ValueError:
            pass
        footprint = Pos(
            (x0 + x1) / 2, (y0 + y1) / 2, -params.UNMODELLED_DEPTH / 2
        ) * Box(x1 - x0, y1 - y0, params.UNMODELLED_DEPTH)
        volume = _volume(cell.intersect(footprint))
        if volume > TOLERANCE:
            hits.append((f"{ref}, assumed {params.UNMODELLED_DEPTH} deep", volume))
    volume = _volume(case.back_shell().intersect(cell))
    if volume > TOLERANCE:
        hits.append(("the back shell", volume))
    return hits


@functools.cache
def _part_z(ref, side):
    """(min_z, max_z) a part occupies. Measured where there is a 3D model, and
    assumed to fill the cavity on its side of the board where there is not.

    Cached: a bounding box over every assembly solid is not cheap, and this is
    asked the same question once per case feature.
    """
    try:
        box = board.part_envelope(ref)
        return box.min.Z, box.max.Z
    except (ValueError, KeyError):
        if side == "bottom":
            return -params.UNMODELLED_DEPTH, 0.0
        return params.BOARD_THICKNESS, case.CAVITY_FRONT


def feature_clashes():
    """Case features that sit inside the cavity, against every part's courtyard.

    This is the only pass that sees the switches, D2-D5 and J1, none of which
    reach the STEP assembly. Courtyards carry no height, so a part's z span comes
    from its model where it has one, and is assumed to fill its side of the cavity
    where it does not. The end screw block is read on its built solid.
    """
    court = board.courtyards()
    features = []
    for x, y, _ in board.mounting_holes():
        r = params.BOSS_OD / 2
        # The boss hangs off the ceiling above the board, the screw head sits
        # under it. Comparing either against the wrong side of the board means
        # comparing it against nothing it can reach. SHELL_FRONT, not
        # CAVITY_FRONT: the boss now carries its own material past the
        # keypad region's own (thinner) ceiling, all the way to the one
        # flat face, so its real height would otherwise be understated here.
        features.append(
            ("boss", x - r, y - r, x + r, y + r, case.BOARD_TOP, case.SHELL_FRONT)
        )
        root_r = r + params.STANDOFF_CHAMFER
        features.append(
            (
                "boss root",
                x - root_r,
                y - root_r,
                x + root_r,
                y + root_r,
                case.CAVITY_FRONT - params.STANDOFF_CHAMFER,
                case.CAVITY_FRONT,
            )
        )
        h = params.SCREW_HEAD_D / 2
        features.append(
            ("screw head", x - h, y - h, x + h, y + h, -params.SCREW_HEAD_H, 0.0)
        )
    # The V2 retention post, on both its own diameter and its root chamfer. This
    # is the pass that sees the eleven
    # switches and D2-D5, so it is what says the post clears a part with no model.
    lx, ly = board.legacy_retention_point()
    floor = case.legacy_retention_floors()[1]
    r = params.LEGACY_RETENTION_OD / 2
    features.append(
        (
            "legacy post",
            lx - r,
            ly - r,
            lx + r,
            ly + r,
            floor,
            case.SUPPORT_TOP,
        )
    )
    root_r = r + params.STANDOFF_CHAMFER
    features.append(
        (
            "legacy post root",
            lx - root_r,
            ly - root_r,
            lx + root_r,
            ly + root_r,
            floor,
            floor + params.STANDOFF_CHAMFER,
        )
    )

    mx, my = case.mic_port()
    r = params.MIC_DUCT_OD / 2
    features.append(
        ("mic duct", mx - r, my - r, mx + r, my + r, case.BOARD_TOP, case.SHELL_FRONT)
    )
    root_r = r + params.STANDOFF_CHAMFER
    features.append(
        (
            "mic duct root",
            mx - root_r,
            my - root_r,
            mx + root_r,
            my + root_r,
            case.CAVITY_FRONT - params.STANDOFF_CHAMFER,
            case.CAVITY_FRONT,
        )
    )

    clashes = []
    for name, fx0, fy0, fx1, fy1, fz0, fz1 in features:
        for ref, (cx0, cy0, cx1, cy1, cside) in court.items():
            cz0, cz1 = _part_z(ref, cside)
            overlap = [
                min(fx1, cx1) - max(fx0, cx0),
                min(fy1, cy1) - max(fy0, cy0),
                min(fz1, cz1) - max(fz0, cz0),
            ]
            if min(overlap) > 0:
                clashes.append((name, ref, min(overlap)))
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

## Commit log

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2026-05-12 feat(kicad): add render script and mic hole
    Increase M1 acoustic hole to 0.75 mm and pull back nearby GND copper to satisfy hole clearance. Add reusable 2D render helper and document top/bottom exports.
    [c6remote.kicad_pcb]
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2026-05-20 fix(3d): correct XIAO ESP32-C6 model rotation and offset
    Rotation -90 0 -90, z offset 0.71 — module flush above PCB with
    USB-C oriented correctly. Hide SAMD21 default model in PCB instance.
    Regenerate readme render assets.
    [c6remote.kicad_pcb]
2026-05-20 fix(sch): add no-connect flags and PWR_FLAGs to reduce ERC violations
    No-connect: U3/~INT, U1/GPIO18-MOSI, D2/DOUT
    PWR_FLAG: MK1 +3.3V rail, D2 VDD (VCC), D2 VSS (GND)
    ERC errors: 7 → 2 (remaining 2 are ENC1 COM pin-type issue)
    [c6remote.kicad_sch]
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2026-05-21 fix(sch): retype ano rotary COM1/COM2 pins as passive to clear ERC errors
    [c6remote.kicad_sch]
2026-05-21 fix(sch): add Sim.Device/Sim.Pins to MMBT2222A cached symbol to resolve ERC library mismatch
    [c6remote.kicad_sch]
2026-05-21 fix(sch): resolve XIAO ERC library warning
    Register Seeed_Studio_XIAO_Series sym lib and sync embedded U1
    symbol from upstream OPL_Kicad_Library. Document symbol library
    sources in README.
    [c6remote.kicad_sch]
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2026-05-28 fix(schematic): add R3 22Ω 0603 IR LED current-limit between +3.3V and D1 anode (was missing — only Q1 base R) and mark hardware-todo item done
    [c6remote.kicad_sch]
2026-05-28 fix(pcb): place R3 22Ω 0603 at (55, 33.258) F.Cu, route to D1 anode and via to +3.3V pour on B.Cu, remove stitching GND via conflicting with R3.1 (DRC: 48 violations, was 50)
    [c6remote.kicad_pcb]
2026-05-29 fix(pcb): relocate R3 to (58.175, 33.258) on B.Cu (manual placement refinement; DRC still 48 violations, no R3 errors)
    [c6remote.kicad_pcb]
2026-05-29 fix(net): rename BAT local labels to global so net emits as 'BAT' not '/BAT'; patch stale PCB pad nets U1.32 BAT_32 and MK1.5 VDD_5 from PWR_FLAG to BAT/+3.3V; refill zones (DRC: 0 errors, 42 warning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
    [c6remote.kicad_pcb, c6remote.kicad_sch]
2026-05-29 feat(schematic): add I2C pull-ups R4 (4.7k SDA->+3.3V) and R5 (4.7k SCL->+3.3V) west of XIAO label bundle with shared #PWR033 +3.3V symbol; ERC clean (0 errors, 12 baseline warnings); PCB placement p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
    [c6remote.kicad_sch]
2026-05-29 fix(pcb): place I2C pull-ups R4 SDA (60,121) and R5 SCL (61.325,125) on F.Cu near U1/U3; restore R3 footprint path UUID linking to schematic symbol (was orphaned, caused duplicate-R3 on sync); DRC: 0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
    [c6remote.kicad_pcb]
2026-05-29 fix(power): move SK6812 D2 supply from VCC (VBUS) to +3.3V so LED works on battery; rewires D2/4 + C2/1; VCC label now only U1/14 (orphan single-node /VCC net, rename to VBUS later)
    [c6remote.kicad_pcb, c6remote.kicad_sch]
2026-05-29 feat(schematic): add TSOP U2 supply filter R6 100Ω inline + C3 100nF bypass; relocate PWR_FLAG02 onto filtered Vs net (resistor breaks power chain for ERC); convert VCC local label to global so net s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
    [c6remote.kicad_pcb, c6remote.kicad_sch]
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2026-06-16 fix(bom): swap PCBWay out-of-stock parts - D1 IR204-A->Inolux INL-3AHIR30 (3mm 940nm 100mA radial, matches ~80mA drive via R3/+3.3V, keeps 90deg lead-form at assembly), U2 TSOP4536->Vishay TSOP4136 (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
    [c6remote-bom.csv, c6remote.kicad_sch]
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2026-07-09 fix(pcb): renumber U1 XIAO-ESP32-C6 footprint bottom pads 15-22->24-31 to match schematic symbol pins (GPIO5/GPIO7/CHIP_EN/GND/GPIO4/GPIO6/GPIO9/3V3), fixing orphaned bottom row (symbol used 24-31, f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
    [c6remote.kicad_pcb]
2026-07-09 feat(batt): add battery voltage-sense divider R7/R8 (100k/100k 0603) BAT->bat_sense->GND with midpoint to U1 GPIO4/pin28 ADC (halves 4.2V LiPo to ~2.1V for 3.3V ADC, ~21uA drain), routed on PCB w/ DR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
    [c6remote-B_Cu.gbr, c6remote-B_Mask.gbr, c6remote-B_Paste.gbr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]
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2026-07-13 feat(wake): add deep-sleep button wake via U3 PCF8575 ~INT -> new exp_int net to U1 GPIO5/pad24 (LP GPIO, ext1 wake) with R9 100k 0603 pullup to +3.3V next to R7/R8; schematic label + stale no-connec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
    [c6remote-B_Cu.gbr, c6remote-B_Mask.gbr, c6remote-B_Paste.gbr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]
2026-07-13 fix(J1): replace battery connector footprint with real SMD JST S2B-PH-SM4-TB(LF)(SN) (1x02-1MP horizontal) — prior embedded footprint was THT S2B-PH-K name with hand-converted SMD pads and no drills 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
    [c6remote-B_Cu.gbr, c6remote-B_Mask.gbr, c6remote-B_Paste.gbr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]
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2026-07-14 fab(ENC1): mark ano encoder populated (dnp no) + in_pos_files/attr exclude_from_pos_files so PCBWay skips P&P assembly but part shows in BOM/board; add Adafruit MPN/SKU 5001 datasheet+description sou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
    [c6remote.kicad_pcb, c6remote.kicad_sch]
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2026-07-15 chore(sch): reposition status-LED cluster on schematic sheet - shift D2/C2/R2/R7/R8/PWR_FLAG/GND/+3.3V and led_1 label ~3.8mm and rework SK6812 wiring/junctions; rerender schematic.svg (layout-only, 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
    [c6remote.kicad_sch]
2026-07-16 docs(D1): show 90° lead bend on IR emitter in 3D render - swap D1 model to LED_D3.0mm_Horizontal_O1.27mm_Z2.0mm_IRBlack (right-angle: leads rise from pads, body lies horizontal firing off top-edge no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
    [c6remote.kicad_pcb]
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2026-07-17 docs(bom): add Manufacturer/MPN + Digi-Key/Mouser/Adafruit part links, drop redundant SKU, set ICS-43434 and XIAO ESP32-C6 datasheets, rewrite all descriptions as Type: detail (grouped rows kept iden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
    [c6remote-B_Cu.gbr, c6remote-B_Mask.gbr, c6remote-B_Paste.gbr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]
2026-07-17 docs(3d): replace SW1-11 3D model with datasheet-accurate TL3315NF160Q.wrl (4.5x4.5x0.55 gold snap dome, PCBWay confirmed exact part per BOM) - drop wrong 5mm PTS647 step, regen board renders, close 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
    [SW_SPST_PTS647Sx50_black.step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]
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2026-07-17 pcb+sch(gnd13): connect U1 pad 13 and TP_GND to F.Cu zone via pad connection fix and refill (45deg thermal spokes were choked by pad 12/14 clearance on 2.54 pitch), convert 4 local GND labels to glob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
    [c6remote-B_Cu.gbr, c6remote-B_Mask.gbr, c6remote-B_Paste.gbr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]
2026-07-17 fix(erc): convert 10 remaining same-name local labels (ws sck scl sda sd ano_enc1 ano_enc2 IR REC IR EMIT led_1) to global_label shape input, clearing all same_local_global_label warnings (ERC 12->2,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
    [c6remote-B_Cu.gbr, c6remote-B_Mask.gbr, c6remote-B_Paste.gbr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]
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2026-07-17 fix(erc): add TP_VCC test-point symbol on VCC net (U1 VBUS now has 2nd node) clearing isolated_pin_label, and repoint fp-lib-table Local lib from stale /dev/c6homething path to ${KIPRJMOD}/Local.pret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
    [c6remote-B_Cu.gbr, c6remote-B_Mask.gbr, c6remote-B_Paste.gbr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]
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2026-07-22 fix(anorotary): swap ENC1 pad 6/8 to datasheet functions (COM_A/S4_UP) fixing dead center press + rotation - symbol pins renamed COM_A/COM_B/S1-S5/ENCA/ENCB with pin numbers 6/8 swapped, library+embe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
    [c6remote-B_Cu.gbr, c6remote-B_Mask.gbr, c6remote-B_Paste.gbr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]
2026-07-22 feat(esphome): add c6remote.yaml bring-up config + secrets.example.yaml, document bring-up flow and SW1-11 TL3315 short in README/ROADMAP - all board inputs exposed with guarded LED/IR/mic/battery-AD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
    [c6remote.yaml]
2026-07-22 fix(sch): clear SW1-11 TL3315 terminal short by replacing generic 2-pin Switch:SW_Push with 4-pin Local:SW_TL3315NF160Q (new Local.kicad_sym + sym-lib-table entry); pins 1,2 stacked on GND node, 3,4 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
    [c6remote-B_Cu.gbr, c6remote-B_Mask.gbr, c6remote-B_Paste.gbr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]
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2026-07-22 fix(pcb): add TP_VCC1 test point footprint on VCC rail matching schematic symbol - single THT probe pad at (45.2, 155.25), pad net VCC, resolves duplicate-refdes/parity so board and sch agree 1:1 on 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
    [c6remote-B_Cu.gbr, c6remote-B_Mask.gbr, c6remote-B_Paste.gbr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]
2026-07-22 fix(pcb): rotate + rewire SW1-11 to datasheet terminal mapping (pads 1,2 GND / 3,4 sw*), clearing the board-vs-schematic divergence - all 11 SW footprints verified pads 1,2 on GND and 3,4 on sw1..sw1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
    [c6remote-B_Cu.gbr, c6remote-B_Mask.gbr, c6remote-B_Paste.gbr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]
2026-07-22 fix(pcb): move LED up and battery left to clear room for through-hole center pins, delete leftover led_1 track stub - repositioned D2 (LED) and battery footprint, removed dangling 1.5mm led_1 stub at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
    [c6remote-B_Cu.gbr, c6remote-B_Mask.gbr, c6remote-B_Paste.gbr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]
2026-07-22 fix(pcb): move IR receiver U2 to back side (B.Cu) for tall-part clearance, clean up silk and orphaned +3.3V via - relocated U2 to bottom, deleted dangling +3.3V via at (51,33), reduced silk overlaps;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
    [c6remote-B_Cu.gbr, c6remote-B_Mask.gbr, c6remote-B_Paste.gbr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]
2026-07-22 fix(pcb): round 4 board corners with 3mm fillet arcs on Edge.Cuts, refill GND/+3.3V zones - trimmed perimeter edges and added quarter-circle arcs at all outer corners (2 bottom, 2 top between connect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
    [c6remote-B_Cu.gbr, c6remote-B_Mask.gbr, c6remote-B_Paste.gbr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]
2026-07-22 chore(pcb): route cleanup on sd/IR EMIT nets (reflowed B.Cu segments, refreshed zones) - reorganized track paths and refilled copper; ERC 0, DRC 0 errors 0 unconnected, 41 silk/lib warnings unchanged
    [c6remote-B_Cu.gbr, c6remote-B_Mask.gbr, c6remote-B_Paste.gbr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]
2026-07-22 fix(pcb): clean up silkscreen and reposition labels - tidied F/B silk text and refdes placement; DRC 0 errors 0 unconnected, 41 silk/lib warnings unchanged
    [c6remote-B_Cu.gbr, c6remote-B_Mask.gbr, c6remote-B_Paste.gbr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]
2026-07-22 fix(pcb): replace 4 square encoder cutouts with Adafruit ANO circles on Edge.Cuts - removed 24 diamond gr_lines, added 6 gr_circle (4x Dia4mm mounting + 2x Dia1.6mm anti-rotation) at 45deg-rotated po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
    [c6remote-B_Cu.gbr, c6remote-B_Mask.gbr, c6remote-B_Paste.gbr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]
2026-07-25 fix(pcb): reroute 11 nets clear of ANO cutouts and rounded corners, restore 0.5mm edge clearance rule - replaced 63 segments with 81 (IR REC/IR EMIT/sck/sd/ws/sda/scl/sw1/sw2/ano_enc1/ano_sw5), refil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
    [c6remote-B_Cu.gbr, c6remote-B_Mask.gbr, c6remote-B_Paste.gbr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]
2026-07-26 feat(led): 4-LED WS2812B-2020 status chain replacing the single SK6812MINI, LED block cut from 3 parts to 2 per LED - D2 swapped to WS2812B-2020 (2020 PLCC4, 4.0mm2 vs 12.25mm2, Worldsemi reel MPN + 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
    [c6remote-B_Cu.gbr, c6remote-B_Mask.gbr, c6remote-B_Paste.gbr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]
2026-07-26 fix(pcb): reconnect isolated 522mm2 GND pour region, copy ANO wheel outline to silkscreen - F.Cu GND pour fills as 3 regions and one of them (522mm2) carried only U3 pad 12 of its 4 GND pads, leaving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
    [c6remote-B_Cu.gbr, c6remote-B_Mask.gbr, c6remote-B_Paste.gbr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]
2026-07-26 refactor(led): delete C2, the last LED decoupling cap, status LED chain is now 4 parts with zero passives - measured the finished layout instead of resting on the datasheet note, and both the one-cap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
    [c6remote-B_Cu.gbr, c6remote-B_Mask.gbr, c6remote-B_Paste.gbr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]
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2026-07-27 feat(led): swap D2-D5 to XINGLIGHT XL-2020RGBC-WS2812B on a datasheet-correct land pattern, LCSC C5349955 with 183k stock and cheaper than the discontinued C965555 it replaces - rated VDD 3.5-5.5V no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
    [c6remote-B_Cu.gbr, c6remote-B_Mask.gbr, c6remote-B_Paste.gbr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]
2026-07-27 fix(pcb): place D2-D5 on a square around the ANO wheel and reroute the stranded chain - all four LEDs now sit at radius 19.046273mm from the wheel centre (53.337455, 67.714045) at exactly 45/135/225/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
    [c6remote-B_Cu.gbr, c6remote-B_Mask.gbr, c6remote-B_Paste.gbr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]
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2026-07-27 fix(pcb): reposition Q1 and R1 in the IR emitter block, Q1 from (68.326, 32.004) rot 180 to (69.05, 34.5625) rot 90 and R1 y 36.576 to 38.425, with SW10 field rotations normalised to 90 and footprint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
    [c6remote-B_Cu.gbr, c6remote-B_Mask.gbr, c6remote-B_Paste.gbr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]
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2026-07-27 fix(pcb): capitalise the back-silk made-in text to Vancouver and Canada, and reroute ano_enc1 off the old straight B.Cu run, dropping the 55.75mm segment from (58.166, 79.834) to (58.166, 135.584) in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
    [c6remote-B_Cu.gbr, c6remote-B_Mask.gbr, c6remote-B_Paste.gbr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]
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2026-07-27 fix(mic): renumber the ICS-43434 symbol pins to the datasheet so MK1 is wired correctly, the embedded INMP441_Microphone_I2S symbol and its project-local inmp441_microphone_i2s.kicad_sym source both 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
    [c6remote-B_Cu.gbr, c6remote-B_Mask.gbr, c6remote-B_Paste.gbr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]
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2026-07-28 fix(firmware): apply the measured ANO direction mapping to c6remote.yaml, the production firmware was the last place still carrying the retracted 90 CW rotation theory, naming PCF8575 bit 11 Encoder 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
    [c6remote.yaml]
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2026-07-28 feat(firmware): declare the PCF8575 nINT on GPIO5 in c6remote.yaml, the production config set up the expander and all sixteen of its inputs but never referenced the interrupt line the board provides,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
    [c6remote.yaml]
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2026-07-28 fix(firmware): swap the I2S LRCLK and data pins to match the board, sd and ws changed places at the XIAO in b2d85c0 when MK1 was rerouted so GPIO0 now carries ws to MK1 pad 1 and GPIO21 carries sd to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
    [c6remote-test-common.yaml, c6remote.yaml]
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2026-07-30 feat(led): gate the D2-D5 rail with a high-side P-FET so the four XL-2020RGBC-WS2812B stop burning ~2.4mA quiescent while dark, which was the binding constraint on battery life since a WS2812-class c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
    [c6remote-B_Cu.gbr, c6remote-B_Mask.gbr, c6remote-B_Paste.gbr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]
2026-07-30 feat(firmware): follow the new led_vdd rail with a led_rail switch on GPIO18 so the gated LEDs actually save current, adding an inverted GPIO18 switch (restore_mode ALWAYS_OFF, so setup writes the sa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
    [c6remote-test-common.yaml, c6remote.yaml]
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2026-07-30 fix(pcb): rotate D5 from 225 to 45 so the four LED ring is actually four-fold symmetric, which it was not: D2, D3 and D4 all sat at consecutive 90 degree steps with VDD facing the wheel centre while 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
    [c6remote-B_Cu.gbr, c6remote-B_Mask.gbr, c6remote-B_Paste.gbr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]
2026-07-30 fix(pcb): give D1 a forked horizontal footprint with + and - silk glyphs, since the part is a 3mm IR LED whose leads bend 90 degrees to aim out the top board edge but the board drew it standing uprig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
    [c6remote-B_Cu.gbr, c6remote-B_Mask.gbr, c6remote-B_Paste.gbr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]
2026-07-30 feat(pcb): add three 2.9mm mounting holes for loose M2.5 metal screws into a case, since the board had no fixing points at all and only the four ANO posts and two alignment pegs existed as holes; two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
    [c6remote-B_Cu.gbr, c6remote-B_Mask.gbr, c6remote-B_Paste.gbr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]
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2026-07-30 fix(firmware): interlock the LED Rail switch so it cannot leave GPIO17 driving a dead rail, and record the already-shipped GPIO17 safing in ROADMAP; the rail sequencing was in fact already implemente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
    [c6remote-test-common.yaml, c6remote.yaml]
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2026-07-31 fix(pcb): clear all four vias that sat inside SMD pads, which PCBWay flagged on 2026-07-30 as a solder paste leakage and shorting risk on the gerbers already sent, offering resin plug plus cap plus p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
    [c6remote-B_Cu.gbr, c6remote-B_Mask.gbr, c6remote-B_Paste.gbr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]
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2026-07-31 chore(hooks): block commits carrying eeschema's kicad_pro clobber, adding scripts/check-kicad-pro-drift.py and calling it from scripts/hooks/pre-commit before the regen steps, since the root cause fo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
    [check-kicad-pro-drift.py]
2026-07-31 fix(hooks): widen the kicad_pro drift guard to whole rule and severity blocks, because the hand-picked field list shipped one commit earlier missed the very next clobber; closing eeschema rewrote erc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
    [check-kicad-pro-drift.py]
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2026-07-31 fix(pcb): resync the 13 stale TP_* footprint instances to their library so DRC drops from 15 warnings to 2, which is silk and metadata only with no copper touched; the Local.pretty TestPoint_THTPad_1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
    [c6remote-B_Cu.gbr, c6remote-B_Mask.gbr, c6remote-B_Paste.gbr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]
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2026-08-01 fix(pcb): rework the board for PCBWay's second via-in-pad report, delete all 14 TP_* test points, retire the VCC rail, and bump the front silk to 2026.8.0, taking DRC to 1 warning and schematic parit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
    [c6remote-B_Cu.gbr, c6remote-B_Mask.gbr, c6remote-B_Paste.gbr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]
2026-08-03 fix(pcb): reword back silk origin line to designed in Vancouver Canada and bump front silk revision to 2026.8.1, since 2026.8.0 is already released so this artwork would otherwise ship under a versio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
    [c6remote-B_Cu.gbr, c6remote-B_Mask.gbr, c6remote-B_Paste.gbr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]
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2026-08-12 feat(pcb): move the bottom M2.5 mounting hole off the centreline at 53.337,112.95 down to 38.25,132 and add a second at 68.5,132, so a case screws into four points instead of three and the bottom pai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
    [c6remote-B_Cu.gbr, c6remote-B_Mask.gbr, c6remote-B_Paste.gbr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]
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2026-08-18 feat(pcb): replace the three screw holes' Edge.Cuts circles with H1-H3 on a new Library:MountingHole_2.4mm_M2 footprint and drop the fastener from M2.5 to M2, so they are drilled as T6C2.400 NonPlate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
    [c6remote-B_Cu.gbr, c6remote-B_Mask.gbr, c6remote-B_Paste.gbr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]
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2026-08-18 feat(pcb): swap U2 from the through-hole TSOP4136 to the SMD TSOP6136 on a new Library:Vishay_PANHEAD-4Pin_SideView footprint at 42.845,31.8575 on B.Cu, which keeps the AGC1 setting so the set of rem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
    [TSOP6136.step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]
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2026-08-18 fix(bom): disambiguate ENC1's MPN from the bare 5001 to Adafruit 5001, since PCBWay's T-F44W557020A quote matched the number against Keystone Electronics 5001 and bought PC test point turrets at $0.4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
    [c6remote-B_Cu.gbr, c6remote-B_Mask.gbr, c6remote-B_Paste.gbr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]
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2026-08-21 feat(pcb): reorient U2 to receive perpendicular to the board through the bottom face, correcting the record that TT and TR are mere tape attitudes: TSOP6136TT is the top-view lead form and TSOP6136TR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
    [TSOP6136TT.step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]
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2026-08-30 feat(firmware): learn and replay IR codes on SW3-SW11 with a receiver mode that stays open until SW2, fix the RMT split that left the LED strip on 96 symbols and the IR transmitter silently failed at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
    [c6remote.yaml, ir_learning.h]
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2026-08-30 fix(pcb): align the design rules and silkscreen artwork with the JLCPCB validator, tightening min_via_annular_width to 0.125mm, min_hole_to_hole to 0.5mm, min_text_height to 1.0mm and min_text_thickn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
    [c6remote-B_Cu.gbr, c6remote-B_Mask.gbr, c6remote-B_Paste.gbr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]
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2026-08-30 fix(firmware): halve the status light brightness to 50 percent so the LED strip is comfortable at bench distance
    [c6remote.yaml]
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2026-08-31 chore(firmware): drop the Start Microphone Test and Send Short IR Test Burst template buttons, since the microphone now runs under the voice assistant and the fixed 36kHz two-pulse burst has served i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
    [c6remote.yaml]
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2026-08-31 ci: run ERC and DRC on every push and pull request in a kicad/kicad:10.0 container via scripts/check-design.py, which fails on anything but the inherited U1 lib_footprint_mismatch, so the AGENTS.md b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
    [check-design.py]
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2026-08-31 fix(pcb): drop the DRC baseline from six allowed warnings to one by setting min_text_height to 0.8mm for the XIAO pin labels and moving the two brand texts to the Iosevka Bold family, and reposition 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
    [c6remote-B_Cu.gbr, c6remote-B_Mask.gbr, c6remote-B_Paste.gbr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]
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2026-08-31 feat(firmware): name each IR code and move the /buttons copy and paste box to the Flipper .ir signal syntax, so a Samsung32 code reads as an address and a command byte, a Flipper-IRDB paste lands unc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
    [ir_learning.h, test_button_config.py]
2026-08-31 fix(firmware): give the Zigbee manager sole ownership of the training timeout so a success that lands after the old duplicate 30 s timer no longer flashes red and gets discarded, keep the cycle at th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
    [c6remote.yaml, ir_learning.h, test_button_config.py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]
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2026-08-31 feat(firmware): let the /buttons page assign a Zigbee toggle target directly, with a new GET /buttons/api/zigbee_targets reporting the cached Zigbee2MQTT groups and devices behind a ready flag, a set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
    [test_button_config.py, zigbee_learning.h]
2026-08-31 fix(firmware): stop subscribing to zigbee2mqtt/bridge/devices because ESPHome buffers the whole retained device inventory into a std::string and the C6 aborts the loop task with bad_alloc every 16 s,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
    [test_button_config.py, zigbee_learning.h]
2026-08-31 fix(firmware): set wifi power_save_mode to light because the Zigbee radio shares the C6 antenna and coexistence without modem power save makes the STA miss beacons, flapping the association every few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
    [c6remote.yaml, test_c6remote_config.py]
2026-08-31 refactor(firmware): drop the MQTT client so a Zigbee button works offline, moving target discovery to the /buttons browser over the Zigbee2MQTT frontend websocket, which reads bridge/groups and bridg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
    [c6remote.yaml, ir_learning.h, test_button_config.py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]
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2026-09-01 feat(firmware): replace the /buttons action buttons with one Action selector holding IR code, Zigbee group, voice assistant and clear, opening on the action the slot already holds and showing one pan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
    [test_button_config.py]
2026-09-01 feat(firmware): give the Zigbee assignment record a target kind so one slot can hold an IEEE address and an endpoint beside a group id, and migrate a version 3 blob in place rather than clearing all 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
    [test_c6remote_config.py, zigbee_learning.h]
2026-09-01 feat(firmware): let a button unicast to one Zigbee device by IEEE address and endpoint, resolving the short address with NWK_addr_req and resending once when the APS confirm fails, so the /buttons pa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
    [c6remote.yaml, test_button_config.py, test_c6remote_config.py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]
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2026-09-01 feat(firmware): replace the three Zigbee assign buttons with a target kind selector, a labelled field for each kind and one Assign button, so the panel shows one target at a time and a typed IEEE add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
    [test_button_config.py]
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2026-09-04 fix(buttons): disable Copy and Download JSON while the config box is empty so neither control offers an export the page cannot make
    [test_button_config.py]
2026-09-04 feat(buttons): give the Zigbee and the Bluetooth radio a switch on /buttons that disables every assignment using it, mark the Zigbee component failed at boot when the stored flag is off because the E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
    [c6remote.yaml, preview-buttons-page.py, test_button_config.py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]
2026-09-08 feat(hardware): swap MK1 from the ICS-43434 to the PUI Audio DMM-4026-B-I2S-R and fit the C5 decoupling capacitor and R12 pull-down on sd that the old part always needed, because three of five rev-B 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
    [DMM-4026-B-I2S-R.STEP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]
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2026-09-22 fix(case): close the gap the IR-end skirt lead-in left at the support cut face
    [shells.py]
2026-09-22 fix(case): stand the end screw block off the back wall so it stops bowing the case
    [cli.py, hardware.py, params.py]
2026-09-22 fix(case): report a pilot drilled level with its block back instead of crashing the check
    [hardware.py]
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2026-09-27 fix(case): lift front skirt relief above support ledges, deepen and preload side catches
    [cli.py, features.py, params.py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]
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2026-09-27 fix(case): drop the IR-end deep skirt and its lap relief so the back lap keeps 1.0 of wall, raise the end catches into the plain skirt with detents 1.1 proud, and check the lap wall on the built back
    [cli.py, features.py, params.py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]
2026-09-27 feat(case): add the FDM V2 top pad, the SW1/SW2 lobe keeping its V3 plungers with a nib under each V2 switch at the post-clamped board height, read from a frozen V2 pos CSV and checked for nib depth,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
    [c6remote-v2-pos.csv]
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2026-09-28 feat: add the idle deep-sleep bench build with page sleep settings and a restart action, open temporary Wi-Fi on pairing boots, confirm every pairing restart, keep a pairing request only through its 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
    [c6remote.yaml, idle_sleep.cpp, preview-buttons-page.py]
2026-09-28 feat(case): run the front skirt stiffener round the grip end and up to the cavity ceiling, stop the end screw block at the grip corner tangent, and trim both pad lobes to the stiffened wall with chec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
    [cli.py, features.py, hardware.py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]
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2026-09-29 feat: raise the amber Wi-Fi pulse floor to 112 so its trough never corrects to pure red, put the pairing line beside the pair button, and move the Zigbee2MQTT link line under the address and token fi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
    [c6remote.yaml, test_button_config.py]
2026-09-29 feat: show the friendly name as the /buttons page title with a Rename control that saves it to flash and applies it to Home Assistant and mDNS while the hostname stays fixed, and restore the YAML nam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
    [preview-buttons-page.py, test_button_config.py]
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
